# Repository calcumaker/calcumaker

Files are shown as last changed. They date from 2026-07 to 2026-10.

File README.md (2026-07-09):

# Calcumaker 16



> Repo: `calcumaker` · Product: **Calcumaker 16** (see [`NAMING.md`](NAMING.md))

A wide-format, full-size **Cherry MX** **programmer's / technical RPN
calculator**. It carries the HP-16C tradition — hexadecimal / octal / binary /
decimal entry, bitwise operators, and selectable word sizes — and extends it far
past what any single Voyager could do, with **arbitrary-precision** math: **GNU
MP** for big integers, **MPFR** for correctly-rounded floating-point and
transcendentals, and **MPC** for complex numbers. The 16C is the grounding
default (a faithful programmer's machine — `√-1` is `Error 0`, just like the
real one); switchable **personalities** (16C / 15C / SCI / FIN) and a SETUP menu
turn on the scientific and complex features on top. The top of the RPN stack is
shown live on a **multi-row 7-segment display** (2–3 rows) that mounts on its
**own angled PCB**. Battery + USB-C powered; a low-power STM32 keeps it alive
between keystrokes.

> Real keyswitches, a real stack you can see, and answers that are correct to as
> many digits as you ask for.

## Features

- **Programmer's RPN core (HP-16C lineage):** HEX/DEC/OCT/BIN modes, bitwise and
  shift/rotate ops, selectable word size, two's-complement / unsigned / one's-
  complement integer modes.
- **Arbitrary precision (single math path — no fallback):**
  - **GNU MP (libgmp)** — unbounded integers (huge hex/decimal, exact bitwise).
  - **MPFR (libmpfr)** — correctly-rounded floating point + transcendentals
    (sin/cos/exp/ln/…) at user-selectable precision.
  - **MPC (libmpc)** — arbitrary-precision **complex numbers** (HP-42S/15C model:
    one stack object, rectangular `a+bi` or polar `r∠θ`, complex-aware functions,
    CPXRES auto-promotion so `√-4 → 2i`). Off on the 16C, on for the scientific
    personalities and toggleable in SETUP.
  - Packaged as the **`calcumaker-core`** library (`no_std`) over our own
    **`gmp-mpfr-nostd`** FFI bindings — host-testable and runnable today
    (`cargo test`, `cargo run --example repl`).
- **Switchable personalities:** **16C** (programmer, the grounding default),
  **15C** (advanced scientific — the one that natively had complex), **SCI**
  (general scientific), **FIN** (HP-12C-style financial) — one keyboard, chosen
  in SETUP, each just a keymap + defaults over the same superset engine.
- **Field updates over USB-C:** flash new firmware with `dfu-util` via the STM32
  ROM DFU bootloader (`make dfu`) — no ST-Link needed; BOOT0 is the backup.
- **Host emulator:** `calcumaker-emu` runs the whole device UI — keymap, f/g
  shifts, digit entry, the multi-row 7-seg display rendered from the real
  TM1640 segment bytes — on a standard terminal (`cargo run`).
- **Visible RPN stack:** multi-row 7-segment display (2–3 rows) shows the top of
  the stack at once.
- **Split design:** the display lives on its **own PCB** that angles upward;
  only power, the display serial bus, and optional aux-display I²C cross the FFC
  to the MCU board — which keeps wiring simple.
- **Full-size Cherry MX keyswitches:** a wide, tactile, technical-use keypad.
- **Battery + USB-C:** 1S Li-ion with USB-C charging + buck-boost rail; aggressive
  sleep between keypresses for long runtime.
- **Rust firmware:** `no_std` main loop on the **STM32U575RGT6** (Cortex-M33,
  1 MB / 768 KB, ULP — see `DESIGN.md`).

## Hardware Stack

Calcumaker 16 is a three-board KiCad 10 design:

- **`calcumaker-mcu`** is the bottom brain/PSU board: STM32U575, USB-C power and
  charging, the 3V3 rail, the gated 5V display rail, SWD, clocking, the display
  FFC connector, and the keyboard mezzanine.
- **`calcumaker-keyboard`** is the top/front-panel board: 49 Cherry MX keys (a 2U ENTER),
  per-key diodes, annunciator LEDs, and a small STM32G0 keyboard scanner that
  reports key events to the U575 instead of routing the raw matrix across the
  stack.
- **`calcumaker-display`** is the angled display board: three repeated 16-digit
  7-segment rows driven by TM1640s, plus the display FFC and optional aux OLED
  socket.

The schematics are generated from per-board manifests under `hardware/scripts/`
and then placed/wired in KiCad. The display board uses a fully wired
multi-channel row sheet; the MCU and keyboard boards carry the generated sheet
structure plus on-canvas wiring notes. See [`hardware/README.md`](hardware/README.md)
and [`DESIGN.md`](DESIGN.md) for the current hardware source of truth.

## Architecture

```
   DISPLAY BOARD (calcumaker-display) — angled, cabled to the MCU board
   ┌──────────────────────────────────────────────────┐
   │  7-segment RPN stack: 3 rows × 16 digits (2–3 on) │
   │   48× FJ5161AH 0.56" single-digit CC (THT)        │
   │   3× TM1640 driver (1 per row, 2-wire bus)        │
   └──────────────────────────────────────────────────┘
       │ 12-position 0.5mm FFC: +5V, GND, CLK + DIN×3
       │ (5V logic) + 3V3/I²C for the aux OLED — cables down to the MCU board
       ╧
   KEYBOARD BOARD (calcumaker-keyboard) — TOP of stack, keys face up
   ┌──────────────────────────────────────────────────┐
   │  full-size Cherry MX key matrix (+ per-key diode) │
   │  STM32G0 scanner + annunciator LEDs (f g C G lo-b)│
   └──────────────────────┬┬──────────────────────────┘
     low-profile Hirose DF40 mezzanine (0.4mm, 1.5mm stack) + standoffs
        ││  I²C + UART + KB_IRQ (wake) + 3V3/GND  (matrix stays on the G0)
   MCU BOARD (calcumaker-mcu) — BOTTOM of stack
   ┌──────────────────────┴┴──────────────────────────┐
   │  EN-gated 5V boost ──► display │ 74HCT125 (3V3→5V)│
   │   ┌───────────────────────────────────────────┐   │  USB-C ── console /
   │   │ STM32U575RGT6 (Cortex-M33, 1MB/768KB, ULP) │   │          provisioning
   │   │  Rust no_std main loop (embassy)           │   │
   │   │   calcumaker-core: RPN engine              │   │
   │   │        └ GMP + MPFR  (single path)         │   │
   │   │   heap: embedded-alloc (TLSF)              │   │
   │   └────────────────────────────────────────────┘   │
   └───────┬───────────────────────────────────────────┘
           │ VSYS
   1S Li-ion ── USB-C charger ── load-share ── VSYS ──┬── buck-boost → 3V3 (MCU, ULP)
                                                      └── 5V boost (EN-gated) → display
```

## Firmware Stack

The firmware is deliberately split so there is one calculator and multiple thin
I/O bindings around it:

```
   host terminal                         STM32U575 firmware
   ┌─────────────────────┐               ┌─────────────────────┐
   │ calcumaker-emu      │               │ calcumaker-fw       │
   │ crossterm UI        │               │ no_std / embassy    │
   │ host keys + ASCII   │               │ keyboard link +     │
   │ 7-seg rendering     │               │ TM1640 bus + heap   │
   └──────────┬──────────┘               └──────────┬──────────┘
              │                                     │
              └──────────────┬──────────────────────┘
                             │
                    ┌────────▼────────┐
                    │ calcumaker-core │
                    │ Calc + App +    │
                    │ keys + seg7     │
                    └────────┬────────┘
                             │
                    ┌────────▼────────┐
                    │ gmp-mpfr-nostd  │
                    │ Integer + Float │
                    └────────┬────────┘
                             │
          host system GMP/MPFR or target cross-built GMP/MPFR
```

- **`gmp-mpfr-nostd`** is the math FFI layer: `no_std` + `alloc` wrappers for
  GMP integers and MPFR floats. On the host it links system/Homebrew GMP+MPFR;
  on the MCU it links the cross-built static libraries.
- **`calcumaker-core`** is the calculator: RPN stack, exact integer/programmer
  operations, MPFR real math, modes, keymap and f/g shift layers, entry editing,
  errors, and TM1640 7-segment byte generation. This crate is the single numeric
  path: no `rug`, no `std`, no pure-Rust fallback.
- **`calcumaker-emu`** runs the same `App` on a desktop terminal. It maps host
  keys to the physical matrix and renders the real segment bytes as 7-segment
  art, so scripted examples exercise the same key handling and display pipeline
  the device uses.
- **`calcumaker-fw`** is the U575 board binding: heap setup, power/display
  bring-up, keyboard event intake, and the TM1640 bus. The keyboard board's G0
  firmware owns matrix scan, debounce, wake/IRQ, and annunciator drive; the U575
  consumes `(row,col)` key events and feeds them to `calcumaker_core::App`.

Useful firmware entry points:

```sh
cd firmware/calcumaker-core
cargo test
cargo run --example repl

cd ../calcumaker-emu
cargo run
cargo run -- --press "2;3+"

cd ../..
firmware/scripts/build-gmp-mpfr-arm.sh
```

Host engine tests, the token REPL, and the terminal emulator work today against
the real GMP/MPFR libraries. The target GMP/MPFR build is cross-built and
link-verified; remaining firmware work is MCU/HAL bring-up, newlib/libm link
cleanup, heap routing for GMP allocations, and the keyboard-G0 firmware.

## Repository Structure

```
calcumaker/
├── hardware/                     # PCB design (KiCad 10) — split, three boards
│   ├── lib/                      # project-specific symbols/footprints/3D (shared)
│   │   ├── symbols/ footprints.pretty/ 3dmodels/
│   ├── calcumaker-mcu/           # MCU board (brain/PSU): MCU + PSU + clock + SWD + display-IF + keyboard mezzanine
│   │   ├── calcumaker-mcu.kicad_pro
│   │   ├── (root + mcu / clock / prog / psu / display_if / keyboard_if sub-sheets — generated)
│   │   ├── sym-lib-table · fp-lib-table
│   ├── calcumaker-keyboard/      # keyboard board (stacks above MCU): Cherry MX matrix + annunciators + MCU mezzanine
│   │   ├── calcumaker-keyboard.kicad_pro
│   │   ├── (root + keypad / annunc / main_if sub-sheets — generated)
│   │   ├── sym-lib-table · fp-lib-table
│   ├── calcumaker-display/       # display board (angled, cabled): 7-seg stack + driver + interconnect
│   │   ├── calcumaker-display.kicad_pro
│   │   ├── (root + display_row ×3 / interconnect / aux sub-sheets — generated)
│   │   ├── sym-lib-table · fp-lib-table
│   ├── scripts/                  # schgen engine + per-board manifests, check/render, JLCPCB
│   ├── Makefile                  # PROJECTS = calcumaker-mcu calcumaker-keyboard calcumaker-display
│   ├── LICENSE                   # CERN-OHL-S v2 (hardware)
│   ├── README.md
│   ├── sym-lib-table
│   └── fp-lib-table
├── firmware/
│   ├── gmp-mpfr-nostd/           # own no_std FFI to GMP/MPFR ("rug, but no_std")
│   ├── calcumaker-core/          # the CALCULATOR: engine + keymap + App + 7-seg
│   │   ├── src/                  #   lib, calc, value, format, keys, app, seg7
│   │   ├── tests/ · examples/repl.rs
│   │   └── Cargo.toml            #   single math path (no fallback)
│   ├── calcumaker-emu/           # HOST EMULATOR: the same App on a terminal
│   ├── calcumaker-fw/            # Rust no_std board binary (STM32U575 / embassy)
│   │   ├── Cargo.toml · .cargo/config.toml
│   │   ├── memory.x · build.rs · rust-toolchain.toml
│   │   └── src/                  #   main, keyboard input/link, display (TM1640 bus)
│   ├── scripts/                  # build-gmp-mpfr-arm.sh (cross-build for thumbv8m)
│   ├── common/                   # shared HAL/utilities
│   └── shared/                   # shared protocol/definitions
├── reference/                    # datasheets + dependency pointers
├── DESIGN.md                     # full hardware/firmware design + open questions
├── NAMING.md                     # product naming (Calcumaker 16)
└── LICENSE                       # AGPL-3.0 (firmware)
```

## Key Components

| Component | Part | Status |
|---|---|---|
| MCU | STM32U575RGT6 (1MB/768KB, M33, ULP, LQFP-64) | ✅ selected — LCSC C5270980, JLCPCB Extended |
| Display | 3 rows × 16 digits: 3× TM1640 + 48× FJ5161AH 0.56" CC (THT) | ✅ LCSC C5337152 / C8093 |
| Keys | 5×10 grid, 49 full-size Cherry MX (2U double-height ENTER) + keyboard STM32G0 scanner | electrical/keymap decided; physical layout details still TBD |
| Display interconnect | 12-position 0.5mm FFC: +5V/GND, CLK + DIN×3, 3V3/I²C aux lines | selected in `DESIGN.md`; verify cable length/orientation at layout |
| Power | 1S Li-ion + USB-C charge; **3V3 (TPS63900, MCU)** + **EN-gated 5V boost (display)** | 3V3 ✅; 5V boost + 74HCT125 level shifter TBD (research) |
| Math | GNU MP + MPFR via `calcumaker-core` + own `gmp-mpfr-nostd` (single path) | ✅ no_std, host-tested + REPL + emulator; cross-built + link-verified for the target |

## Status

**The calculator works on the host today**: engine + keymap + display pipeline
are host-tested, and `calcumaker-emu` runs the full device UI on a terminal.
GMP/MPFR are cross-built + link-verified for the STM32 target. **MCU, keypad
layout (5×10), software stack, display BOM, and power architecture are decided** (see
`DESIGN.md` / `hardware/PARTS.md`). The three-board hardware split is in the
repo; the display board is fully wired as a multi-channel KiCad design, while
the MCU and keyboard boards generate from their manifests and still need
eeschema wiring/layout work. Remaining firmware work: U575 MCU bring-up
(embassy + newlib/libm link + heap routing) and the keyboard-G0 scanner
firmware. Battery sizing and fabrication are still ahead.

## License

- **Firmware:** [AGPL-3.0](LICENSE) (compatible with the LGPLv3 GMP/MPFR).
- **Hardware:** [CERN-OHL-S v2](hardware/LICENSE) (strongly reciprocal — matches
  the AGPL copyleft posture).

Copyright (c) 2026 calcumaker authors.

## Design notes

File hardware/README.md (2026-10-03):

# Calcumaker 16 — hardware

KiCad 10 design for the **Calcumaker 16** programmer's / technical RPN
calculator. **Split design** — two stacked PCBs and one of two cabled display variants:

- **`calcumaker-mcu/`** — the brain/PSU board: MCU (STM32U575RGT6), PSU (USB-C
  charge + buck-boost), clock, SWD, the display interconnect (its 5V rail and
  level shifter live on the display module), and a mezzanine to the keyboard. *Bottom of
  the stack.*
- **`calcumaker-keyboard/`** — the front-panel board: the 49-key Cherry MX matrix (2U ENTER)
  + per-key diodes + the annunciator LEDs + the mating mezzanine header.
  *Mezzanine-stacks directly above the MCU board* (keeps a dense LQFP-64 off the
  through-hole key matrix).
- **`calcumaker-display/`** — the multi-row 7-segment RPN stack (2–3 rows) + its
  driver ICs + the interconnect back to the MCU board. Mounts at an upward angle,
  cabled; power, the display serial bus, and optional aux-display I2C cross the
  FFC.
- **`calcumaker-matrix/`** — alternative 96 × 24 addressable-pixel display with
  RP2040 control, USB programming and a dedicated LED power inlet.

See `../DESIGN.md` for the full design and `scripts/README.md` for the
schematic-generation flow. Build docs/BOMs/fab packages with the `Makefile`
(`make help`).

The MCU and keyboard schematics are wired and verified with KiCad 10.0.6.
Run `make check-wiring` for electrical net assertions and ERC validation.
See [WIRING_REVIEW.md](WIRING_REVIEW.md) for the pin maps, reviewed ERC warning,
power corrections, and remaining physical validation. Edit the schematics
directly; forcing the older placement manifests would discard this wiring.

The MCU board also has a [provisional PCB floor plan](calcumaker-mcu/FLOORPLAN.md):
75 placed components in functional groups, local supply bypasses, and a 70 × 50 mm
outline for the cabled configuration. It is unrouted; the placement review records
the remaining mechanical and fabrication-rule decisions.

The keyboard has a [PCB and mechanical plate floor plan](calcumaker-keyboard/FLOORPLAN.md)
with 49 key-cell groups, local RGB bypasses, a centered vertical 2U ENTER and
dedicated `Plate.Cuts`, `Keycaps` and mechanical annotation layers. Run
`make keyboard-plate` to export the separate plate DXF and reference SVG.

Both display variants have grouped, unrouted floor plans:
[48-digit seven-segment](calcumaker-display/FLOORPLAN.md) and
[2,304-pixel matrix](calcumaker-matrix/FLOORPLAN.md). They include local bypasses,
mechanical viewing references and position CSVs. Run `make check-display-wiring`
to check every digit/pixel net and ERC, and `make display-mechanical` to export
window DXFs and reference SVGs. These are provisional mechanical envelopes;
the matrix power path and both boards' remaining part choices require qualification.
All four boards' edited schematics are authoritative over the older manifests.

## Library

`lib/{symbols,footprints.pretty,3dmodels}` holds project-specific parts (shared
by all boards, lib name `calcumaker`); most parts resolve to KiCad bundled
libraries.

## License — Hardware: CERN-OHL-S v2

The hardware (schematics, PCB layouts, and associated design files under
`hardware/`) is licensed under the **CERN Open Hardware Licence Version 2 —
Strongly Reciprocal** (`CERN-OHL-S-2.0`). Full text: [`LICENSE`](LICENSE).
Chosen to match the strong-copyleft posture of the AGPL-3.0 firmware.

**Third-party library parts** (vendored symbols / footprints / 3D models) carry their
own upstream licenses — CERN-OHL-P, MIT, and CC-BY-SA-4.0-with-exception — all of which
are compatible with incorporation into a CERN-OHL-S v2 design. Every one is indexed,
with its source and license, in **[`lib/ATTRIBUTIONS.md`](lib/ATTRIBUTIONS.md)**.

> Copyright (c) 2026 calcumaker authors.
>
> This source describes Open Hardware and is licensed under the CERN-OHL-S v2.
>
> You may redistribute and modify this source and make products using it under
> the terms of the CERN-OHL-S v2 (https://ohwr.org/cern_ohl_s_v2.txt).
>
> This source is distributed WITHOUT ANY EXPRESS OR IMPLIED WARRANTY, INCLUDING
> OF MERCHANTABILITY, SATISFACTORY QUALITY AND FITNESS FOR A PARTICULAR PURPOSE.
> Please see the CERN-OHL-S v2 for applicable conditions.
>
> Source location: https://github.com/calcumaker/calcumaker
>
> As per CERN-OHL-S v2 § 4, if you produce a device using this source, you
> should where practicable keep the above Source Location visible on the device.

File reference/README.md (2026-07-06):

# Reference Material

Pointers to source material and dependencies this project is built from.

## Repo skeleton
Modeled after the sibling BenchBits hardware+firmware repos:
- **`github/ephemerkey/`** — freshest scaffold (KiCad 10, `hardware/` + `scripts/`
  schematic-generation flow, `Makefile`, lib-tables, JLCPCB script, `DESIGN.md`
  style). Closest structural template.
- **`github/notchdeck/`**, **`github/tsumikoro/`** — the same hardware/firmware
  layout and `hardware/scripts/` tooling.

The firmware departs from those (which are C / Zephyr / ESPHome): calcumaker's
main loop is **Rust (no_std)**.

## Firmware dependencies (see DESIGN.md)
- **GNU MP (libgmp)** — arbitrary-precision integers (the HP-16C "programmer"
  side: big hex/dec/oct/bin, bitwise). https://gmplib.org/ (LGPLv3 / GPLv2 dual)
- **MPFR (libmpfr)** — arbitrary-precision floats with correct rounding (the
  scientific side: transcendentals). https://www.mpfr.org/ (LGPLv3)
- **Bindings: our own `firmware/gmp-mpfr-nostd/`** — thin `no_std` FFI to
  GMP/MPFR (*like `rug`, but no_std*). Host links system GMP/MPFR (`brew install
  gmp mpfr`); target links cross-built. **Single math path — no pure-Rust
  fallback, no `rug`/`std` in the engine.**
- For the target: cross-built GMP/MPFR (`--host=arm-none-eabi --disable-assembly`
  + picolibc); see DESIGN.md → "GMP/MPFR on the target".
- Embedded Rust: **embassy-stm32** (async HAL), **cortex-m** / **cortex-m-rt**,
  **embedded-alloc** (heap for the bignum allocator), **probe-rs** (flash/debug).

## Datasheets (download into this folder via the `digikey`/`datasheets` skills)
Populate as the layout moves toward fabrication. Current expected set:

| Block | Part | Notes |
|---|---|---|
| MCU | STM32U575RGT6 (LCSC C5270980) | flash/RAM, low-power modes, USB FS, FPU, AF map, SRAM banking |
| Keyboard scanner | STM32G031K8U6 (LCSC C432207) | GPIO, Stop/EXTI wake, I2C/UART, package |
| Display driver | TM1640 (LCSC C5337152) | digit/segment drive, current set, 2-wire interface |
| 7-seg display | FJ5161AH (LCSC C8093) | 0.56 in single-digit common-cathode THT, pinout |
| Display FFC | AFC01-S12FCA-00 + GCT FFC05-TIN cable | 0.5 mm 12-position connector/cable orientation and current |
| Keyboard mezzanine | Hirose DF40C-10DS/DP-0.4V | stack height, land pattern, 3D clearance |
| Keyswitch | Cherry MX (full size) | mechanical/electrical, hot-swap socket option |
| Power | USB-C charger, TPS63900 3V3, TPS61022 5V boost, SN74HCT125 level shifter | charge current, Iq, input range, boost sizing, logic thresholds |
| Battery | 1S Li-ion/LiPo | capacity, protection |

> Use the `digikey`/`datasheets` skills to populate this folder, then the
> `kicad`/`emc`/`spice` analyzers can consume verified specs.

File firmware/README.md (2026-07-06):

# calcumaker firmware

Rust firmware for the Calcumaker 16 programmer's / technical RPN calculator.

## Layout

```
firmware/
├── gmp-mpfr-nostd/    # own no_std FFI bindings to GMP/MPFR (Integer + Float).
│   │                  #   "Like rug, but for a no_std world." Links system libs
│   │                  #   on host, cross-built libs on target.
│   └── src/           #   lib · ffi · integer · float
├── calcumaker-core/   # the CALCULATOR — everything device-independent:
│   │                  #   engine (RPN + arbitrary precision, SINGLE math path),
│   │                  #   keymap + f/g shift layers (keys), key handling +
│   │                  #   entry editing (App), 7-seg encoding (seg7).
│   ├── src/           #   lib · calc · value · format · keys · app · seg7
│   ├── tests/         #   engine + app + seg7 tests against real GMP/MPFR
│   └── examples/repl.rs
├── calcumaker-emu/    # HOST EMULATOR — the same App on a terminal; ASCII 7-seg
│   └── src/           #   rendered from the real TM1640 segment bytes.
├── calcumaker-fw/     # the embedded binary (Cortex-M33, no_std): board bring-up
│   └── src/           #   main · keyboard event intake · display (TM1640 bus)
├── scripts/           # build-gmp-mpfr-arm.sh — cross-build GMP+MPFR for thumbv8m
├── vendor/            # cross-built libgmp.a/libmpfr.a land here (gitignored)
├── common/            # shared HAL / board glue (reserved)
├── shared/            # shared protocol / definitions (reserved)
└── LICENSE            # (repo LICENSE is AGPL-3.0)
```

## The calculator is real and testable today

`calcumaker-core` uses **GNU MP + MPFR** through our own `no_std` bindings
(`gmp-mpfr-nostd`). On the host they link the system libraries, so it's a normal
library you develop and test on the desktop (builds in <1 s):

```bash
brew install gmp mpfr      # one-time host deps (apt: libgmp-dev libmpfr-dev)
cd calcumaker-core
cargo test                 # engine + app + 7-seg tests vs real GMP/MPFR
cargo run --example repl   # token RPN REPL against the engine
```

And the whole device UI runs on a terminal — see `calcumaker-emu/README.md`:

```bash
cd calcumaker-emu
cargo run                       # interactive emulator (? = key map)
cargo run -- --press "2;3+"     # scripted keys → prints the final frame
```

The core is `#![no_std]`; the *same* crate also compiles for the MCU
(`cargo build --target thumbv8m.main-none-eabihf`).

There is **one** numeric path — no `numeric-gmp`/`numeric-pure` feature split,
no pure-Rust fallback — and **one** UI path: firmware and emulator are thin I/O
bindings (keyboard events / host keys in, TM1640 bytes / ASCII art out) around
the same `App`.

## The embedded crate

`calcumaker-fw` is the U575 board binary: heap, power/display bring-up,
keyboard event intake from the keyboard-board STM32G0, and the TM1640 display
bus. It builds and links for `thumbv8m.main-none-eabihf` today (the default
target in its `.cargo/config.toml`).

GMP + MPFR are **cross-built + link-verified** for the target
(`scripts/build-gmp-mpfr-arm.sh` → `vendor/gmp-mpfr-arm/`; `build.rs` links
them when `GMP_MPFR_LIBDIR` is set). Remaining bring-up (tracked in
`../DESIGN.md`): embassy clocks/GPIO, newlib libc/libm at the final link, and
routing GMP's allocator to the firmware heap, plus the keyboard-G0 firmware and
link protocol. Then the main loop is exactly what the emulator runs:
`app.press(row, col)` → `display.render(&app.seg_rows())`.

## License

AGPL-3.0 (see `../LICENSE`). GMP and MPFR are LGPLv3 — compatible.

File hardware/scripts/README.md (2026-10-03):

# hardware/scripts

Tooling for the calcumaker KiCad project (shared with the sibling BenchBits
repos). Driven via the `Makefile` (preferred) or run directly. All locate
`kicad-cli` via `$KICAD_CLI`, then `PATH`, then the macOS app bundle
(`/Applications/KiCad/KiCad.app/...`).

| Script | Make target | What it does |
|---|---|---|
| `<project>.schgen.py` | `make gen-<project>` | Regenerate the hierarchical schematic from a data manifest. |
| `kschgen.py` | — | Generic generation engine imported by the `*.schgen.py` manifests. |
| `kicad-sch-check.py` | `make check-<project>` | Sanity-check a schematic: component count, missing footprints, duplicate refs, ERC tally. Exits non-zero on a structural problem. |
| `check-wiring.py` | `make check-wiring` | Export MCU/keypad netlists; verify connector parity, matrix polarity, LED chain, MCU/power/debug nets and reviewed ERC results. Fails on unexpected ERC violations. |
| `check-display-wiring.py` | `make check-display-wiring` | Verify all 48 digits, 2,304 pixels, 288 pixel bypasses, supply separation, USB, host interface, boot/debug nets and reviewed ERC results. |
| `kicad-sch-render.sh` | `make render-<project>` | Render schematic sheet(s) to PNG for a quick visual review. |
| `jlcpcb-package.sh` | `make jlc-<project>` | Gerbers + drill + BOM + CPL → JLCPCB zip. |

## Generating a schematic from a manifest

**All four boards' committed schematics are now wired and authoritative.** The
manifests below retain the earlier placement draft; do not force regeneration
over the edited sheets. See [the wiring review](../WIRING_REVIEW.md).
Make targets use `uv run python` (`PYTHON_RUN` can override it).

`scripts/<project>.schgen.py` is **data**: it registers the symbol libraries the
board uses, lists the components per hierarchical sheet (ref / lib_id / value /
footprint / LCSC / MPN / ...), and adds a free-text wiring note per sheet. The
reusable logic lives in `kschgen.py`, which hand-authors KiCad-10 schematic files
(root sheet of hierarchical sheet symbols + one child `.kicad_sch` per block,
every part resolving to a real library symbol + footprint, `extends`-derived
symbols handled).

Calcumaker 16 is a **split design** — one manifest per board:
`calcumaker-mcu.schgen.py`, `calcumaker-keyboard.schgen.py`, and
`calcumaker-display.schgen.py`.

```sh
make gen-calcumaker-mcu        # rewrite the MCU-board sheets from its manifest
make check-calcumaker-keyboard # verify a board
make render-calcumaker-display # eyeball a board's sheets
```

The draft manifests produce components **placed, not wired** — laid out on a 100-mil grid with refs,
values, footprints and a per-sheet wiring note. Wiring is done afterwards in
eeschema (the notes are the spec). By default, re-running `gen` creates missing
sheets and keeps existing `.kicad_sch` files intact, reusing their UUIDs in
project metadata. Use `KSCHGEN_FORCE=1 make gen-<project>` only when you
intentionally want to rebuild generated sheets from the manifest.
Notes render in a fixed-width font; use `K.note_block()` and `K.pin_table()` in
manifests when writing pin maps or wiring tables that need alignment.

> **Status:** the manifests remain guarded drafts until the open layout/part
> checks are resolved. The display manifest and the keyboard **matrix + per-key
> RGB** are fully wired **multi-channel** designs (a reusable row instantiated
> N×); the rest of the MCU/keyboard sheets generate placed-not-wired structure +
> on-canvas wiring notes. They refuse to run unless `CALCUMAKER_SCHGEN_DRAFT_OK=1`
> is set; regenerating placed-not-wired boards also needs `KSCHGEN_FORCE=1`.

## Notes

- `kicad-sch-render.sh` converts SVG→PNG with the first available of
  `rsvg-convert` / `inkscape` / `cairosvg` / macOS `qlmanage`. Output goes to a
  temp dir (override with `$RENDER_OUT`); pass sheet name(s) to render a subset.
- `extends`-based library symbols draw correctly in eeschema but may render
  body-less via `kicad-cli` and show a benign `lib_symbol_mismatch` in ERC until
  first saved in eeschema (or **Tools → Update Symbols from Library**).

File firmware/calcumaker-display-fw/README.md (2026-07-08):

# calcumaker-display-fw

Firmware for the **7-segment display module** (`hardware/calcumaker-display`): an
**STM32G031K8U6** that is an SPI slave to the calculator's U575. It receives a
[`calcumaker-display-proto::DisplayFrame`](../calcumaker-display-proto) over the
unified connector, encodes the text rows to 7-seg bytes, and bit-bangs the 3
TM1640s (driven at 5 V through the on-board 74HCT125).

- Target: `thumbv6m-none-eabi` (STM32G031, Cortex-M0+). `embassy-stm32`.
- Build: `cargo build --release`. Flash: `cargo run --release` (probe-rs on the
  J3 SWD Tag-Connect). Dev logging over RTT: `--features dev`.

## Status — SCAFFOLD

Real: the TM1640 bit-bang driver (`tm1640.rs`) and the 7-seg render (`render.rs`).
Stubbed: **`recv_frame`** in `main.rs` — SPI1 slave + DMA of `WIRE_LEN` bytes;
currently returns a self-test frame. Pins in `main.rs` are placeholders — align
them with the wired `disp_mcu` schematic sheet. `render.rs` duplicates
`core::seg7`'s glyphs (so this crate needn't link the GMP-bearing engine); TODO:
split `core::seg7` into a shared crate.

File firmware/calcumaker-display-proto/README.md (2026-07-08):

# calcumaker-display-proto

The **display-module wire protocol** — the "display intent" frame the calculator's
U575 (`calcumaker-fw`) sends over SPI, and that each display module renders
locally:

- the 7-seg module (`calcumaker-display-fw`, STM32G031), and
- the RGB-matrix module (`calcumaker-matrix-fw`, RP2040).

`DisplayFrame` carries text rows + annunciator/mode flags + aux-OLED content — a
display-agnostic *intent*, not raw driver bytes — so one frame serves any display
and a new display is just a new module (no MCU-board change). Fixed-length wire
form (`WIRE_LEN`, magic + version + XOR checksum) so a slave can DMA a constant
transfer.

Pure `no_std`, **no dependencies**, host-testable: `cargo test`.

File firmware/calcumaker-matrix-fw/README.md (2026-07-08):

# calcumaker-matrix-fw

Firmware for the **RGB dot-matrix display module** (`hardware/calcumaker-matrix`):
an **RP2040** that is an SPI slave to the calculator's U575. It receives a
[`calcumaker-display-proto::DisplayFrame`](../calcumaker-display-proto) over the
unified connector, renders the text rows into a 96×24 pixel framebuffer, and
streams it to the 2304× XL-1010 (WS2812) array over 3 PIO-driven data chains.

- Target: `thumbv6m-none-eabi` (RP2040, Cortex-M0+). `embassy-rp`.
- Build: `cargo build --release`. Flash: `cargo run --release` (probe-rs/SWD) or
  drag-drop the UF2 over USB **BOOTSEL**.
- Dev logging over RTT: `--features dev`.

## Status — SCAFFOLD

Real: the framebuffer + 5×7 font blitter (`font.rs`) and the frame decode path.
Stubbed (the bring-up work):

- **`ws2812.rs`** — the PIO WS2812 driver (3 SMs + DMA, GRB, serpentine mapping)
  is a no-op `flush`. This is the headline task; the RP2040 was chosen *for* its
  PIO.
- **`recv_frame`** in `main.rs` — SPI0 slave + DMA of `WIRE_LEN` bytes; currently
  returns a self-test frame.

⚠ **Brightness cap is mandatory** — 2304 WS2812 at full white is many amps. VLED
comes from the dedicated VSYS inlet (J2) via the `LED_EN` gate; keep colours dim
and enforce a global current budget. Pins in `main.rs` are placeholders — align
them with the wired `rp2040`/`rgb_power` schematic sheets.

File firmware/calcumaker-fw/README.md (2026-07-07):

# calcumaker-fw

Rust **`no_std`** board firmware for the Calcumaker 16 MCU board
(`STM32U575RGT6`, Cortex-M33).

This crate is not the calculator engine. The calculator lives in
[`../calcumaker-core`](../calcumaker-core): RPN stack, GMP/MPFR math, keymap,
entry editing, modes, errors, and TM1640 segment-byte generation. This crate is
the hardware binding around that core: heap setup, MCU/HAL bring-up, keyboard
event intake from the keyboard-board G0, and the display bus.

## Modules

| Module | Role |
|---|---|
| `main.rs` | Heap init, GMP/MPFR C-alloc shim, and the async entry on embassy's **low-power executor**; runs the self-test then hands off to USB. |
| `clock.rs` | RCC config: 160 MHz SYSCLK (PLL1-R/HSI), 48 MHz USB (HSI48+CRS), LSI for the RTC. Shared by both boards. |
| `usb.rs` | USB OTG_FS **composite device**: CDC-ACM console wired to a live RPN REPL over `calcumaker_core`, + a HID keyboard that types the X value to the host. |
| `bootloader.rs` | Enter the STM32 ROM USB-DFU bootloader for field updates (option-byte boot pattern, see below). |
| `selftest.rs` | Golden-case engine self-test (see the validation target below). |
| `keypad.rs` | Provisional keyboard-event intake. The real matrix scan/debounce/IRQ lives on the keyboard board's STM32G0 firmware; the U575 consumes `(row,col)` events. |
| `display.rs` | TM1640 bus driver skeleton for the multi-row 7-segment display. |

## MCU bring-up (embassy-stm32)

The crate runs on `embassy-stm32` (async). Brought up and **validated on the
Nucleo-U575ZI-Q**:

- **Clocks** (`clock.rs`): 160 MHz SYSCLK, 48 MHz crystal-free USB clock (HSI48
  CRS-trimmed to the USB SOF), LSI enabled for the RTC.
- **USB** (`usb.rs`): an IAD composite device on OTG_FS (PA11/PA12,
  `vbus_detection=false`). Interface 0/1 = CDC-ACM, a full RPN REPL over the real
  engine (`2 3 +` → `5`, `float 2 sqrt` → 256-bit MPFR, `100 !` → the 158-digit
  factorial); interface 2 = a HID keyboard — the `type` command taps the current
  X value to the focused host app.
- **Low power**: uses embassy's low-power executor, so the part enters the
  deepest sleep the peripheral **stop-refcounts** allow when idle. USB OTG is
  `stop_mode=Stop1`, so while the console is enumerated it stays in Sleep (WFI,
  USB-safe) and wakes on USB activity; deeper STOP is only reached once USB is
  gated. **Deferred:** STOP2-with-timekeeping needs an RTC time driver that
  embassy-stm32 0.6 doesn't yet provide for the U5 (its LPTIM driver miscompiles
  against the current metapac), and a dedicated VBUS-EXTI wake-on-plug source —
  both revisited on an embassy bump / with the production board's VBUS routing.

## Calculator Core

There is one numeric path: **GNU MP + MPFR** through the repo's
`gmp-mpfr-nostd` crate. No `numeric-pure`/`numeric-gmp` feature split, no
pure-Rust fallback, and no `std`/`rug` in the engine.

On the host, `calcumaker-core` links system GMP/MPFR and is tested directly:

```bash
cd ../calcumaker-core
cargo test
cargo run --example repl
```

For the target, GMP/MPFR are cross-built out of tree and linked by this crate's
`build.rs` when `GMP_MPFR_LIBDIR` points at the install prefix:

```bash
cd ../..
firmware/scripts/build-gmp-mpfr-arm.sh
GMP_MPFR_LIBDIR=firmware/vendor/gmp-mpfr-arm \
  cargo build --manifest-path firmware/calcumaker-fw/Cargo.toml --target thumbv8m.main-none-eabihf
```

## Firmware update over USB-C (no ST-Link)

Field updates use the **STM32 ROM USB-DFU bootloader** — single flash slot (the
app owns `0x08000000`+), no custom bootloader, no A/B partitions.

```bash
make dfu     # build → enter ROM DFU → dfu-util flash → restore boot → app
```

How it works (`bootloader.rs` + `scripts/dfu-flash.sh`):
1. The app's **`dfu`** REPL command programs the boot option bytes
   (`nSWBOOT0=0, nBOOT0=0`) and sets `OBL_LAUNCH`, resetting straight into the
   ROM DFU device (`0483:df11`). *(A naive jump to system memory `0x0BF90000`
   HardFaults on the U5; the RM-defined boot-pattern entry is what works.)*
2. `dfu-util` writes the new firmware to internal flash (alt 0), then **rewrites
   the boot option bytes back** (`OPTR` → boot main flash, alt 1) — the same DFU
   session clears the flags it set — which resets into the new app.

Physical **BOOT0** high at reset reaches the same ROM DFU as a hardware backup.

`dfu-util` / `probe-rs` need USB access. Install the versioned udev rule once for
sudo-free access to the ST-Link, the ROM DFU (`0483:df11`), and the app:

```bash
sudo cp ../scripts/70-calcumaker.rules /etc/udev/rules.d/
sudo udevadm control --reload-rules && sudo udevadm trigger --subsystem-match=usb
```
(Without it, run `make dfu` with `DFU_UTIL="sudo dfu-util"`.)

## Nucleo-U575ZI-Q validation target

A permanent, non-production **validation target**: the same firmware, flashed to
an off-the-shelf **Nucleo-U575ZI-Q** (STM32U575ZIT6Q — a 2 MB/144-pin sibling of
the production RGT6). It has no keyboard matrix or display, so `main` runs the
shared engine **self-test** (`src/selftest.rs`) — golden RPN cases whose results
were captured from the host engine — and streams PASS/FAIL over **RTT (defmt)**
through the board's on-board ST-LINK-V3. This proves the cross-built on-target
GMP/MPFR reproduces the host results *byte-for-byte* (MPFR is deterministic at a
fixed precision/rounding), i.e. the whole arbitrary-precision stack computes
correctly on real U5 silicon.

Everything is shared with the production image. The `nucleo` cargo feature swaps
the panic handler (`panic-halt` → `panic-probe`), turns on the defmt result
logging (compiled out otherwise, via the `log_info!`/`log_error!` shim in
`main.rs`), and selects the ZI chip. The linker memory map comes from
embassy-stm32's `memory-x` per chip (RG = 1 MB, ZI = 2 MB), so only the chip
feature + flash-time `--chip` differ between the two boards.

After the self-test the Nucleo image brings up USB, so the board enumerates as a
composite CDC-ACM + HID keyboard device you can drive interactively (see *MCU
bring-up* above).

```bash
# from this crate dir (GMP_MPFR_LIBDIR defaults to ../vendor/gmp-mpfr-arm):
make run-nucleo     # build + flash + stream the self-test over RTT (Ctrl-C to detach)
make build-nucleo   # build only
make check-nucleo   # type-check the nucleo config
```

Requires `probe-rs >= 0.24` (decodes the defmt v4 wire format; **0.31** verified).
`make build` (default features) still produces the production RGT6 link-smoke
image with logging compiled out.

## Bring-Up Status

Done + validated on hardware (Nucleo-U575ZI-Q): the full GMP/MPFR engine
cross-compiles/links and computes correctly on-target, 160 MHz clocks, the USB
composite (CDC-ACM REPL + HID keyboard), and low-power-executor Sleep with
USB-gated STOP.

Remaining board bring-up: the keyboard-G0 link protocol (matrix `(row,col)`
intake), the real TM1640 bit-bang display driver, routing GMP allocations
through `mp_set_memory_functions` (vs. the current global-heap malloc shim),
deep STOP2 + VBUS wake (see *MCU bring-up* deferrals), and moving the engine off
the USB REPL onto the shared `App`. See [`../../DESIGN.md`](../../DESIGN.md) for
the full firmware checklist.

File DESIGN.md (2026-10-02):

# Calcumaker 16 — Design Document

> Repo: `calcumaker` · Product: **Calcumaker 16** (see `NAMING.md`).
> Future personalities / HP-variant modes are **planned** (not implemented)
> in [`DESIGN-MODES.md`](DESIGN-MODES.md).

## Overview

**Schematic status (2026-10-02):** the MCU and keyboard boards are now wired,
including sheet connections, power, reset/debug and the 49-key/RGB chain.
The authoritative pin map, corrections and validation results are recorded in
[`hardware/WIRING_REVIEW.md`](hardware/WIRING_REVIEW.md). Run
`make -C hardware check-wiring`. The committed schematics supersede the guarded
placement manifests; do not force regeneration. PCB layout, RGB voltage/logic
headroom and final cell/connector/inductor selection remain open.

Calcumaker 16 is a wide-format, full-size **Cherry MX** **programmer's /
technical RPN calculator**. It follows the **HP-16C** lineage — hexadecimal /
octal / binary / decimal entry, bitwise and shift/rotate operators, and
selectable word sizes — and extends it with **arbitrary-precision** math:

- **GNU MP (libgmp)** for unbounded integers (the programmer side: huge
  hex/decimal values, exact bitwise);
- **MPFR (libmpfr)** for correctly-rounded floating point and transcendental
  functions (the scientific side), at user-selectable precision.

The top of the RPN stack is shown on a **multi-row 7-segment** display (**2–3
rows**) carried on its **own angled PCB** — part of a **three-board split**
(MCU board + keyboard board stacked on a mezzanine, + the angled display board);
only power and the display serial bus cross that interconnect. The device is
**battery + USB-C** powered, on the **low-power STM32U575**. The firmware main
loop is **Rust (`no_std`)**.

This document is the source of truth for the hardware and firmware design. It
follows the structure of the sibling BenchBits repos (ephemerkey / notchdeck /
tsumikoro). The repo's firmware departs from those (which are C / Zephyr) by
being Rust.

---

## Resolved Decisions (from project kickoff)

| # | Decision | Choice |
|---|---|---|
| 1 | Math stack | **GMP + MPFR only — single path, no fallback.** Engine = `calcumaker-core` over our own no_std bindings `gmp-mpfr-nostd` (host: links system GMP/MPFR; target: cross-built). One `no_std` crate, host-tested + REPL. |
| 2 | Power | **1S Li-ion + USB-C charging + buck-boost**; "low power" = long battery life via aggressive sleep between keystrokes. Charger = **BQ25601** (3 A sync buck + NVDC power path, I²C) with the **Type-C CC advertisement read on an ADC** → up to **3 A** in (revised 2026-07-12 from MCP73831 + discrete load-share). |
| 3 | Display | **Stacked RPN registers, 2–3 rows (option)** — multi-row 7-segment showing the top of the stack. Driver + digit parts chosen by LCSC price/availability. |
| 4 | Keypad | **Wide HP-16C-style layout** for programming / technical / engineering use; full-size Cherry MX. |
| 5 | Firmware language | **Rust, `no_std`** main loop (async via embassy once MCU is pinned). |
| 6 | Firmware license | **AGPL-3.0** (repo LICENSE) — compatible with LGPLv3 GMP/MPFR. |
| 7 | MCU | **STM32U575RGT6** (Cortex-M33, **1 MB** / 768 KB, **LQFP-64**, ULP) + **4 MB quad-SPI NOR on OCTOSPI1**. Firmware measured ~323 KB → 1 MB is ample; the matrix scans off-board so LQFP-64 has enough GPIO (smaller/cheaper). Same U575 die (USB FS, OCTOSPI, GMP/MPFR-capable). LCSC C5270980. Target `thumbv8m.main-none-eabihf`. |
| 8 | Board partition | **Three boards: `calcumaker-mcu` + `calcumaker-keyboard` (DF40 mezzanine-stacked above it) + `calcumaker-display` (angled, 0.5 mm FFC).** Keeps a dense LQFP-64 off the 49-key through-hole matrix. The keyboard has its **own STM32G0 scanner**, so only an **I²C+UART link + power** cross the mezzanine (not the raw matrix); the display bus + power cross the FFC. |
| 9 | Hardware license | **CERN-OHL-S v2** (`hardware/LICENSE`) — strongly reciprocal, matches the AGPL copyleft posture. |
| 10 | Product name | **Calcumaker 16** (see `NAMING.md`). |

---

## Architecture Decisions

### MCU: large-flash / low-power STM32 (Cortex-M4F or M33)

The dominant sizing driver is the arbitrary-precision math. GMP + MPFR together
are on the order of **~0.5–1 MB of flash**, but their heap needs are **modest**
for a calculator — even very high working precision is a few KB per value, so a
4-level stack plus registers and MPFR scratch is comfortably in the **tens of
KB**. So the real constraint is **flash ≥ ~1–2 MB** (to keep the real GMP/MPFR
option open); **~128–320 KB RAM is plenty**. An FPU helps the (mostly software)
multi-precision arithmetic at the margins and is standard on the candidates.
Low power and a USB FS device (console / provisioning) round out the list.

> **Cost matters — this is a calculator, not a workstation.** The 4 MB / 3 MB
> top-end U5 (U5G9) is far more part than this needs and is expensive; it has
> been dropped as the headline pick.

**SELECTED: STM32U575RGT6 (Cortex-M33, 1 MB flash / 768 KB SRAM, LQFP-64, ULP),
plus a 4 MB quad-SPI NOR on OCTOSPI1.** Same U575 die (FPU + USB FS + OCTOSPI +
TrustZone, ST's current ULP line), chosen on **availability + fit**: the L4R5 is
effectively unavailable (~5 pcs), while the U575 family is well stocked and
GMP/MPFR-capable. The **firmware links at ~323 KB** (full engine + GMP + MPFR,
*measured* — see Numeric core), so **1 MB flash is ample (~3× headroom)** — no
need for the pricier/scarcer 2 MB `I` parts. With the **key matrix scanned
off-board** (the keyboard G0), the MCU needs far fewer GPIO, so the smaller
**LQFP-64 (10×10 mm)** fits — cheaper and suited to the low-profile stack. A
**4 MB (32 Mbit) quad-SPI NOR** (W25Q32JVSSIQ, LCSC C179173) on **OCTOSPI1** adds
memory-mapped (XIP) storage for constant tables + state persistence / future
keystroke programs. Target `thumbv8m.main-none-eabihf`; HAL `embassy-stm32`
(`stm32u575rg`).

> **Flash-code gotcha:** the STM32 `G` size code = **1 MB** (the `I` parts are
> 2 MB). Earlier notes mislabeled the ZGT6 as "2 MB"; the ZGT6/VGT6/RGT6 are all
> **1 MB** — which the measured 323 KB firmware fits with room to spare.

**Availability ladder (live LCSC/JLCPCB via jlcsearch; all JLCPCB "Extended"):**

| Part | LCSC# | Pkg | Flash / RAM | Stock | Fit |
|---|---|-----|---|---|-----|
| **STM32U575RGT6** | C5270980 | LQFP-64 (10×10) | 1 MB / 768 KB | 345 | ✅ selected — smaller pkg, matrix off-board |
| STM32U575VGT6 | C5270988 | LQFP-100 (14×14) | 1 MB / 768 KB | 17k | best-stocked U575 — drop-in if more GPIO wanted |
| STM32U575ZGT6 | C5271004 | LQFP-144 (20×20) | 1 MB / 768 KB | 230 | prior pick (oversized once the matrix left) |
| STM32L4R5ZIT6 | C1339786 | LQFP-144 | 2 MB / 640 KB | 5 | GMP-capable but ~unstocked → no-go |
| STM32U575RIT6 | C5270992 | LQFP-64 | 2 MB / 768 KB | 26 | the `I`/2 MB variant if ever needed — thin stock |

> Other L4R5 packages (LQFP-100 VIT6, UFBGA QIY6) returned **no LCSC listing**.
> Stock/price are point-in-time (fetched during scaffolding); re-check at order.

Considerations once pinned:
- **SRAM may be banked** (esp. on U5). For a single contiguous heap, use the
  largest contiguous span or place the heap section explicitly.
- **External memory:** internal RAM is ample, but a **4 MB quad-SPI NOR is now
  fitted on OCTOSPI1** (U7, `QSPIFlash` sheet) for memory-mapped constants +
  state/program storage (not for RAM).
- **USB FS** for a CDC console / provisioning + firmware update.

### Board partition: three boards (MCU + keyboard stacked, display cabled)

Calcumaker 16 is **three PCBs** (revised 2026-07-05 — the keyboard split off the
MCU board):

- **`calcumaker-mcu`** — the brain/PSU board: MCU (U575), PSU, clock, SWD, the
  display 5 V rail + level shifter + interconnect, and a **keyboard mezzanine**
  (J5). This is the dense fine-pitch SMT board (LQFP-64). *Bottom of the stack.*
- **`calcumaker-keyboard`** — the front-panel board: the 49-key Cherry MX matrix (2U ENTER)
  + per-key diodes + the annunciator LEDs + the mating **mezzanine header** (J1).
  A simple 2-layer through-hole board. *Stacks directly above the MCU board.*

  **The 2U ENTER.** ENTER is a **double-height (2U) keycap**, like every HP
  Voyager. It occupies two cells of the 5×10 grid — rows 3 and 4 of column 5
  (0-based) — but has a **single switch**, wired to the **lower cell's row line**
  (`KB_ROW5` × `COL6`), so ENTER keeps its matrix position and the firmware scan
  is unchanged. The other cell gets **no switch, diode, or RGB LED**: the grid is
  50 cells but the board is **49 keys / 49 LEDs**.

  *Physical placement (≠ the logical cell).* A 2U keycap's stem is **centered on
  the key**, so the switch body — and its RGB LED, which shines up through the
  switch's north window — sits on the **boundary between the two rows**, i.e.
  9.525 mm (½U) from either 1U cell center, at the column-5 x. The row/col
  assignment above is a *net* assignment, not a coordinate; the layout must place
  this one switch off the 1U grid.

  **Stabilizer.** A 2U key wants a stabilizer or it rocks. Two options, and the
  choice decides whether the PCB changes at all:
  - **Plate-mount (recommended)** — the stab clips into the switch plate we
    already need for the hot-swap sockets. KiCad's `SW_Cherry_MX_2.00u_Vertical_Plate`
    has *exactly the same pads as the 1u plate footprint* — **no PCB holes**. So
    the existing `calcumaker:SW_MX_HS_CPG151101S11_1u` footprint is reused as-is
    for ENTER; only the plate cutout and the keycap change. Keep the area under
    the stab wire clear (our SK6812s are reverse-mounted on the bottom, so it is).
  - **PCB-mount** — needs four NPTH holes, symmetric about the switch center at
    **y = ±11.90 mm** (23.8 mm stab spacing), each wing a **3.05 mm** hole at
    x = −7.00 mm and a **4.00 mm** hole at x = +8.24 mm (15.24 mm apart). Stock
    `Button_Switch_Keyboard:SW_Cherry_MX_2.00u_Vertical_PCB` has this pattern but
    is **solder-in**, so the hot-swap 2U variant is **vendored** as
    `calcumaker:SW_MX_HS_CPG151101S11_2u_Vertical` (our 1u hot-swap footprint plus
    those four holes; its origin is already the switch center). Place-on-back is
    safe: mirroring X maps the stab-hole set onto itself rotated 180°, and a 2U key
    is symmetric. Choosing PCB-mount would **also** force a **Row5 variant sheet**,
    since ENTER's switch sits on the shared 10-key sheet and multi-channel instances
    must share footprints — another reason to prefer plate-mount.

  The stabilizer itself is **mechanical hardware** (Cherry/Durock 2U, plate- or
  PCB-mount), not a schematic symbol — it carries no net and appears only in the
  layout + the mechanical BOM.
  - Firmware: `keys.rs` marks that cell `Key::Absent` (≠ `Key::Nop`, a real key
    with no function) in every layer of every personality; `ENTER_SWITCH_CELL` /
    `ENTER_SPAN_CELL` / `cell_has_switch()` are the source of truth, pinned by the
    `enter_is_2u_in_every_personality` golden test.
  - Displaced functions (identical in all four personalities): **x⇄y** moves onto
    the base layer at (3,4) — it is core RPN and stays unshifted; the mode key it
    displaced there moves to **f+ENTER** (16C `WSIZE`, SCI/15C `ANGLE`, FIN `%T`);
    and **FLOAT** moves to **g+ENTER**.
  - PCB: the matrix is no longer five *identical* rows, so the multi-channel
    design instantiates the reusable 10-key sheet **four times** (Row1/2/3/5) and a
    dedicated **9-key variant sheet** (`key_row_9.kicad_sch`) once for **Row4**.
    Reference numbering keeps a hole (no `SW36` / `D36` / `D91`) rather than
    renumbering, and Row4's RGB daisy-chain closes over the gap (LED@COL5 → LED@COL7).
- **`calcumaker-display`** — the multi-row 7-segment stack + its driver ICs + the
  interconnect back to the MCU board. It **mounts at an upward angle** for
  readability, cabled (not stacked).

**Why split the keyboard off the MCU board:** laying a dense LQFP-64 (0.5 mm
pitch, needs careful fan-out / multiple layers) into the same board as 50
full-size through-hole keyswitches is a routing and mechanical fight. Splitting
gives each PCB an easy job — the MCU board is a compact SMT brain, the keyboard
is a plain switch matrix — and lets the keyboard be the physical top surface the
user types on while the MCU board hides underneath.

**Keyboard link — stack *or* cable (populate one).** Because the keyboard has its
**own STM32G0 scanner**, only a **serial link + power** cross to the MCU board,
not the raw matrix. The same 12 signals map to **two footprints on each board —
populate whichever the build needs**:

- **Stacked:** a **Hirose DF40, 0.4 mm, 2×6 (12-pin), ~1.5 mm** mezzanine —
  receptacle `J5` **DF40B-12DS-0.4V** (C3641147) on the MCU board, header `J1`
  **DF40C-12DP-0.4V** (C6224952) on the keyboard. Compact rigid sandwich.
- **Cabled:** a **16-pin 0.5 mm FFC** — `J6` (MCU) + `J3` (keyboard), both
  **AFC01-S16FCA-00** (C262665, same family as the display FFC). The flat cable
  lets the **MCU board mount anywhere in the case**, off the keyboard footprint.

**Why the cable option exists:** the DF40 stack is only ~1.5 mm (tallest DF40 is
4 mm), but the keyboard's **bottom is now crowded** — Kailh hot-swap sockets
(~1.8 mm), reverse-mount LEDs, switch bodies — so the MCU board (STM32U5 QFP + PSU)
has nowhere to sit stacked directly under the keys. The **FFC decouples its
position** and fixes that; the DF40 stays for anyone who wants the compact
sandwich. **The FFC is 16-pin so its cable can't cross-plug the 12-pin display
FFC** (and the extra pins give **VSYS ×2 + GND ×3** for the LED current, + 2 spare).

The 12 signals: `+3V3 · GND · I²C_SDA · I²C_SCL · UART_TX · UART_RX · KB_IRQ ·
KB_NRST · KB_BOOT0 · GND · VSYS · GND` — VSYS is the always-on battery/USB rail
feeding the keyboard's per-key RGB. I²C is the primary key/annunciator channel;
UART is spare/expansion + the G0's ROM bootloader; `KB_IRQ` is the keypress wake.

*Mechanical:* the **cabled** build mounts both boards to the enclosure
independently (like the display) — no clearance conflict, and the recommended
default given the crowded keyboard bottom. The **stacked** build needs the MCU
board under a keyless region (or trimmed MX/socket clearance), tall connectors
(USB-C ~3.2 mm, battery JST ~5 mm) at the board edge, and 4 corner standoffs.
(DF40C-12DS isn't LCSC-stocked so the receptacle is DF40B-12DS — still 1.5 mm: the
DF40 *suffix* sets stack height, not the B/C letter; taller DF40HC variants swap
on the same land. Verify all lands + 3D clearance at layout.)

### Per-key RGB accent lighting (keyboard)

Fifty **SK6812MINI-E** (LCSC **C5149201**, single-wire addressable RGB) —
**per-key backlight** that hints key positions / presses. It's a **reverse /
bottom-mount** part (KiCad `LED_SK6812MINI-E_3.2x2.8mm_P1.5mm_ReverseMount`): it
sits on the **bottom** of the PCB and shines **up through** a cutout into each MX
switch's north LED window. That puts the LEDs on the **same side as the Kailh
sockets → single-sided assembly** (one stencil, one reflow pass, no board flip —
cheaper JLC, and it's why we didn't use a top-emit part). All 50 daisy-chain
(DIN→DOUT) off **one G0 pin** (WS2812 protocol, ~800 kHz); refs `D56–D105`.

**Power = gated VSYS.** The LEDs are ~5 V parts and the keyboard rail is only
3.3 V, so they run off **VSYS** — the MCU board's battery/USB system rail —
brought up the **widened 12-pin mezzanine**. A **high-side P-FET load switch**
(Q1 AO3401A + Q2 2N7002) on the keyboard **gates the whole LED rail off in sleep**
(G0 `LED_EN` low → LEDs + level shifter dead, near-zero leakage) to protect
battery life. A **74LVC1G125** buffer powered from the *gated* rail level-shifts
the 3.3 V data up to the LED V_IH (0.7·V_DD).

> **⚠ Headroom shrank with the BQ25601 (2026-07-12) — needs a check before layout.**
> VSYS used to be the Schottky-OR'd rail (**~4.6 V whenever USB was plugged in**).
> It is now the charger's **NVDC `SYS`**, which tracks **≈VBAT with a 3.5 V floor**
> — so the USB case drops to **~4.2–4.4 V** and the worst case on a low cell is
> **3.5 V**. The SK6812MINI-E is specified from ~3.7 V, so **near-empty-battery
> LED behaviour is the open risk**. The *level shifting* is unaffected (the buffer
> runs off the same gated VSYS, so data-high = VSYS and the 0.7·V_DD ratio always
> holds — it's inherently ratiometric). What needs verifying is **LED brightness /
> colour fidelity at 3.5 V**. Mitigation is already in the plan: firmware caps
> total brightness and should **fade the backlight out on low battery** anyway.
> Battery-only operation is **unchanged** (VSYS ≈ VBAT, 3.0–4.2 V, same as before).

**Current budget:** 50× full-white ≈ 0.75 A would exceed the DF40 contact + VSYS
budget, so the firmware **must cap total brightness** — "hint" use lights a few
keys at a time (pressed key + neighbours), an all-keys idle glow stays dim.

### Hot-swap switches (place-on-back) — this is a hot-swap board

The keyswitches use marbastlib's **`SW_MX_HS_CPG151101S11_1u`** footprint (vendored,
CERN-OHL-P): the switch mount + the Kailh **CPG151101S11** hot-swap socket. It is a
**place-on-back** footprint — the switch footprints go on the board's **back copper
layer**, so the socket (authored on `F.Cu`) lands on the physical **bottom** and
the keycaps face up on the front.

**This is a hot-swap board.** The socket (LCSC **C41430893**, ~93k stock,
JLCPCB-assemblable) is populated on the bottom; switches **plug in**,
field-swappable. A **plate** holds the unsoldered switches (a separate mechanical
part). The socket protrudes ~1.8 mm below the PCB (enclosure/standoff detail).

> **Not solderable for a switch-only build.** The switch thru-holes are minimal
> **0.15 mm-ring pass-throughs** for the pin into the socket — **not** solder
> pads. So a switch-only / **solder-in build is not supported on this footprint**.
> A solder-in board would use the dedicated solder-in footprint
> (`SW_Cherry_MX_1.00u_PCB`, also vendored) — a **separate board revision**, not a
> BOM toggle on this one. (Earlier notes framed this as a one-board "combo" — that
> was wrong; the pass-throughs don't make a reliable solder joint.)

Wider keys (2u Enter, etc.) need **stabilizers** — marbastlib's `STAB_MX_2u` and
KiCad's own `SW_Cherry_MX_2.00u_PCB` already carry the stabilizer mounts — a
layout option for later.

Keeping the display driver *on the display board* means only **+5V, GND, and the
display serial bus** (a handful of signals) cross that connector — instead of
dozens of segment/digit lines — which is what **simplifies the display wiring**.

- **Display interconnect:** a **0.5 mm 12-conductor FFC** — connector
  **AFC01-S12FCA-00** (LCSC C262661) on both `calcumaker-mcu:J3` and every display
  board's `J1`; the flat-flex **cable is a non-assembled DigiKey accessory** —
  **GCT FFC05-TIN `05-12-A-<length>-A-4-06-4-T`**. It is now a **unified,
  technology-agnostic SPI "display-module" bus** (see the next section), pinout
  `1=VSYS, 2=VSYS, 3=GND, 4=GND, 5=+3V3, 6=SPI_SCLK, 7=SPI_MOSI, 8=SPI_CS,
  9=DISP_IRQ, 10=DISP_NRST, 11=DISP_BOOT, 12=GND` — **identical on both the 7-seg
  and RGB-matrix display boards, so they are interchangeable.** `mcu:J3` ↔
  `<display>:J1` must match; verify FFC contact orientation at layout. LED current
  for the RGB matrix does **not** cross this FFC — it takes a dedicated 2-pin VSYS
  lead (`mcu:J7` → matrix `J2`).

### Aux display: optional 128×32 OLED (the "DNP-optional aux" pattern)

**Errors and rich status on a digits-only machine** are handled in two layers:

1. **The glass is primary.** Errors show HP-16C-style codes — a transient
   `Error N` on the X row (`CalcError::code()`: 0 math domain · 1 register/
   flag · 2 bits/shift/word · 3 mode ranges · 4 too large · 5 no solution ·
   6 stack/entry · 7 dates · 8 statistics · 9 reserved for crash recovery).
   The calculator is **fully usable with no OLED**.
2. **The aux OLED is optional detail.** A 0.91″ SSD1306 128×32 I2C module on
   the **display board** (`AuxDisplay` sheet, J2 1×4 socket, **DNP by
   default**), hand-placed alongside the THT digits. Content is
   **`App::aux_lines()`** — 4 lines × 21 chars (6×8 font), ONE code path for
   the firmware panel and the emulator's mock panel: an optional
   **status-flags header** (personality/radix/angle/number-mode, then
   prec/word/sign/C/G/format/shift/pending-register — SETUP > `OLEd`
   FLAG/oFF, default on), followed by the error text (`CalcError::text()`)
   or the **full-precision X** when idle (the windowing helper). I2C runs at
   3V3 straight from the MCU across interconnect pins 8–10; pull-ups R14/R15
   (4.7 kΩ) sit on the MCU board, DNP with the OLED. Firmware sleeps the
   panel in idle (~10 µA).

**The pattern** (reusable): optional capability = a cheap socket/footprint on
the board, DNP by default, module hand-placed by builders who want it — the
base build's cost, power budget, and identity stay untouched, and the firmware
degrades gracefully (glass codes) when the part is absent.

### Display: multi-row 7-segment (RPN stack), 2–3 rows

A multi-row 7-segment array shows the **top of the RPN stack**, **3 rows × 16
digits**. The board is laid out for 3 rows with the **top row optionally
populated**, so it builds as a **2- or 3-row** display (firmware-configurable).
A 16-digit row holds a full 64-bit hex word, or a signed mantissa + exponent;
arbitrary-precision values that exceed the row width are **windowed / scrolled**.

**Selected by LCSC price/availability (research):**

- **Driver: TM1640** (LCSC C5337152, SOP-28, ~$0.12, deep stock). A 2-wire bus
  drives **16 common-cathode digits per chip = one full row**, so **3 chips**
  cover 3 rows (vs ~6 MAX7219 at ~20× the cost). Shared CLK + one DIN per chip.
  Display-only (keys live on the keyboard board). TM1638 (C19187) is the drop-in if
  on-chip key-scan is ever wanted.
- **Digits: FJ5161AH** (LCSC C8093, 0.56" **single-digit common-cathode**, ~$0.10)
  — **16 per row → 48 digits** total. FJ5161AH is a *one-digit* part (confirmed on
  LCSC), so a row is 16 discrete digits, not a 4-up module — which gives even,
  continuous digit spacing across the 16-digit number. Common-cathode matches the
  TM1640: segments a–g,dp tie to the shared **SEG1–8** bus; each digit's cathode
  goes to one of **GRID1–16**.
- **⚠ Through-hole digits.** No SMD multi-digit 7-segment displays are stocked on
  LCSC — the well-stocked parts are THT. So `calcumaker-display` needs **THT
  assembly** (JLCPCB through-hole add-on, or hand/wave solder); the TM1640s are
  SMT. See `hardware/PARTS.md`.
- **Power note:** LED 7-segment is the dominant active current draw, *not* the
  MCU — and it's drawn from +3V3 **across the interconnect**, so it gates the
  MCU board's buck-boost sizing (the TPS63900 placeholder likely needs
  upsizing). Use TM1640 brightness/dimming + blank-on-idle + display-off in
  sleep to honor the battery goal.

**Schematic = KiCad multi-channel.** Every row is electrically identical (1
TM1640 + 16 digits over the shared SEG bus), so the row is authored **once** as a
reusable, fully-wired child sheet (`display_row.kicad_sch`) and instantiated
**three times** at the root (Row1/Row2/Row3), each annotating to its own refs
(U1/DS1–16, U2/DS17–32, U3/DS33–48). The shared bus rides global nets
(**+5V / GND / DISP_CLK**); each row's serial data **DIN** is a hierarchical pin
fed by **DIN1/DIN2/DIN3** from the interconnect. This replaced the old flat sheet
that drew all three rows redundantly and ran off the page.

KiCad symbols: the **TM1640** and the **single-digit `FJ5161AH`** are both
authored in `hardware/lib/symbols/calcumaker.kicad_sym` (registered in the display
board's `sym-lib-table`); the digit land is the 0.56" single-digit
`Display_7Segment:7SegmentLED_LTS6760_LTS6780`. ⚠ An earlier scaffold wrongly
mapped FJ5161AH to the **4-digit** `Display_Character:CC56-12EWA` /
`CC56-12GWA` — that 4-digit symbol/footprint/3D is where a phantom "clock colon"
came from; the real single-digit part has none. The display board **generates,
passes the structure check, and is fully wired** (ERC clean apart from the
expected connector-fed `power_pin_not_driven` on +5V/GND). See `hardware/PARTS.md`.

### Unified display-module interface (SPI; two interchangeable modules)

The display is a **swappable module**. The MCU board exposes ONE technology-
agnostic connector (`J3`, the 0.5 mm 12-pin FFC above) and speaks ONE protocol, so
it neither knows nor cares which display is attached. Each display board carries
its **own MCU** that receives semantic *display intent* over **SPI** and renders it
locally — mirroring the keyboard's "own-STM32G0-over-a-serial-link" pattern.

Two modules exist today, both on the identical `J1` connector/pinout:

- **`calcumaker-display` (7-seg):** an **STM32G031** (SPI slave) drives the 3
  TM1640s locally; it makes its own 5 V (TPS61022 boost) and level-shifts
  CLK+DIN1/2/3 3V3→5V (74HCT125) **on the module** — which is why those parts left
  the MCU board. Powered by VSYS/+3V3 from the FFC.
- **`calcumaker-matrix` (RGB dot-matrix):** an **RP2040** (PIO = the ideal WS2812
  engine) drives **96×24 = 2304× 1 mm** addressable RGB (XL-1010RGBC-2812B-S) in 3
  chains, built as a **nested multi-channel** design — an 8×8 `led_cluster` ×12 →
  `led_row` (768 px, one chain) ×3 → board. LED current (amps) comes on a
  **dedicated VSYS lead** (mcu `J7` → matrix `J2`), never the FFC. It also delivers
  the full alphanumerics / scrolling / color the 7-seg can't (so the 14-seg idea
  was dropped — genuine single-digit 14-seg is poorly stocked on LCSC and the
  matrix covers that need). 4-layer board at ~1.5 mm pitch; firmware caps brightness.

**The SPI "display intent" contract** (firmware, deferred): the U575 is SPI master
and writes a compact frame — the `App` display rows (text + dp/marker attributes),
annunciator/flag/mode state, and aux-OLED content. Each module MCU decodes it and
renders natively (7-seg glyphs via `core::seg7`; a pixel framebuffer + font on the
RP2040), keeping ONE glyph source-of-truth. `DISP_IRQ` = module→MCU ready/attention;
`DISP_NRST`/`DISP_BOOT` let the U575 reflash the module MCU (STM32 NRST/BOOT0;
RP2040 RUN/BOOTSEL). Any future display is a new module — no MCU-board change. See
`PARTS.md` for the per-board BOMs.

### Keypad: full-size Cherry MX, wide HP-16C-style layout

**5 rows × 10 columns = 50 full-size Cherry MX keys** (≈190 × 95 mm — authentically
wide), in the HP-16C / Voyager tradition with **f (gold) / g (blue)** shifts
(3 functions per key). Power is a **slide switch** (not in the matrix); any
keypress wakes the MCU from Stop, so no dedicated ON key is needed.

> **Width is deliberate.** Tighter packings were considered — 8×6 (≈152 mm, A–F
> as a 3×2 block) and 7×6 (≈133 mm) — but the full **10-wide** Voyager face was
> chosen for authenticity and one-function-per-key clarity, accepting the ~190 mm
> board width that full-size keys imply.

**Base (unshifted) faces:**

```
 SIN   COS   TAN   LN    √x    yˣ    1/x   EEX   ⌫     CLx
  A     B     C     D     E     F     7     8     9     ÷
 AND   OR    XOR   NOT   SL    SR    4     5     6     ×
 HEX   DEC   OCT   BIN   WSIZE x⇄y   1     2     3     −
  f     g    STO   RCL   R↓    ENTER 0     .     CHS   +
```

- Right 4 columns = numeric keypad + operators; **A–F** sit above 7-8-9 as the
  hex extension.
- **f (gold)** → inverse / advanced: ASIN/ACOS/ATAN, eˣ, x², **PREC** (set
  arbitrary-precision working digits), π, LASTx; over A–F → bit set/clear/test,
  MASKL/MASKR, bit-count; over AND…SR → RL/RR/ASR/RMD; over HEX/DEC/OCT/BIN →
  FLOAT; WSIZE → sign mode (unsigned / 1's / 2's); R↓ → R↑.
- **g (blue)** → secondary: SINH/COSH/TANH, LOG, 10ˣ, n!, %, RND (real → int);
  over HEX/DEC/OCT/BIN → **FIX/SCI/ENG/auto** (display format over display
  base; digit count from X). OFF sits on the f layer.
- The full keymap is the source of truth in
  **`firmware/calcumaker-core/src/keys.rs`** (`BASE` / `LAYER_F` / `LAYER_G`) —
  keep the two in sync. It lives in the core (not the board crate) because the
  emulator and the firmware share it; the f/g shift resolution
  (`keys::Shift`) and all key handling (`App`) sit beside it. Shift assignments
  marked `Nop` are open for refinement.
- **Visual diagrams:** `doc/keymap-16c.txt` / `doc/keymap-sci.txt` — ASCII
  key grids **generated from keys.rs** (`cargo run --example keymaps`), one
  per personality, freshness-enforced by a golden test so they can't drift.
  These are the reference for keycap-legend planning.

**Electrical:** 5-row × 10-col scanned matrix, scanned **on the keyboard board by
its own STM32G031K8U6** (LCSC C432207, UFQFPN-32 — not the main MCU; see Board
Partition). ROWr = G0 GPIO outputs, COLc = G0 GPIO inputs on **internal pull-ups**
(no external resistors — lower idle current; the G0 retains pull-ups in Stop).
**One 1N4148W per key** (anode at column, cathode toward switch/active-low row) for n-key
rollover. 15 GPIO (5 rows + 10 cols) on the G0. Refs: `SW1..SW50` (key `(r,c)` =
`SW(r-1)*10+c`), diodes `D1..D50`. Optional **Kailh hot-swap sockets** (same
footprint family). The G0 reports `(row,col)` events to the main MCU over the
mezzanine I²C bus (see Low-power & wake).

### Low-power & wake

Splitting the scanner onto the keyboard G0 gives **two independently-sleeping
domains**, both wake-capable; between keystrokes both sit in **Stop** at a few µA,
so the aggressive-sleep battery goal is preserved (the display + active MPFR
still dominate the budget).

- **Idle:** the **U575** is in **Stop 2** (~1–3 µA); the keyboard **G0** is in
  **Stop** (~1–5 µA), holding **all matrix rows low** with **columns on EXTI/wake
  pins** (internal pull-ups) — the classic keypress-wake trick, now on the G0.
  The G0 must Stop-and-wake, **never poll-scan continuously** (that would burn mA).
- **Key-on-wake is a two-stage chain:** keypress → a column pulls low → **G0
  wakes** (EXTI) → G0 scans + debounces → asserts **`KB_IRQ`** (mezzanine line)
  into a U575 **WKUP/EXTI** pin → **U575 wakes from Stop** → U575 reads the
  `(row,col)` event(s) from the G0 over **I²C**. Latency is sub-millisecond — the
  mechanical key is still down when the G0 scans, so nothing is missed.
- **Reverse direction is free:** the G0 also **wakes from Stop on I²C
  address-match**, so the U575 can push annunciator-LED states to the G0 without a
  dedicated wake line. During active typing both stay awake and I²C runs normally.
- **Power switch:** a **slide switch** gates power; there is no dedicated ON key
  (any keypress wakes via the chain above). *Optional robustness:* a wired-OR
  "any-key-down" line straight to a U575 WKUP pin would let the U575 wake
  independently of the G0 (one extra signal + a small diode-OR); `KB_IRQ` alone is
  the default.
- **Firmware split:** matrix scan + debounce + Stop/EXTI-wake + annunciator drive
  live in a **new keyboard-G0 firmware** (`embassy-stm32`, `stm32g031`,
  `thumbv6m`); the U575 firmware becomes an **I²C reader of `(row,col)` events**
  instead of a direct scanner. **`calcumaker-core::App` is unchanged** — it
  consumes `(row,col)` either way — so the engine, keymap, and emulator are
  unaffected.

### Power: 1S Li-ion + USB-C charge + buck-boost

USB-C (sink) → ESD → **BQ25601 3 A buck charger with NVDC power path** → VSYS →
buck-boost → 3V3. See **Power Tree**.

**Charger = BQ25601 (LCSC C468236, WQFN-24 4×4, ~$0.67).** Revised 2026-07-12 —
this replaces the **MCP73831** linear charger + the discrete load-share
(P-FET + Schottky) that the ephemerkey PSU used. Three reasons:

- **Charge rate.** The MCP73831 is *linear*: at its 500 mA ceiling it burns
  (5 − 3.6) × 0.5 ≈ **0.7 W in a SOT-23-5**, so 500 mA was never thermally real —
  the `R3 = 4.7 kΩ` PROG resistor set an honest **212 mA**, i.e. a **~10-hour**
  charge for a 2000 mAh cell. The BQ25601 is a **synchronous buck** (92% at 2 A
  from 5 V), so **2 A is a ~1-hour charge while dissipating *less* heat than the
  MCP73831 did at 212 mA**.
- **The load-share circuit disappears.** The BQ25601's **NVDC power path** *is*
  the load-share: `SYS` is a real regulated system output, so `Q1` (AO3401A),
  `D1` (B5819W) and `R4` all come out. It also does it properly — **dynamic power
  management** (it automatically throttles charge current when load + charge would
  exceed the input limit, instead of collapsing the input) and **instant-on** with
  a dead or absent cell. The Schottky-OR could do neither.
- **It lets us act on the Type-C advertisement** (below) — the input current limit
  (`IINDPM`) is an I²C register, settable 100 mA–3.2 A in 100 mA steps.

I²C also gives the calculator real **charge status / fault / adapter-present**
state for the annunciators (the low-batt lamp, Open Question 4), where the
MCP73831 had only a single STAT LED. And the `BATFET` **ship mode** (I²C command;
exit by plugging USB or pulling `/QON` low) gives near-zero drain for a
calculator that sits in a drawer for a year.

#### Reading the USB-C current advertisement — use the U575's **UCPD**, not an ADC

Today the CC pins are **bare 5.1 kΩ pulldowns**: we correctly present Rd, so a
source will *offer* us 1.5 A or 3.0 A — but nothing on the board ever **reads** the
offer, so we can never legally draw it.

**The U575 already contains the chip that fixes this.** It has a **UCPD**
peripheral (USB Type-C / Power Delivery controller), and on **LQFP-64 the CC pins
are bonded out** (verified against the `stm32-metapac` 21.0 pin database for
`stm32u575rg`):

| UCPD1 signal | Pin | Note |
|---|---|---|
| `CC1` | **PA15** | dedicated analog pin, no AF alternative |
| `CC2` | **PB15** | dedicated analog pin, no AF alternative |
| `DBCC1` / `DBCC2` | PB5 / PB14 | **not used** — only needed to drive an external dead-battery switch (e.g. TCPP01). PB5 stays SPI1 MOSI. |

This is strictly better than the ADC tap I first specified, on every axis:

- **The hardware decodes the advertisement for us.** `UCPD_SR.TYPEC_VSTATE_CC{1,2}`
  is a 2-bit field: `LOWEST` = detached · `LOW` = **default USB (500 mA)** ·
  `HIGH` = **1.5 A** · `HIGHEST` = **3.0 A**. No ADC channels, no thresholds, no
  calibration. Firmware reads it and writes the matching `IINDPM` over I²C.
- **Rd is generated internally** (`CcPull::Sink` = the spec's 5.1 kΩ), so
  **`R1`/`R2` come off the BOM**. Note this is an either/or: you **cannot** keep the
  external 5.1 kΩ *and* enable the internal Rd — they'd parallel to 2.55 kΩ and the
  source would misread us as an audio accessory. And you can't sense with the
  internal pull disabled, because the CC comparators are part of the same analog
  PHY. So: internal Rd, no external Rd.
- **PD becomes a firmware-only upgrade.** UCPD contains the **BMC PHY**, so if we
  ever want real PD, it's a software stack (the `usbpd` crate drives embassy's
  UCPD) — **no board respin**. Compare the CH224K route, which needs an IC *and* a
  topology change.
- **`embassy-stm32` 0.6 already ships a UCPD driver** — the version we already
  depend on — with explicit `stm32u5` dead-battery handling
  (`PWR.UCPDR.UCPD_DBDIS`) and an async `wait_for_vstate_change()`.

**Cost: one pin move.** `CC1` is hard-wired to **PA15**, which the committed pin map
had as the display **SPI1 CS**. CS is a plain software-driven GPIO (not an AF), so
it just moves — reassigned to **PA8**. Nothing else in the map is disturbed.

#### The CC front-end: TCPP01-M12 (`U5`) — ST's UCPD companion chip

CC does **not** go straight to the MCU. It goes through a **TCPP01-M12**
(C1121848, QFN-12 3×3, ~$0.90; **300 pcs secured on JLCPCB**, 2026-07-12). This is
the missing half of ST's reference sink front-end, and it does two things a plain
ESD diode cannot:

**1. It owns the dead-battery handoff.** A Type-C source supplies **no VBUS until it
sees Rd** — so with no external resistors, a completely flat board must still present
Rd while the MCU is unpowered. The TCPP01 carries **its own Rd** and clamps CC (1.1 V)
in that state. The wake sequence (datasheet Fig. 17) is:

1. Flat board — TCPP01 clamps CC with its own Rd (`DB/` low ⇒ clamp on, CC switches open).
2. The source sees the clamp and applies **5 V on VBUS**.
3. `Q1` turns on, VBUS reaches the charger, and the BQ25601's NVDC **instant-on** boots the MCU.
4. Firmware powers the TCPP01 (`TCPP01_EN`) and **enables Rd in UCPD**.
5. **Only then** drive `DB/` **high** → TCPP01 drops its clamp, closes the CC switches, and UCPD owns the CC lines. **Order matters** (datasheet §6.4).
6. Firmware reads `VSTATE` and sets `IINDPM` on the charger over I²C.

This **closes the dead-battery risk outright** — it's now a wire, not a thing to
validate. (The Nucleo bring-up is still worth doing for the UCPD *driver*, but the
board no longer depends on `UCPD_DBDIS` behaving.)

**2. CC short-to-VBUS overvoltage protection (6.0 V clamp).** The classic Type-C
failure: a defective cable or source shorts CC to VBUS, putting a *sustained* 5–20 V
onto pins that expect ≤2 V. That destroys PA15/PB15 and the MCU with them. A USBLC6
is an **ESD clamp** (nanosecond transients) and does **nothing** about this. The
TCPP01's connector-side pins (`CC1c`/`CC2c`) are **22 V tolerant** and it clamps the
MCU side at 6.0 V. It also brings IEC 61000-4-2 **level 4** ESD on CC.

It additionally gate-drives an external N-FET (**`Q1` = AO3400A**, C20917, 30 V/5.7 A,
28 mΩ — a JLCPCB **basic** part) that sits **in series on VBUS**: connector → `IN_GD`
(drain) → FET → `SOURCE` → the charger. On an OVP/OTP/UVLO fault, the TCPP01 pulls the
gate down and **physically disconnects the system from a defective charger**.

| Function | Parts | Note |
|---|---|---|
| VBUS OVP threshold | `R6` 10 k / `R7` **976 Ω** → `VBUS_CTRL` | trips **13.5–15.1 V** — sized for a **12 V PD** contract (see *USB-PD*), **not** ST's Table 13 row |
| VBUS voltage sense | `R4` 200 k / `R10` 40.2 k → ADC | not needed at 5 V, but a **PD policy engine requires it** — fitting it now keeps PD firmware-only |
| CC line capacitance | `C28`/`C29` 150 pF | USB-PD wants 200–600 pF total; TCPP01 adds 40–100 pF, MCU 60–90 pF (Table 12) |
| ESD capacitor | `C30` 100 nF **50 V X7R** | ⚠ **the system ESD rating depends on this part** — ≤0603, placed hard against the TCPP01 (§6.5.1, §7) |
| Fault flag | `FLT/` open-drain + `R11` 100 k | OVP / OTP / UVLO |

⚠ **The OVP divider is sized for the 12 V PD contract** (`R7` = 976 Ω). It must be
re-spec'd if we ever raise the maximum PDO above 12 V — and the caps on the VBUS
rail (`C1`/`C2`/`C6`, now 50 V) would need re-checking too. See **USB-PD**.

**`DB/` is a plain 3.3 V GPIO — not the UCPD `DBCC` pins.** This matters: it means
`DBCC1`/`DBCC2` stay unused and **PB5 remains SPI1 MOSI**. No pin conflict.

**Null quiescent current.** The TCPP01's `VCC` is fed from an MCU GPIO
(`TCPP01_EN`), which is ST's recommended battery-sink configuration: with `VCC` and
`DB/` both off it draws **0 µA** when no cable is attached, instead of 120 µA — worth
having on a device that spends its life asleep in a drawer.

**Sleep.** Rd must not vanish when the calculator sleeps mid-charge, or the source
would detach. UCPD's analog PHY stays alive in **Stop** modes, and `PWR.UCPDR` has a
`UCPD_STDBY` bit to retain the CC configuration into **Standby** — firmware must set
it before sleeping while attached. (We sleep in Stop between keystrokes, so this is
a Standby-path concern only.)

D+/D− still get the **USBLC6-2SC6** (`U3`) — the TCPP01 covers VBUS and CC, not the
datalines.

**`PSEL` is pulled high to REGN through 100 kΩ**, so the charger's initial input
limit is **500 mA**. Do not connect PSEL to 12 V VBUS (its absolute maximum is 7 V).
**CE defaults high through 100 kΩ:** the system power path can start, but charging
waits for firmware to configure the selected cell and enable it. The TS circuit
requires a 10 kΩ 103AT-2 pack NTC at J8; it does not bypass thermal protection.

**Legacy USB-A bricks stay at 500 mA.** A C-to-A cable carries a 56 kΩ Rp in the
plug, which advertises "Default USB" no matter how beefy the brick is, and the
plain BQ25601 has no D+/D− pins so it can't run BC1.2 to discover otherwise. That
is still **2.4× today's 212 mA**, and every modern C-to-C charger gives us the
full 3 A. If the legacy case ever matters, the pin-compatible **BQ25601D**
(C2859691, ~$0.88) adds D+/D− BC1.2 detection — but it needs a custom KiCad symbol
(the stock symbol is the non-D pinout), so we're not paying that cost up front.

#### USB-PD: **up to 12 V**, negotiated by the MCU (decided 2026-07-12)

The board is now specced to take a **12 V PD contract**. No PD negotiation IC is
needed — **UCPD's BMC PHY does the negotiation**, so PD is entirely a *firmware*
component (the `usbpd` crate driving embassy's UCPD). The **CH224K stays dropped**:
it could never report the current advertisement (its `CFG1` resistor picks a
*voltage* to request; `PG` only says "the voltage I asked for was granted"), and
UCPD makes it redundant.

The **BQ25601's input range is 3.9–13.5 V** (22 V abs max), so **12 V lands inside
its operating range** and feeds the same buck input — the power topology is
unchanged. Going to 12 V costs exactly three things:

**1. The OVP divider (`R7` = 976 Ω → trips 13.5–15.1 V).** The trip must sit *above*
the highest legal VBUS and *below* what stresses the parts. A 12 V PDO is spec'd
**±5%, so up to 12.6 V**; the BQ25601's abs max is 22 V. With `R6` = 10 k:

| `R7` | Trip (min→max, over `V_OVP_th` = 1.20–1.34 V) | Verdict |
|---|---|---|
| 2.7 k | 5.6 → 6.3 V | the old 5 V-only value |
| **1.1 k** (ST Table 13 "13 V" row) | **12.1 → 13.5 V** | ❌ **min trip is *below* a legal 12 V source** — nuisance-trips on a good charger |
| **976 Ω** ✅ | **13.5 → 15.1 V** | clears 12.6 V, far under 22 V |

> ⚠ **ST's Table 13 is nominal-only — it ignores the `V_OVP_th` spread.** Taking its
> "13 V" row at face value would have produced a board that randomly rejects
> legitimate 12 V chargers. Size from the min/max, not the typ.

**2. The VBUS-rail capacitors must become 50 V parts.** `C1`, `C2` (PMID, which sits
at ≈VBUS) and `C6` (bulk) were 16 V. On a 12 V rail that is *no margin* against a
15.1 V OVP excursion — and worse, **DC-bias derating** means an X5R at 12 V on a 16 V
part sheds most of its capacitance, so a "10 µF" wouldn't be 10 µF exactly where it
matters. Now `C1` = 1 µF/50 V 0603 (**C15849**) and `C2`/`C6` = 10 µF/50 V 0805
(**C440198**) — both JLCPCB **basic**. The VSYS/VBAT-side caps (`C3`–`C5`, `C7`–`C11`)
stay 16 V; they never see more than ~4.4 V.

**3. Firmware owns the input current limit.** Once a PD contract exists, **the PDO —
not the CC Rp advertisement — governs `IINDPM`**. The CC `VSTATE` path remains the
fallback for a plain 5 V Type-C source that never negotiates. Firmware logic:
*PD contract? → use the PDO's voltage/current. No contract? → use `VSTATE`.*

The **VBUS_SENSE divider (`R4`/`R10`) needed no change** and is now load-bearing
rather than speculative — a PD policy engine requires VBUS sensing (vSafe0V/vSafe5V).
It reads 2.01 V at 12 V and 2.53 V at the OVP trip, comfortably inside the 3.3 V ADC
range. Fitting it "for a PD future we might not build" turned out to be the right
call one turn later.

The `Q1` AO3400A (30 V) and the TCPP01 (`IN_GD` rated 22 V) were already fine at 12 V.

> **Note this does *not* buy meaningful charge speed.** 5 V × 3 A = 15 W already
> exceeds what a 1S cell can absorb (2 A ≈ 1C). 12 V PD is about **compatibility** —
> chargers that offer their best current only at higher voltages — and it draws less
> input current for the same power. The cell, not the input, remains the limit.

#### Alternatives considered

- **BQ25606** (C374063, ~$0.73) — same 3 A NVDC silicon, **no I²C** (resistor-set
  ILIM). Tempting for zero firmware, but its input limit is then a fixed resistor
  or whatever BC.1.2 concludes — and Type-C sources routinely leave D+/D− floating
  while advertising 3 A on CC, so BC.1.2 calls it an SDP and clamps us to 500 mA.
  **It structurally cannot exploit the thing we want.** The I²C on the '601 is
  precisely the mechanism that makes CC sensing pay off.
- **BQ24075** (C15464, ~$0.86) — has the power path, but is still **linear**, so
  the thermal wall just moves.
- **IP2312** (C605432, ~$0.28) / **ETA6003** (C5455585, ~$0.45) — cheap 2–3 A
  bucks, but IP2312 has **no SYS power path** (we'd keep the load-share kludge) and
  both have thin, largely-Chinese documentation. Not worth the ~$0.30 on a board
  that already carries a U575.

On the CC side, the discrete parts that do "PD *and* report the advertisement" —
**FUSB302** (C891307, ~$0.51, a full CC PHY: reports the Rp advertisement over I²C
*and* does PD BMC) and **HUSB238** (C24833806, ~$0.57, a PD sink that reports the
source's PDO list over I²C) — are both **strictly redundant with UCPD**, which we
already own. The **TCPP01-M12** is *not* an alternative to UCPD but its
**companion** — it protects the CC lines and owns the dead-battery Rd, and it is
now fitted (`U5`). It was nearly dropped for stock reasons (LCSC showed 11 pcs);
**300 pcs were secured on JLCPCB on 2026-07-12**, which is what made it viable.

Net BOM delta: the old linear front-end (MCP73831 $0.87 + load-share Q1/D1/R3/R4
≈ $0.92) is replaced by BQ25601 ($0.67) + inductor + caps ≈ $0.85 — roughly flat —
**plus ~$1.00 for the protection front-end** (TCPP01 $0.90 + AO3400A $0.07 + a
handful of passives). That dollar buys dead-battery charging and immunity to a CC
short-to-VBUS killing the MCU; on a device with a 3 A input it is cheap insurance.

### Numeric core: GMP + MPFR, single path (no fallback)

The calculator engine lives in **`firmware/calcumaker-core/`** — a plain library
(RPN stack + the `Value` = arbitrary-precision int/real) over **GNU MP + MPFR**.
There is **one** numeric path: the pure-Rust fallback was dropped. On the host
the engine talks to GMP/MPFR through our own **`gmp-mpfr-nostd`** crate (thin
`no_std` FFI — *like `rug`, but for a `no_std` world*). On the host it links the
system GMP/MPFR and is fully unit-tested + runnable (`cargo run --example repl`);
the **same `no_std` crate** also compiles for the MCU, where the firmware links
the cross-built GMP/MPFR. See **Numeric Core**, **Host development & testing**,
and **GMP/MPFR on the target** below.

---

## Software Stack (Rust, no_std)

| Layer | Choice | Notes |
|---|---|---|
| Toolchain | stable Rust, target `thumbv8m.main-none-eabihf` (M33 / U575) | `thumbv7em-none-eabihf` if an L4+ (M4F) is used |
| Runtime | `cortex-m`, `cortex-m-rt` | super-loop now; → embassy executor later |
| HAL | **`embassy-stm32`** (async), feature `stm32u575zg` | `stm32u5` PAC underneath |
| Heap | **`embedded-alloc` (TLSF)** | TLSF handles variable-size bignum churn with less fragmentation than LLFF |
| Flash/debug | **`probe-rs`** (`cargo run`/`cargo embed`) | set the chip name in `.cargo/config.toml` |
| Logging | `defmt` + RTT (optional) | |
| Math bindings | **`gmp-mpfr-nostd`** (own no_std FFI) | host links system GMP/MPFR; target links cross-built |
| Engine + app | **`calcumaker-core`** (RPN, no_std) | one path; engine (`Calc`), keymap + shifts (`keys`), key handling + entry editing (`App`), 7-seg encoding (`seg7`) |
| Emulator | **`calcumaker-emu`** (host, crossterm) | the same `App` on a terminal — ASCII 7-seg from the real TM1640 segment bytes |

---

## Host development & testing (works today)

The engine's math goes through our own **`gmp-mpfr-nostd`** crate — thin `no_std`
FFI bindings to GMP/MPFR (`Integer` = `mpz`, `Float` = `mpfr`), *like `rug` but
for a `no_std` world*. On the host its `build.rs` links the **system / Homebrew**
GMP + MPFR (no build-from-source), so the engine is a normal library you develop
and test on the desktop against the **real** C libraries — and it builds in
under a second:

```sh
brew install gmp mpfr                 # one-time host deps (apt: libgmp-dev libmpfr-dev)
cd firmware/calcumaker-core
cargo test                            # engine + app + seg7 tests vs real GMP/MPFR
cargo run --example repl              # interactive RPN (token REPL)
```

Crucially this is **one crate, `no_std`** — it also compiles for the MCU target
(`cargo build --target thumbv8m.main-none-eabihf` succeeds today); only the final
link to the C libraries differs. This is the single source of truth for the
calculator logic and math.

## Emulator (host CLI) — the device UI without the device

**`firmware/calcumaker-emu/`** runs the calculator on a standard terminal. It
is not a mock: the whole device-independent calculator lives in
`calcumaker-core` and the emulator hosts it exactly as the firmware will —

- **`keys`** — the 49-key matrix keymap + f/g shift layers + resolution
  (`Shift`), the design source of truth;
- **`App`** — key handling on top of the engine: HP-style digit-by-digit entry
  (live `_` cursor, backspace, EEX, CHS-in-entry flips the mantissa/exponent
  sign), flush-on-operation, CLx/ENTER semantics, error → status message;
- **`seg7`** — text → per-digit **TM1640 segment bytes** (a..g+dp bit layout,
  `.` folds into the previous digit's dp, right-aligned, `]`-shaped overflow
  marker in the last cell when a value exceeds 16 digits).

Both frontends are thin I/O bindings around `App::press(row, col)` +
`App::seg_rows()`: the firmware path contributes keyboard-board events and the
TM1640 bus; the emulator maps host keys to matrix cells and renders **the same
segment bytes** as LED-style 7-seg art — Unicode block elements by default
(`▄`/`█`, dp = `▗` in its own column + an inter-digit gap, ~100 columns),
`--ascii` for a plain `_`/`|` fallback — plus
annunciators and the untruncated X, where the arbitrary precision is visible.
If it works in the emulator, the only difference on the device is GPIO.

```sh
cd firmware/calcumaker-emu
cargo run                            # interactive; ? = key map, Ctrl-C = quit
cargo run -- --press "2;3+"          # scripted: 2 ENTER 3 + → prints the frame
cargo run -- --prec 1024 --press "FE"  # f-shift E = pi, at 1024 bits
```

Display policy (initial, revisit with real glass): X (or the live entry) on the
bottom row, Y/Z above; values right-aligned. **AUTO-mode reals are
display-rounded to the 16-digit window** (correctly, by MPFR — HP behaviour:
the glass rounds, the register keeps full precision; a value a hair under
382.1 shows `382.1`, not `382.09999…`; exponent-bound values go scientific
with maximal digits). The emulator's `X:` line is the SHOW view — X at full
precision. Integers and explicit FIX/SCI/ENG wider than the row truncate with
the overflow marker, and the **window keys** (16C `<`/`>`, g-shift SL/SR)
scroll X through the rest: window 0 = 15 cells + marker, window k ≥ 1 picks up
exactly where the marker cut off (every digit reachable — tested by
reassembly); any other key resets the view; `win k/N` annunciator. Engine modes are RPN
postfix like the HP-16C: `<bits> W` (WSIZE, 0 = unbounded), f-shift `I`
(= `prec`, pops X as the MPFR working precision), f-shift WSIZE cycles the sign
mode, g-shift over the radix keys sets FIX/SCI/ENG/auto (digits from X). The
annunciator line shows radix, prec, word size + sign mode, the **C**/**G**
flags, the format, a pending f/g shift or STO/RCL, and error blips.
Runtime configuration lives in the **SETUP menu** (g-shift CLx): suffix /
leading zeros / angle / sign mode today, personalities later
(`DESIGN-MODES.md` §5.6); numeric settings stay RPN-postfix.

## GMP/MPFR on the target (✅ cross-built + link-verified)

The Rust is already `no_std` and target-compiling; the C libraries are now
cross-built too. **`firmware/scripts/build-gmp-mpfr-arm.sh`** builds static
`libgmp.a` + `libmpfr.a` for Cortex-M33 hard-float and installs them to
`firmware/vendor/gmp-mpfr-arm/` (gitignored — reproducible, not committed):

```sh
firmware/scripts/build-gmp-mpfr-arm.sh        # GMP 6.3.0 + MPFR 4.2.1, ~5 min
GMP_MPFR_LIBDIR=firmware/vendor/gmp-mpfr-arm \
  cargo build -p calcumaker-fw --target thumbv8m.main-none-eabihf
```

Key build details (see recall note `ref-gmp-mpfr-no-std`):
- `./configure --host=arm-none-eabi --disable-assembly` (the `--disable-assembly`
  is **mandatory** — no `mpn` asm backend for M-profile); MPFR `--with-gmp=`.
- `CFLAGS=-mcpu=cortex-m33 -mthumb -mfloat-abi=hard -mfpu=fpv5-sp-d16
  -std=gnu17 --specs=nosys.specs` — **`-std=gnu17`** is required (GCC 15 defaults
  to C23, which breaks GMP's old-style configure probes), and the **hard-float**
  flags make the ABI match `thumbv8m.main-none-eabihf`.
- `calcumaker-fw/build.rs` links them when `GMP_MPFR_LIBDIR` is set;
  `gmp-mpfr-nostd`'s own `build.rs` no-ops on `-none-eabi` — same FFI, just a
  different linker input.

**Verified:** a Cortex-M33 ELF links cleanly against the libs with
`Tag_ABI_VFP_args: VFP registers` (hard-float) and `FPv5/FP-D16`; a GMP+MPFR
program is ~127 KB text. **Remaining (firmware bring-up, not math):** at final
link, route GMP's allocator to the heap (`mp_set_memory_functions`) and resolve
newlib's `memcpy`/libm for GMP/MPFR (link the toolchain libc/libm) — folded into
the MCU/HAL bring-up.

- **Footprint:** ~0.5–1 MB flash for both libs; heap scales with precision —
  the reason for the large-flash MCU.
- **Licensing:** GMP is LGPLv3/GPLv2, MPFR is LGPLv3 — compatible with the
  AGPL-3.0 firmware; honor LGPL relinking terms for a shipped product.

---

## Power Tree

```
USB-C ──VBUS──┬── ESD (USBLC6 U3) ──► D+/D- ──► STM32 USB FS
              │
              ├── CC1/CC2 ─────► TCPP01-M12 (U5) ──► STM32 UCPD1 (PA15/PB15)
              │                    - own Rd while MCU is    Rd INTERNAL (CcPull::Sink)
              │                      unpowered (dead batt)   VSTATE = detached/0.5/1.5/3.0A
              │                    - 6.0V CC OVP clamp       (+ BMC PHY -> PD later, fw-only)
              │                    - IEC61000-4-2 L4 ESD                    │
              │                    - DB/ EN/ FLT -> GPIO                    │
              │                                                        I2C1 │ sets IINDPM
              │  VBUS ──► IN_GD ─┤ Q1 AO3400A ├─► SOURCE = VBUS_PROT        │
              │           (TCPP01 gate-drives Q1; on OVP it opens ──────┐   │
              │            and disconnects a defective charger)         ▼   ▼
              └───────────────────────────────────────────► BQ25601 (3 A sync buck + NVDC)
                                       │  PSEL=high → 500 mA safe default at plug-in
                                       │  SCL/SDA/~INT/~PG/~CE ──► STM32 (I2C1 @ 0x6B)
                                       │
                        BAT ◄──────────┤                (ICHG over I2C, sized to cell)
                         │             │
                         ├──► MAX17048 (U6) fuel gauge — VDD+CELL on the RAW CELL
                         │      I2C 0x36 · ~3uA · ModelGauge (no sense resistor)
                         │      ALRT (low-SoC, open-drain) ──► MCU WKUP ──► LOWBAT lamp
                         │             │
                 1S Li-ion (JST-PH)    └── SYS ──► VSYS ──┬── buck-boost ──► +3V3 ──► MCU
                                          (NVDC:          │   (TPS63900, ULP, low-Iq,
                                           ≈VBAT,         │    always on — light load)
                                           min 3.5 V)     │
                                                          ├──► J3 FFC pins 1–2 ──► display module
                                                          │      (+3V3 on pin 5)    (boosts its own 5V)
                                                          │
                                                          └──► J7 2-pin JST-PH ──► RGB-matrix LED inlet
                                                                 (LED amps only, off the signal FFC)
```

- **The MCU board generates one rail: +3V3.** The MCU runs on the ultra-low-Iq
  3V3 buck-boost (TPS63900, always on, so sleep current stays tiny). **VSYS is
  passed through raw** to the display module — on the FFC (`J3` pins 1–2) and,
  for the RGB matrix's LED current, over the dedicated 2-pin `J7` lead.
- **VSYS is now the charger's NVDC `SYS` output**, not a Schottky-OR'd rail. It
  tracks **≈VBAT with a 3.5 V floor** while an input is present, instead of the old
  ~4.6 V (VBUS − Schottky). See the RGB headroom note under **Per-key RGB**.
- **5V and level shifting live on the display module, not here.** The 7-seg
  module boosts VSYS→5V (TPS61022) and level-shifts CLK+DIN1/2/3 3V3→5V
  (74HCT125) for its own TM1640s. The MCU board only speaks the 3V3 SPI
  display-module bus. There is **no 5V boost, no 74HCT125 and no `DISP_PWR_EN`
  on the MCU board** — display power-down is a module-side concern, commanded
  over the SPI bus (or via `DISP_NRST`).
- **NVDC, not load-share.** The charger always powers `SYS` from whichever source
  it can, and *supplements from the battery* when the input current limit isn't
  enough for the load — so a 500 mA source still runs a display-lit calculator.
  VSYS (3.0–4.4V) is always < 5V → the display module's boost still works.
- **Display current budget** (3× TM1640 × 16 CC digits) sizes the **module's**
  boost and the `J7` VSYS lead, not the MCU board's 3V3 rail.

---

## Pin Budget

MCU is **STM32U575RGT6** (LQFP-64). Expected peripheral use (all on the MCU board
— the key matrix + annunciators moved to the keyboard board):

- **Display bus** → **SPI1** master (SCK + MOSI + CS) to the display module's own
  MCU, plus **DISP_IRQ** / **DISP_NRST** / **DISP_BOOT**. No MISO — the 12-pin FFC
  doesn't carry one. (Was a bit-banged TM1640 2-wire bus; those parts moved to the
  module.)
- **Keyboard link** (mezzanine to the keyboard G0) → **I²C** (SDA/SCL) + **UART**
  (TX/RX) + **KB_IRQ** (on a WKUP pin — keypress wake from Stop) + KB_NRST +
  KB_BOOT0.
- **Charger (BQ25601)** → **shares I²C1** with the keyboard G0 (charger is at
  **0x6B**, no address conflict) + 3 GPIO: **CHG_INT** (`/INT`, EXTI — charge
  done / fault / adapter insert), **CHG_PG** (`/PG`, adapter present), **CHG_CE**
  (`/CE`, charge enable). `STAT` drives its LED locally, not a pin.
- **OCTOSPI1** → 6 GPIOs: CLK, NCS, IO0–IO3 → the 4 MB quad-SPI NOR (U7).
- **USB FS** (PA11/PA12) → CDC console / provisioning.
- **SWD** (PA13/PA14) → Tag-Connect programming header.
- **LSE 32.768 kHz** crystal → RTC (sleep timing).
- **UCPD1** → **CC1 (PA15) + CC2 (PB15)** — the Type-C current advertisement, read
  as a hardware register (see **Power**). Rd is internal; no ADC, no resistors.
  `DBCC1`/`DBCC2` are **not used** (the TCPP01's `DB/` is a plain GPIO), so PB5
  stays SPI1 MOSI.
- **TCPP01 (U5)** → 3 GPIO: **TCPP01_EN** (powers its `VCC` — gives 0 µA when
  unplugged), **TCPP01_DB** (`DB/`, the dead-battery handoff), **TCPP01_FLT**
  (`FLT/`, open-drain fault).
- **Fuel gauge (U6, MAX17048)** → **shares I²C1** (0x36) + 1 GPIO: **GAUGE_ALRT**
  (open-drain low-SoC interrupt → the **LOWBAT** annunciator; wants a **WKUP** pin).
- **ADC ×2** → battery voltage sense (needs a divider — VBAT up to 4.2 V > VREF;
  now a *sanity check* on the gauge rather than the primary SoC source)
  + **VBUS_SENSE** (`R4`/`R10` divider off the TCPP01 front-end; **required by the PD
  policy engine**).

Rough count ~36 signal GPIO — comfortably inside LQFP-64 (~50 I/O).
**Three I²C1 devices share the bus**: keyboard G0, BQ25601 (**0x6B**), MAX17048
(**0x36**) — no address clashes.

### Committed pin map

**OCTOSPI1 does have a valid LQFP-64 mapping** (open question closed). On U5 the
OCTOSPI GPIOs belong to the **OCTOSPI I/O manager**, so the AF signals are named
`OCTOSPIM_P1_*`; OCTOSPIM routes OCTOSPI1 → Port 1 (straight-through). **LQFP-64
bonds out no Port-2 bus** (ports E/F/G are absent — the only P2 signal present is
`P2_NCS`), so Port 1 is mandatory. On this package **IO0–IO3 have exactly one pin
each**; only CLK (PA3 | PB10) and NCS (PA2 | PA4 | PC11) offered a choice.

| Function | Signal | Pin | AF | Pkg | Note |
|---|---|---|---|---|---|
| OCTOSPI1 → U7 | CLK | PB10 | AF10 | 29 | PA3 (p17) is the only alt — too far from the IOs |
| | NCS | PA4 | AF3 | 20 | costs SPI1_NSS + WKUP2 |
| | IO0 | PB1 | AF10 | 27 | forced |
| | IO1 | PB0 | AF10 | 26 | forced |
| | IO2 | PA7 | AF10 | 23 | forced |
| | IO3 | PA6 | AF10 | 22 | forced |
| SPI1 → display J3 | SCK | PA5 | AF5 | 21 | PA6/PA7 are QSPI now |
| | MOSI | PB5 | AF5 | 57 | UCPD `DBCC1` also lands here but is unused — no conflict |
| | CS | **PA8** | — | 41 | **moved off PA15** (now UCPD1_CC1); CS is a plain GPIO, so it relocates freely |
| **UCPD1** → USB-C CC | CC1 | **PA15** | — | 50 | dedicated analog pin, **no AF alternative** — this is why CS moved |
| | CC2 | **PB15** | — | 36 | dedicated analog pin; pad63 is VSS |
| USART2 → keyboard | TX | PA2 | AF7 | 16 | pair kept intact by choosing PA4 for NCS |
| | RX | PA3 | AF7 | 17 | |
| I²C1 → keyboard **+ charger + gauge** | SCL | PB6 | AF4 | 58 | shared bus; BQ25601 = **0x6B**, MAX17048 = **0x36** |
| | SDA | PB7 | AF4 | 59 | PB3 is SWO — don't use it for SDA |
| USB FS | DM/DP | PA11/PA12 | | 44/45 | |
| SWD | SWDIO/SWCLK/SWO | PA13/PA14/PB3 | | 46/49/55 | |
| LSE | OSC32_IN/OUT | PC14/PC15 | | 3/4 | |

Choosing **CLK=PB10 + NCS=PA4** keeps the whole quad bus in a contiguous
**pin 20–29** cluster (short, length-matchable at ≥50 MHz) *and* leaves PA2/PA3
whole as the USART2 TX/RX pair for the keyboard link. Verified against the ST
CubeMX pin database for `STM32U575RGTx` / LQFP-64.

CC1/CC2 are **fixed by the silicon** (dedicated analog pins, no AF remap), verified
against the `stm32-metapac` 21.0 pin DB for `stm32u575rg`. PA15 was the display CS,
so **CS moved to PA8** — a plain GPIO, no AF constraint, zero cost.

Assigned in the wired revision: **KB_IRQ=PA0**, gauge alert=PC13,
VBUS/BAT ADC=PC0/PC1, CHG_INT/PG/CE=PC2/PC4/PC5,
TCPP enable/DB/fault=PC6/PC7/PC3 and display IRQ/reset/boot=PB12/PC8/PC9.
Keyboard reset/boot use PC10/PC11. The complete G031 matrix and annunciator map,
shared PA14/SWCLK/BOOT0 requirements, and package pin numbers are in the
[wiring review](hardware/WIRING_REVIEW.md).

---

## Schematic Sheet Plan

Three boards were initially generated from their own manifests. The MCU and
keyboard hierarchies are now wired and maintained directly in KiCad. The display
and keyboard matrix use reusable row sheets. The guarded MCU/keypad manifests
remain historical placement drafts and must not overwrite the completed wiring.

**`calcumaker-mcu`:**

| Sheet | File | Contents |
|---|---|---|
| Root | `calcumaker-mcu.kicad_sch` | explicit MCU/PSU/QSPI/keyboard sheet ports and connecting wires |
| MCU | `mcu.kicad_sch` | STM32U575RGTx (U1) + VDD/VDDA/VDDUSB decoupling + VCORE + NRST/BOOT0 + the **committed pin map**. Also absorbs the three former one-off sheets: LSE crystal (Y1 + C24/C25), SWD Tag-Connect TC2030-NL (J4), and the unified SPI display-module interface — connector **J3** (0.5 mm 12-pin FFC) + **J7** VSYS outlet (5V + level shifting live on the module) |
| PSU | `psu.kicad_sch` | USB-C + ESD + CC sense + BQ25601 charger (NVDC power path) + 3V3 buck-boost (MCU) + battery conn |
| KeyboardIF | `keyboard_if.kicad_sch` | Keyboard link, **populate one**: DF40 2×6 stack (J5, DF40B-12DS) **or** 16-pin FFC cable (J6, AFC01-S16FCA-00) — I²C+UART+**VSYS** |
| QSPIFlash | `qspi_flash.kicad_sch` | 4 MB quad-SPI NOR (U7, W25Q32JVSSIQ) on OCTOSPI1 + CS# pull-up (R9) + decoupling (C26) |

**`calcumaker-keyboard`:**

| Sheet | File | Contents |
|---|---|---|
| Root | `calcumaker-keyboard.kicad_sch` | 5× `key_row` instances + 4 one-off sheets; per-row `ROW`→`KB_ROWn` + the RGB DIN→DOUT chain wired here |
| **key rows ×5** | `key_row.kicad_sch` ×4; `key_row_9.kicad_sch` ×1 | MX + 1N4148W + SK6812MINI-E + 100 nF per key. Row4 omits COL6 above the 2U ENTER: SW36/D36/D91/C136 absent. Shared COL1–10/VLED/GND; hierarchical ROW and RGB DIN/DOUT |
| Annunciators | `annunc.kicad_sch` | 5 status LEDs (f g C G low-batt, D51–55 + R1–5) ← the on-board G0 |
| KbdMCU | `kbd_mcu.kicad_sch` | **STM32G031K8U6 (U1, UFQFPN-32)** scanner + decoupling + BOOT0 + SWD (J2) |
| RGBPower | `rgb_power.kicad_sch` | RGB **level shifter (U2)** + **gated high-side load switch (Q1/Q2 + R7–10/C6–7)** — drives + sleep-gates the per-key chain off VSYS |
| MainIF | `main_if.kicad_sch` | MCU link, **populate one**: DF40 2×6 header (J1, DF40C-12DP) **or** 16-pin FFC (J3, AFC01-S16FCA-00) → the MCU board (+VSYS for the RGB) |

The MCU has **75 components**, zero ERC errors and one reviewed GPIO/power-flag
warning; the keyboard has **227 components** and zero ERC violations. Both pass
expanded netlist assertions. The display is unchanged by this wiring pass.
Custom symbols include TM1640, FJ5161AH, TCPP01-M12, MAX17048 and a
package-corrected STM32G031K8U6; provenance is in `hardware/lib/ATTRIBUTIONS.md`.

**`calcumaker-display`:**

| Sheet | File | Contents |
|---|---|---|
| Root | `calcumaker-display.kicad_sch` | Row1/Row2/Row3 + Interconnect + Aux + **DispMCU** (STM32G031) + **DispPower** (5V boost + shifter) sheet symbols |
| Row1/2/3 | `display_row.kicad_sch` (reused ×3) | **multi-channel** — 1 TM1640 + 16 single-digit FJ5161AH, fully wired (shared SEG bus + GRID1–16) |
| Interconnect | `interconnect.kicad_sch` | J1 ← MCU board (unified SPI; pinout matches mcu J3 + matrix J1) |
| AuxDisplay | `aux-display.kicad_sch` | DNP-optional SSD1306 OLED socket (J2) |

---

## Numeric Core

`firmware/calcumaker-core/` is the engine, with **one** numeric path:

- `Value` = `Int(gmp_mpfr_nostd::Integer)` (GMP) **or**
  `Real(gmp_mpfr_nostd::Float)` (MPFR).
- `Calc` = the RPN stack + token input; integers stay integers through
  `+ - * /` and the bitwise/shift ops; the scientific functions promote to MPFR
  reals. `float` / `round` / `trunc` / `floor` / `ceil` / `frac` convert
  between the kinds explicitly.
- **Exactness contract:** when the mathematical result of integer operands is
  an integer, it stays an exact GMP integer — `pow` (non-negative exponent,
  mpz_pow_ui, ~1 Mbit result cap, 0/±1 bases uncapped), `sq`, `exp10`, `fact`,
  and **division when it divides evenly** (`6 2 /` = exact 3). An inexact
  quotient **promotes to a real** (`3 2 /` = 1.5) — division never truncates
  silently; truncation lives only where it's expected and visible: under a
  word size (16C programmer division, annunciators lit) or the explicit
  `idiv`. **Number-type mode** (`tYPE` in SETUP; tokens `flexmode` /
  `intmode` / `realmode`): **FLE** (flexible, default) = the safe model above;
  **Int** = proper 16C integer mode as a setting — division truncates and
  sets Carry on an inexact quotient, unbounded included; **rEAL** = the
  float-machine model (plain decimal digits parse as reals) — SCI/FIN
  default. The FLOAT key enters rEAL (converting X, 16C-faithful); a radix
  key exits rEAL back to FLE (Int persists). INT/REAL annunciators show the
  non-default modes; counts/indexes accept integral reals everywhere.
  `sqrt` on an integer is the 16C-style **integer root** (⌊√x⌋, carry = the
  root was inexact; negative errors) — enter `2.0` or `float` for the real
  root. Negative exponents (fractional results) promote to MPFR.
- **HP-16C programmer model** under a word size (`<bits> wsize`; 0 = unbounded):
  - **Sign modes** `2s` / `1s` / `unsgn` (2's default). Values are stored as
    canonical signed integers; bitwise/shift/rotate ops act on the n-bit
    pattern; hex/oct/bin display the **pattern** (−15 @16b 2's = `FFF1`),
    decimal displays the signed value; non-decimal entry is a pattern, decimal
    entry a signed value. Mode / word-size changes reinterpret the stack
    **bit-pattern-preserving** (16C behaviour). 1's complement folds −0 onto 0.
  - **Flags:** **C** carry (add carry-out, subtract borrow, the bit shifted or
    rotated out, an inexact integer √) and **G** out-of-range (result wrapped).
  - **Leading zeros** (`lz`, 16C flag 3): pad hex/oct/bin display to the word
    width (`0F` @8 bits, `000F` @16).
  - `sl sr asr rl rr` act on X by one bit (the panel keys); `shl shr rln rrn`
    shift/rotate Y by X bits; `rlc rrc` (+`rlcn rrcn`) rotate through the
    carry — an (n+1)-bit rotation. `bset bclr btest maskl maskr popcnt` cover
    the bit ops (`btest` leaves the value in Y and pushes 0/1); `lj`
    left-justifies (Y = value, X = count); `dbl* dbl/ dblr` are the 16C
    double-word ops (2's comp / unsigned only — 1's-comp −0 makes the double
    word ambiguous).
  - **Flags 0–5** (`sf`/`cf`/`ftest`, index from X): 0–2 user bits, 3/4/5 alias
    leading-zeros / carry / overflow. `clreg` wipes the STO registers.
    SHOW (f-shifted radix keys) displays X in another base transiently.
- **16 STO/RCL registers** (`sto0`…`stof` / `rcl0`…`rclf` — one per hex digit
  key; on the keypad STO/RCL wait for the next digit key).
- **Real display formats:** AUTO (`%g`-style) / `FIX n` / `SCI n` / `ENG n`
  (digit count from X; `std` = back to AUTO). Inf/NaN display as `inf`/`nan`.
- **Angle modes** `rad` (default) / `deg` / `grad` for the circular trig
  (hyperbolics unaffected; g-shift WSIZE cycles). Conversions run through MPFR
  π with 32 guard bits; DEG/GRAD reduce mod the full circle **exactly** (fmod)
  and special-case exactly-representable angles — `deg 180 sin` = 0 (not a
  2^-prec residue), `30 sin` = 0.5, `45 tan` = 1, `0.5 asin` = 30; tan at
  90°/270° shows `inf`.
- **Errors never consume operands** — every op validates stack depth, types,
  and domain before popping (and LASTx updates only on success), so a failed
  op leaves the calculator exactly as it was (HP behaviour).
- HAL-free and fully **host-testable** (`cargo test`) + runnable
  (`cargo run --example repl`, or the full UI in `calcumaker-emu`).

The firmware consumes this crate; on the target the only thing that changes is
where GMP/MPFR come from (cross-built, linked at the FFI layer) — the engine code
is identical.

---
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

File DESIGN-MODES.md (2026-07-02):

# Calcumaker 16 — Personalities & Modes (design plan)

> **Status: PLAN, not implemented.** This documents how we intend to support
> HP-variant "personalities" and additional display/interaction modes on the
> same hardware and engine. Nothing here changes current behavior; the
> calculator today is one personality — the HP-16C-lineage programmer model
> described in `DESIGN.md`. Implementation is phased at the end.

## 1. Motivation

The hardware — 50 Cherry MX keys with f/g shifts, 3×16 seven-segment rows —
and the engine — arbitrary-precision GMP/MPFR under an RPN stack — are far
more general than the 16C keymap currently bolted onto them. The same device
could plausibly host a scientific personality (HP-15C lineage), a financial
one (HP-12C lineage), or user-tuned variants, and users may want interaction
options (classic 4-level stack discipline) independent of any personality.

## 2. Vocabulary

Three distinct concepts, kept orthogonal:

| Term | What it is | Examples | Lives in |
|---|---|---|---|
| **Personality** | A coherent keymap + exposed function set + display conventions | `16C` (default), `SCI` (15C-flavored), `FIN` (12C-flavored), `NATIVE` (superset) | `keys::Keymap` + App |
| **Mode** | An orthogonal setting *within* a personality | radix, word size, sign mode, angle unit, FIX/SCI/ENG, lz — all already exist | `Calc` |
| **Interaction mode** | How the stack/entry behaves, independent of keymap | unbounded stack (current) vs **classic 4-level** X/Y/Z/T | `Calc` |

The engine (`Calc`) stays personality-agnostic: it is a superset of functions,
and a personality merely selects which ones are reachable from keys and how
results are displayed. This preserves the single-code-path principle — no
per-personality math.

## 3. The hardware constraint that shapes everything

**Keycap legends are printed.** A physical unit cannot relabel its keys, but
that constrains *legends*, not *switching*:

- **Runtime switching works on hardware too** — a personality is firmware
  state, selected from the **SETUP menu** (see §5.6; the menu itself is
  implemented today for the display/interaction tunables, and the
  personality selector becomes one more entry, `PErS`, in P1). Legends of
  the printed personality then simply don't match — acceptable for field
  debugging and for HP-hobbyist users, and the emulator relabels for free.
- A physical device still ships with **one printed personality** (a keycap
  SKU decision at ordering time — same PCB, different caps). Cherry MX makes
  this cheap: relegendable or swapped keycap sets, and the hot-swap socket
  option already in the design allows switch/cap experimentation.
- The **NATIVE** personality is the escape hatch: a superset keymap where the
  printed 16C legends stay truthful and extras live on f/g layers — this is
  approximately what exists today and remains the default.

## 4. Personalities planned

### 4.1 `16C` / `NATIVE` (current — formalize only)
What is implemented now: the full 16C programmer model plus our extensions
(arbitrary precision `prec`, angle modes, FIX/SCI/ENG, exact-integer
contract). Formalizing means naming it and routing it through the `Keymap`
struct rather than file-level consts. **No behavior change.**

### 4.2 `SCI` — HP-15C-flavored scientific (✅ implemented)
- **Keymap** (`keys::SCI`): digits/ENTER/shifts/arithmetic/STATUS/SETUP at
  the identical physical positions as 16C; the hex-digit row becomes inverse
  trig + log10/eˣ/10ˣ, the bitops row becomes Σ+/Σ−/mean/sdev/x!/%, the
  radix row becomes FIX/SCI/ENG/auto/angle-mode. f = hyperbolics +
  L.R./ŷ/r/CLΣ; g = nCr/nPr/RAN#/seed (+ the shared window keys).
- **Engine additions** (all in, engine superset as designed): Σ registers at
  working precision (`s+ s- mean sdev lr yhat corr clstat`), **exact** GMP
  `ncr`/`npr` (mpz binomial; size-guarded), `ran`/`seed` (xorshift64,
  deterministic until seeded; firmware seeds from hardware entropy).
- **Explicitly out of scope for SCI v1**: 15C complex numbers and matrices
  (MPC — own design round if ever).
- **Display defaults on switch** (`Keymap::apply_defaults`): DEG, FIX 4,
  decimal; 16C's bundle restores RAD + AUTO. Data (stack/registers/prec) is
  never touched by a switch.
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

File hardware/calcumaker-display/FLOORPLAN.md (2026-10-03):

# Seven-segment PCB floor plan — 2026-10-02

`calcumaker-display.kicad_pcb` is the editable KiCad 10 source: **86 components,
13 groups, two copper layers**, with no routing. The provisional **226 × 94 mm**
outline runs from (50,50) to (276,144). This is wider than the 200.50 mm keyboard;
the two display alternatives do not yet share a qualified enclosure interface.

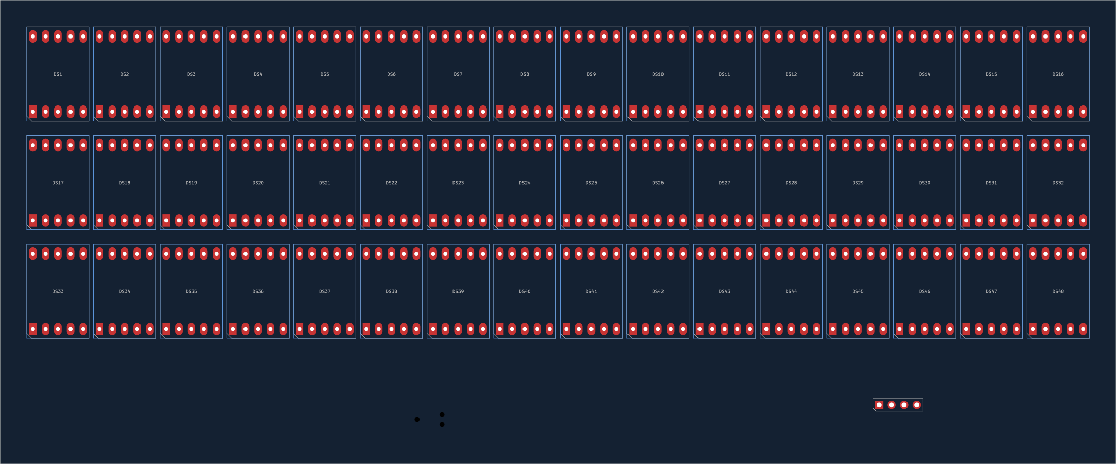
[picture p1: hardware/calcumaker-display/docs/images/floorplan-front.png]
Front placement


## Display and electronics
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

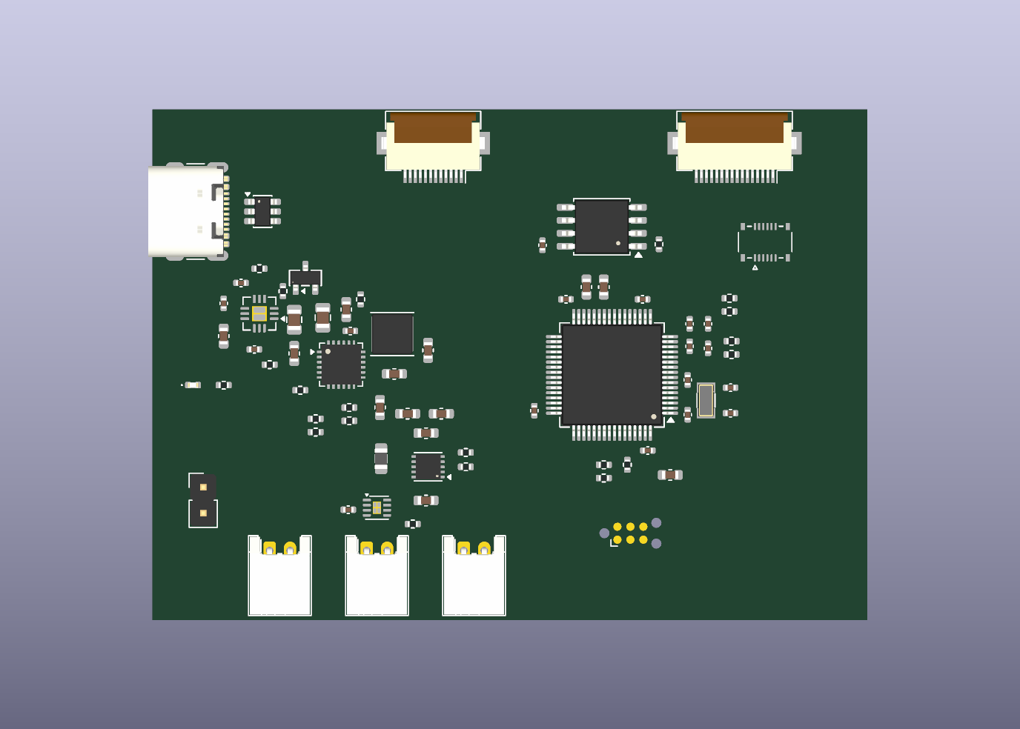
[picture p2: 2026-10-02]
hardware/calcumaker-mcu/docs/images/pcb-floorplan-top.png

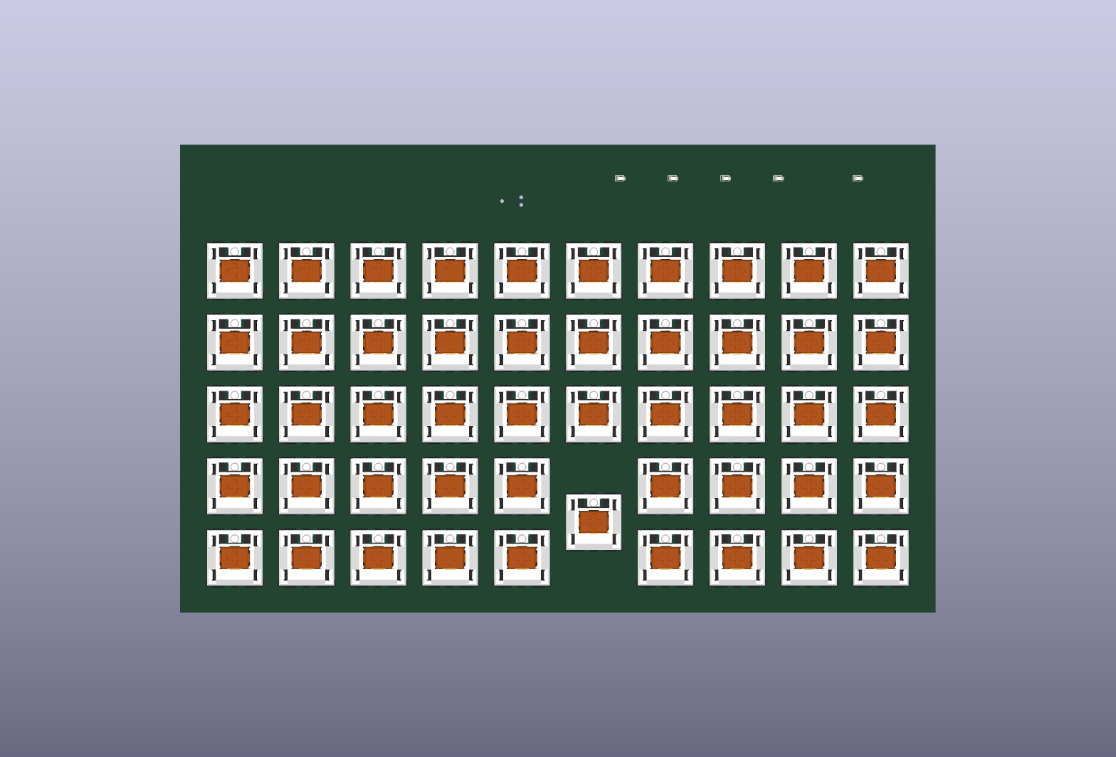
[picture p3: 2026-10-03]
hardware/calcumaker-keyboard/docs/images/pcb-floorplan-top.png

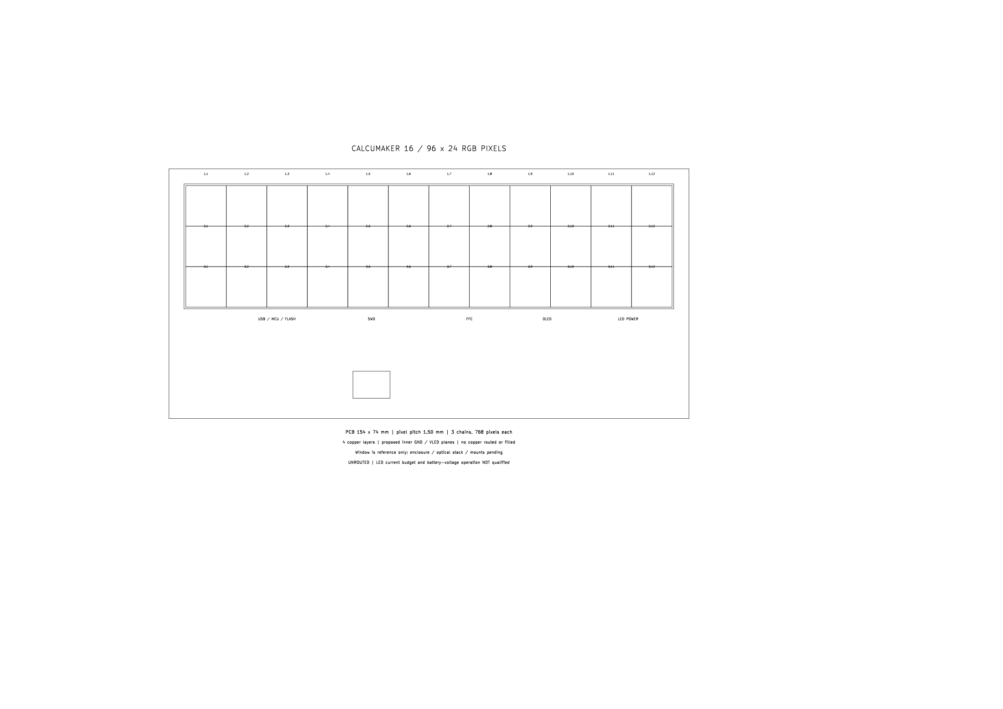
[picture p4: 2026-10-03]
hardware/calcumaker-matrix/docs/images/display-reference.png

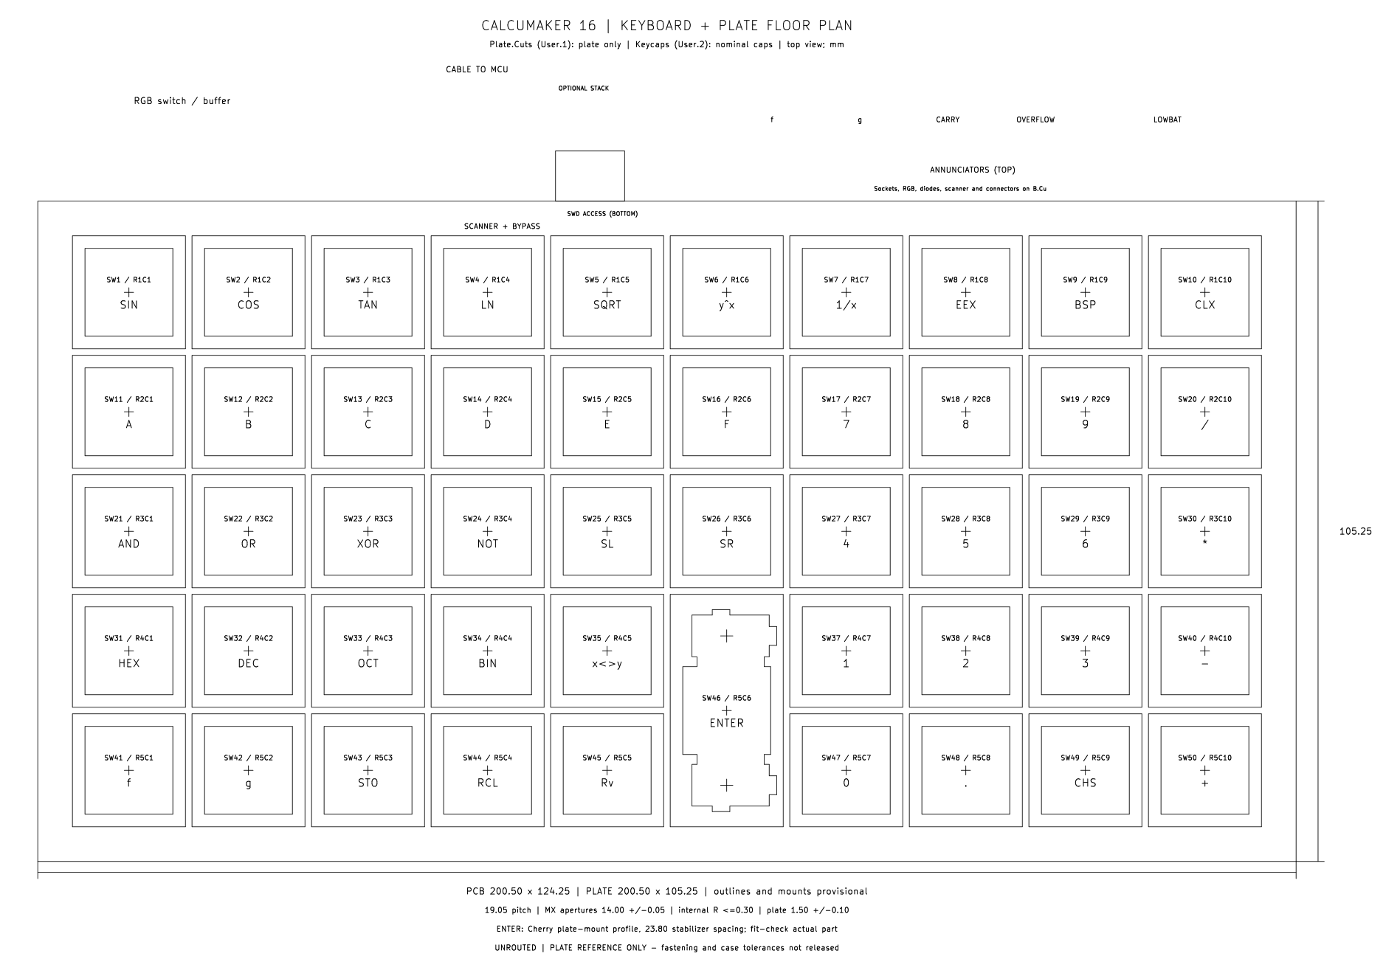
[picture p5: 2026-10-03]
hardware/calcumaker-keyboard/docs/images/keyboard-plate-reference.png

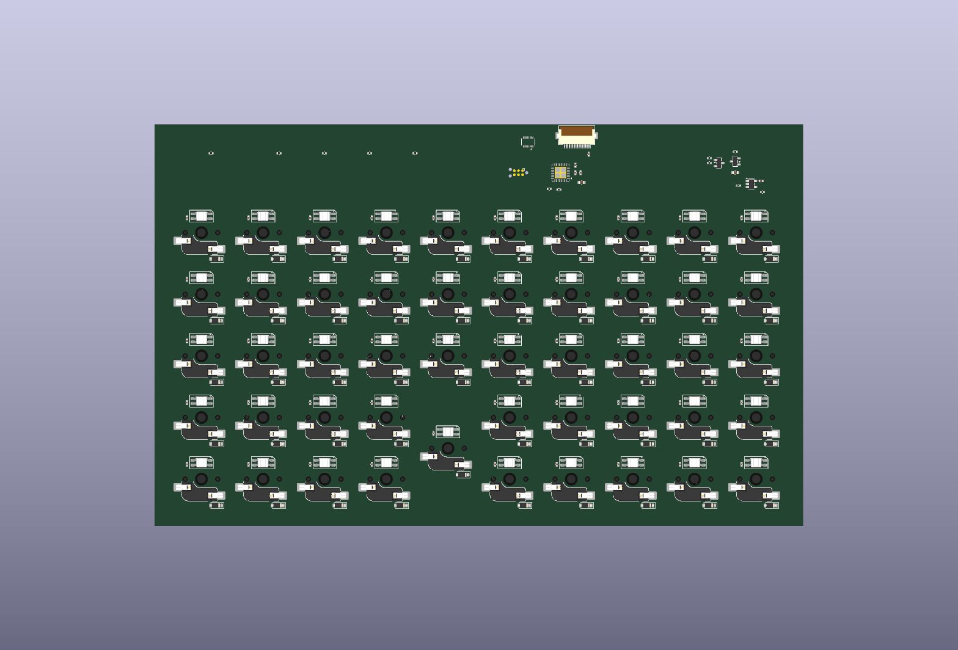
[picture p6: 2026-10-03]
hardware/calcumaker-keyboard/docs/images/pcb-floorplan-bottom.png

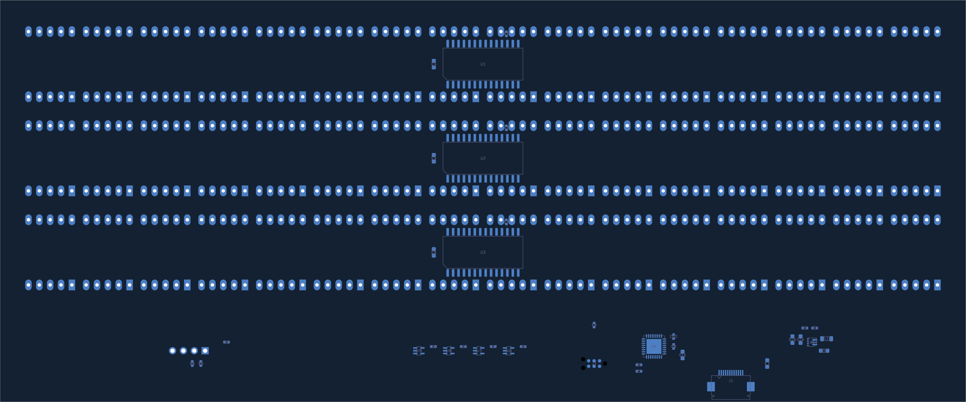
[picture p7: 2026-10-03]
hardware/calcumaker-display/docs/images/floorplan-back.png

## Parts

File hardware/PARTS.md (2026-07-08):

# Calcumaker 16 — Parts

Source-of-truth mapping: each line → a real **LCSC** part (for the JLCPCB BOM).
LCSC/MPN/Manufacturer are set as KiCad symbol fields when parts are placed, so
`make bom-<board>` emits a JLCPCB BOM. `✅` = resolved by availability research;
`TBD` = pending an Open Question (see `../DESIGN.md`).

> Prices/stock are point-in-time (fetched during scaffolding, 2026-06); re-verify
> at order time. All ICs/displays below are JLCPCB **Extended** (no Basic option
> in these categories).

## calcumaker-mcu (MCU / PSU / clock / SWD / display-IF / keyboard mezzanine / QSPI flash)

*Bottom of the stack; the dense fine-pitch SMT brain board.*

| Block | Part | LCSC | Pkg / footprint | Status |
|---|---|---|---|---|
| MCU | **STM32U575RGT6** | **C5270980** | LQFP-64 | ✅ ~$4.90 — **1MB** flash (fw links ~323KB); smaller pkg now the matrix scans off-board |
| **QSPI flash** | **W25Q32JVSSIQ** (4MB / 32Mbit quad-SPI NOR) | **C179173** | SOIC-8 (`SOIC-8_5.3x5.3mm`) | ✅ ~$0.30 (23k stock) — on OCTOSPI1; XIP constants + state/program storage; U7 + R9 CS-pullup + C26 |
| USB-C | GCT USB4105 (USB2.0 16P) | C2927039 | TopMnt horizontal | ✅ (from ephemerkey PSU) |
| ESD | USBLC6-2SC6 | C2687116 | SOT-23-6 | ✅ |
| Charger | MCP73831T-2ACI/OT | C424093 | SOT-23-5 | ✅ (PROG sized to cell) |
| Load-share FET | AO3401A (P-MOS) | C15127 | SOT-23 | ✅ |
| Load-share diode | B5819W (Schottky) | C8598 | SOD-123 | ✅ |
| Buck-boost 3V3 (MCU) | TPS63900DSKR | C1518762 | WSON-10 | ✅ MCU-only (light load); ULP low-Iq |
| 3V3 inductor | 2.2µH | TBD | **0805/2016** | smallest reasonable; verify Isat for TPS63900 |
| 5V boost (display) | **TPS61022RWUR** (EN-gated, adj.) | **C915088** | VQFN-7 2×2 | ✅ ~$0.32; FB divider R6 732k/R7 100k → 5V |
| 5V boost inductor | **FTC201610S1R0MBCA** 1µH | **C5832342** | 2.0×1.6mm | ✅ ~$0.04 (smallest reasonable for ~2A) |
| 5V boost caps | 10µF in + 2×22µF out (16V) | (PARTS) | **0603** | smallest at voltage |
| Level shifter | **SN74HCT125DR** (quad, VCC=5V, 3V3→5V) | **C352957** | SOIC-14 | ✅ ~$0.20; KiCad symbol = `74AHCT125` |
| Battery conn | JST S2B-PH-K-S | C173752 | PH 2.0 | ✅ |
| RTC xtal | Epson 32.768 kHz | C32346 | SMD 3215 2-pin | ✅ LSE (Clock sheet) + 2× 12pF load caps |
| Display interconnect (J3) | **AFC01-S12FCA-00** 0.5mm 12P FFC | **C262661** | `Hirose_FH12-12S-0.5SH` | ✅ **Unified SPI module bus** — identical pinout on BOTH display boards (7-seg + RGB matrix) → **interchangeable**. Carries VSYS + 3V3 + SPI "display intent" + reset/boot (no CLK/DIN, no I2C). **Cable = GCT FFC05-TIN `05-12-A-<len>-A-4-06-4-T`, DigiKey (non-BOM).** |
| Matrix LED-power outlet (J7) | JST **S2B-PH-K-S** 2-pin | **C173752** | PH 2.0 | ✅ VSYS lead → the RGB-matrix module's LED inlet (amps for 2304 LEDs, kept **off** the signal FFC). DNP for a 7-seg-only build. |
| 5V boost / 74HCT125 shifter | — | — | — | ⬦ **MOVED to the 7-seg display board** (the unified FFC is now technology-agnostic); the module generates 5V + shifting locally. |
| I2C pull-ups | 4.7k 0402 ×2 (R14/R15) | C25900 | 0402 | ✅ DNP — populate with the aux OLED |
| Keyboard link — **stack** (J5) | **Hirose DF40B-12DS-0.4V** 2×6 0.4mm B2B | **C3641147** | `Connector_Hirose_DF40:…DF40B-12DS-0.4V_2x06` | ⬦ **populate for a stacked build** (else DNP); ~1.5mm; mates kbd J1 DF40C-12DP. (DF40C-12DS unstocked → DF40B; same 1.5mm — suffix sets height, not B/C) |
| Keyboard link — **cable** (J6) | **AFC01-S16FCA-00** 16-pin 0.5mm FFC | **C262665** | `Connector_FFC-FPC:Hirose_FH12-16S-0.5SH_1x16` | ⬦ **populate for a cabled build** (else DNP) → MCU board mounts freely; 16-pin ≠ 12-pin display FFC; VSYS×2+GND×3; same 12 nets as J5 |
| Programming | SWD Tag-Connect TC2030-NL | — | pogo pad | ✅ (no part placed) |

## calcumaker-keyboard (Cherry MX matrix + STM32G0 scanner + annunciators + per-key RGB + MCU mezzanine)

*Top of the stack; the front-panel board the user types on. Mezzanine-stacks
above the MCU board. Its own STM32G0 scans the matrix + drives the annunciators
and talks to the U575 over I²C/UART (keyscanning is off the MCU board).*

| Block | Part | LCSC | Pkg / footprint | Status |
|---|---|---|---|---|
| **Scanner MCU (U1)** | **STM32G031K8U6** | **C432207** | UFQFPN-32 (`UFQFPN-32-1EP_5x5mm`) | ✅ ~$0.60; scans matrix + drives LEDs + I²C/UART to U575; QFN like tsumikoro's G0 |
| G0 decoupling | 100nF ×3 + 4.7µF (C1–C4) | C1525 / — | 0402 / 0603 | VDD/VDDA + bulk |
| G0 NRST / BOOT0 | 100nF (C5) + 10k (R6) | C1525 / C25744 | 0402 | reset cap + BOOT0 pulldown |
| Keyswitches ×50 | Cherry MX (full size, user-supplied) | — | **`calcumaker:SW_MX_HS_CPG151101S11_1u`** (hot-swap, vendored) | 5×10 → the **G0**; **place-on-back** (socket → bottom, keycaps up); **hot-swap only** — thru-holes are 0.15mm-ring socket pass-throughs, NOT solder pads; SW1–50 |
| Hot-swap socket ×50 | **Kailh CPG151101S11** | **C41430893** | (SMD pads in the switch fp) | ✅ ~93k stock, JLCPCB-assemblable (bottom-side); switches plug in. Solder-in-only would be a separate board rev (fp `SW_Cherry_MX_1.00u_PCB`) |
| Key diodes ×50 | 1N4148W | C81598 | SOD-123 | ✅ one per key (NKRO); D1–D50 |
| Annunciator LED f (gold) | Everlight 19-213/Y2C (yellow) | C72038 | **0603** | ✅ D51, beside the f key (driven by the G0) |
| Annunciator LED g (blue) | XL-1608UBC-04 | C965807 | **0603** | ✅ D52, beside the g key |
| Annunciator LEDs C / G / low-batt | KT-0603R (red) ×3 | C2286 | **0603** | ✅ D53–D55, top edge under the display bezel |
| Annunciator resistors ×5 | 470 Ω | C25117 | 0402 | ✅ R1–R5 (~1.3–2.8 mA @3V3; tune per color at bring-up) |
| G0 programming (J2) | SWD Tag-Connect TC2030-NL | — | pogo pad | ✅ (bare land) — or reflash via the UART/DFU bootloader over J1 |
| **Per-key RGB ×50 (D56–D105)** | **SK6812MINI-E** reverse/bottom-mount addressable RGB | **C5149201** | `LED_SMD:LED_SK6812MINI-E_3.2x2.8mm_P1.5mm_ReverseMount` | ✅ ~161k stock; **bottom-mount → single-sided assembly w/ the Kailh sockets**; shines up through the switch; daisy-chained off the G0 |
| RGB level shifter (U2) | **SN74LVC1G125** single buffer (3V3→VLED data) | **C23654** | SOT-23-5 | ✅ powered from the gated LED rail; /OE→GND; lifts data to LED V_IH |
| RGB load switch (Q1/Q2) | **AO3401A** P-FET + **2N7002** N-FET + R7–R10/C6/C7 | **C15127** / **C8545** | SOT-23 | ✅ high-side gate on VSYS→VLED; G0 `LED_EN` cuts LEDs in sleep (near-zero leakage) |
| MCU link — **stack** (J1) | **Hirose DF40C-12DP-0.4V** 2×6 0.4mm B2B | **C6224952** | `Connector_Hirose_DF40:…DF40C-12DP-0.4V_2x06` | ⬦ **populate for a stacked build** (else DNP); mates mcu J5 DF40B-12DS; ~1.5mm; pinout MUST match |
| MCU link — **cable** (J3) | **AFC01-S16FCA-00** 16-pin 0.5mm FFC | **C262665** | `Connector_FFC-FPC:Hirose_FH12-16S-0.5SH_1x16` | ⬦ **populate for a cabled build** (else DNP) → to mcu J6; same 12 nets; the recommended default (frees the crowded keyboard bottom) |

## calcumaker-display (7-seg **smart module**: G0 + drivers + local 5V + unified SPI)

*A self-contained display **module** — its own STM32G031 (U4) receives "display
intent" over the unified SPI connector and renders it to the 3 TM1640s. Plugs into
the same connector as, and is **interchangeable** with, the RGB-matrix module.*

| Block | Part | LCSC | Pkg / footprint | Status |
|---|---|---|---|---|
| **Module MCU (U4)** | **STM32G031K8U6** | **C432207** | UFQFPN-32 | ✅ SPI-slave frame receiver (same part as the keyboard scanner); drives the TM1640s locally |
| Driver ×3 | TM1640 | C5337152 | SOP-28 | ✅ ~$0.12 — 1 chip = 1 row of 16 CC digits |
| Digits ×48 | FJ5161AH (0.56" **single-digit**, **common-cathode**) | C8093 | **THROUGH-HOLE** | ✅ ~$0.10 — **16 per row** |
| Local 5V boost (U5) | **TPS61022RWUR** | **C915088** | VQFN-7 | ✅ VSYS→5V (moved off the MCU board); FB R2 732k / R3 100k |
| 5V boost inductor (L1) | FTC201610S1R0MBCA 1µH | **C5832342** | 2.0×1.6mm | ✅ |
| Level shifter (U6) | **SN74HCT125DR** | **C352957** | SOIC-14 | ✅ G0 3V3 → 5V for CLK+DIN1/2/3 to the TM1640s |
| Interconnect (J1) | **AFC01-S12FCA-00** 0.5mm 12P FFC | **C262661** | `Hirose_FH12-12S-0.5SH` | ✅ **Unified SPI** ← MCU board (mcu J3); identical pinout to the matrix J1. **Cable = GCT FFC05-TIN, DigiKey (non-BOM).** |
| SWD (J3) | Tag-Connect TC2030-NL | — | pogo pad | ✅ program U4 |
| Aux OLED socket (J2) | PZ254V-11-04P (1×4 2.54mm) | C2691448 | header THT | ✅ DNP — 0.91″ SSD1306 128×32, now driven **locally** by U4's I2C |

**Topology:** 3 rows × 16 digits = **48 single digits**, driven by 3× TM1640
(reusable `display_row.kicad_sch` ×3: Row1→U1/DS1–16, Row2→U2/DS17–32,
Row3→U3/DS33–48; top row optional). The module **STM32G031 (U4)** is the SPI
slave — it receives display intent from the U575 over the unified connector and
bit-bangs the TM1640s locally (CLK+DIN1/2/3 level-shifted 3V3→5V by U6, 5V from
the local U5 boost). So the driver protocol never crosses the FFC, which is why
the connector is identical to the RGB-matrix module's and the two swap freely.

## calcumaker-matrix (RGB dot-matrix **smart module**: RP2040 + 1 mm WS2812 + unified SPI)

*The alternative display module — a full-color **96×24** addressable-RGB dot
matrix. Its **RP2040** (PIO = ideal WS2812 engine) receives "display intent" over
the same unified SPI connector and renders it. Interchangeable with the 7-seg
module. Also delivers the full-alphanumeric / scrolling / color the 7-seg can't.*

| Block | Part | LCSC | Pkg / footprint | Status |
|---|---|---|---|---|
| **Pixels ×2304 (D1–D2304)** | **XL-1010RGBC-2812B-S** (1×1 mm addressable RGB, WS2812/SK6812, 3.5–5.5 V) | **C51900942** | `calcumaker:LED_XL1010RGBC_1.0x1.0mm` (authored) | ✅ ~$0.034 — 96×24 grid; symbol = stock `LED:SK6812` (overridden). **VERIFY 1010 land vs datasheet + get a JLC fine-placement quote (2304 parts).** |
| **Module MCU (U1)** | **RP2040** | **C2040** | QFN-56 (stock KiCad sym + fp) | ✅ PIO drives 3 WS2812 chains; SPI slave; needs U2 flash; embassy-rp fw |
| Boot flash (U2) | W25Q32JVSSIQ | **C179173** | SOIC-8 | ✅ RP2040 QSPI code flash (same part the MCU board stocks) |
| USB ESD (U3) | USBLC6-2SC6 | C2687116 | SOT-23-6 | ✅ on the BOOTSEL USB-C |
| Data shifter (U4) | **74LVC125** quad | **C460512** | SOIC-14 | ✅ 3V3 → VLED for the 3 chains (3 of 4 buffers) |
| LED load switch | AO3401A (Q1) + 2N7002 (Q2) | C15127 / C8545 | SOT-23 | ✅ high-side VSYS→VLED gate; `LED_EN` off in sleep |
| LED-power inlet (J2) | JST S2B-PH-K-S 2-pin | C173752 | PH 2.0 | ✅ VSYS from the MCU board (mcu **J7**) — LED amps, kept **off** the FFC |
| Interconnect (J1) | **AFC01-S12FCA-00** 0.5 mm 12P FFC | **C262661** | `Hirose_FH12-12S-0.5SH` | ✅ **Unified SPI** ← MCU board (mcu J3); identical pinout to the 7-seg J1 |
| USB-C prog (J4) | GCT USB4105 | C2927039 | 16P TopMnt | ✅ BOOTSEL/DFU (drag-drop UF2) |
| Crystal (Y1) | 12 MHz | TBD | SMD 3225 2-pin | ⬦ pick LCSC at BOM |
| BOOTSEL button (SW1) | tactile SMD | TBD | SMD | ⬦ pick LCSC at BOM |
| Aux OLED socket (J3) | PZ254V-11-04P (1×4) | C2691448 | header THT | ✅ DNP; driven locally by U1's I2C |

**Topology (nested multi-channel: cluster → row → board).** An 8×8 = 64-LED
**cluster** (`led_cluster.kicad_sch`) is instantiated **12×** into a **row**
(`led_row.kicad_sch` = 96×8 = 768 px = one WS2812 chain), and the row is
instantiated **3×** at the root = **96×24 = 2304 px** (D1–D2304). Each stack row is
one data chain off an RP2040 PIO line via the quad shifter. Pixels ≈ **$78** +
placement; **4-layer** board (VLED + GND planes) at ~1.5 mm pitch. LED current
takes the dedicated VSYS inlet (J2), **not** the signal FFC; firmware **must** cap
total brightness. `-S` pixel = 3.5 V floor → gate/dim on a VBAT sense when low.

## Non-BOM accessories (ordered separately, not JLCPCB-assembled)

| Item | Part | Source | Notes |
|---|---|---|---|
| Display FFC cable | **GCT FFC05-TIN** `05-12-A-<len>-A-4-06-4-T` | **DigiKey** (cheap) | 0.5mm, 12-cond; **length TBD at layout**; `A`=same-side / `D`=opposite-side contacts per the two connectors' mounting |
| Aux OLED module | 0.91″ SSD1306 128×32 I2C | any | plugs into display J2 (DNP socket) |
| Stacking standoffs ×4 | M2 (matched to the DF40 ~1.5mm stack) | any | set the MCU↔keyboard gap; take mechanical load |
| Battery cell | 1S Li-ion + JST-PH lead | any | capacity TBD |

## Important assembly note — through-hole digits

No SMD multi-digit 7-segment displays are stocked on LCSC; the well-stocked
parts are **through-hole**. So `calcumaker-display` needs **THT assembly**
(JLCPCB through-hole add-on, or hand/wave solder) in addition to SMT for the
TM1640s. The MCU and keyboard boards are mostly SMT plus their connectors and
through-hole switches as applicable. If an all-SMT display is a hard
requirement, revisit driver+digit selection (would likely mean discrete SMD
single-digit displays — more parts).

## KiCad symbols

- **Digits (FJ5161AH):** **single-digit** 0.56" common-cathode (LCSC C8093 —
  confirmed a **1-digit** part, NOT a 4-up module). Symbol **authored** as
  `calcumaker:FJ5161AH` in `lib/symbols/calcumaker.kicad_sym` (standard 5161
  pinout: 1=E 2=D 3=COM 4=C 5=DP 6=B 7=A 8=COM 9=F 10=G) + the dimensionally-
  matched 0.56" single-digit land `Display_7Segment:7SegmentLED_LTS6760_LTS6780`.
  *Verify the FJ5161AH pad map vs the LTS6760 land at layout.*
  ⚠ **The earlier `Display_Character:CC56-12EWA` / `CC56-12GWA` mapping was WRONG**
  — that's a **4-digit** symbol/footprint/3D, which is where the phantom "clock
  colon" came from. There is no colon on the real single-digit part.
- **RGB-matrix pixel (XL-1010RGBC-2812B-S):** symbol = **stock `LED:SK6812`**
  (value/fp/lcsc overridden — kschgen doesn't resolve `extends`); the 1×1 mm 4-pad
  land is **authored** as `calcumaker:LED_XL1010RGBC_1.0x1.0mm` (pads 1=VSS 2=DIN
  3=VDD 4=DOUT, matching the SK6812 symbol). *Verify the 1010 land + net-to-corner
  mapping vs the XINGLIGHT datasheet before fab.*
- **RP2040 + support (matrix):** all **stock** KiCad — `MCU_RaspberryPi:RP2040`
  (QFN-56), `Memory_Flash:W25Q32JVSS`, `74xx:74LVC125`, `Transistor_FET:Q_PMOS/NMOS_GSD`,
  `Power_Protection:USBLC6-2SC6`. So the only authored part on the matrix board is
  the 1010 land above.
- **Driver (TM1640):** not in KiCad — **authored** from the datasheet pinout in
  `lib/symbols/calcumaker.kicad_sym` (28-pin SOP-28: GRID12–16=1–5, VSS=6, DIN=7,
  SCLK=8, SEG1–8=9–16, VDD=17, GRID1–11=18–28), registered via `register_lib` in
  `scripts/calcumaker-display.schgen.py`. ✅ Generates + passes the structure
  check. *Confirm the SOIC-28W footprint vs the TM1640 SOP-28 package drawing.*
- **Level shifter (SN74HCT125):** use the **stock** `74xx:74AHCT125` symbol
  (pin-identical quad buffer; value = `74HCT125`) + `Package_SO:SOIC-14_3.9x8.7mm`.
  ✅ No custom symbol.
- **5V boost (TPS61022):** stock `Converter_DCDC:TPS61022` symbol +
  `Package_DFN_QFN:Texas_RWU0007A_VQFN-7_2x2mm_P0.5mm` footprint. ✅ No custom
  symbol.
- **MCU (STM32U575RGT6):** stock `MCU_ST_STM32U5:STM32U575RGTx` symbol +
  `Package_QFP:LQFP-64_10x10mm_P0.5mm`. ✅ No custom symbol.
- **QSPI flash (W25Q32JVSSIQ):** stock `Memory_Flash:W25Q32JVSS` symbol +
  `Package_SO:SOIC-8_5.3x5.3mm_P1.27mm`. ✅ No custom symbol.

## Passive size policy

Per project policy: **0402** for resistors + decoupling/small caps; **0603** for
bulk MLCCs (10/22µF — true-0402 10µF is 6.3V-only, too low for the 5V rail).
Magnetics: **smallest reasonable** from the JLCPCB catalog (boost L = 2.0×1.6mm
1µH; the 3V3 buck-boost L downsized to 0805/2016 — verify Isat).

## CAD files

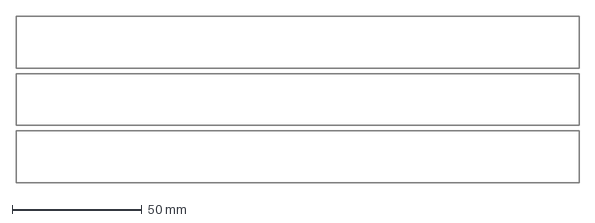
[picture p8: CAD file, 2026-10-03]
hardware/calcumaker-display/mechanical/viewing-windows.dxf
217.0 x 64.0 mm

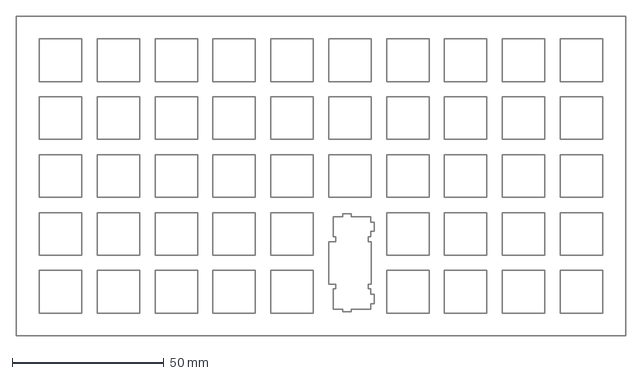
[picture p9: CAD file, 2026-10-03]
hardware/calcumaker-keyboard/mechanical/keyboard-plate.dxf
200.5 x 105.2 mm

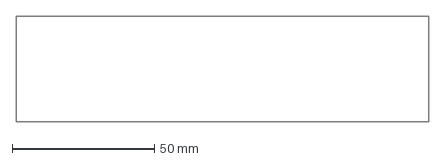
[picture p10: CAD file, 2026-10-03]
hardware/calcumaker-matrix/mechanical/viewing-windows.dxf
145.0 x 37.0 mm

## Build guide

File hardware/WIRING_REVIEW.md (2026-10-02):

# Mainboard and keypad wiring review — 2026-10-02

The MCU and keyboard schematics are now connected KiCad 10 hierarchies. Edit the
committed `.kicad_sch` files in KiCad; the guarded `*.schgen.py` manifests describe
an earlier placement draft and must not be forced over this wiring.

## What is connected

- Mainboard: MCU supplies and VCAP, LSE, reset/boot/SWD, display interface,
  six QSPI signals, keyboard interfaces, USB data/CC protection, charger,
  fuel gauge, battery/VBUS measurement and 3.3 V regulator.
- Keypad: scanner MCU, 49 switch/diode pairs, five annunciators, RGB power
  switch/buffer, 49 RGB LEDs in one chain and 49 local bypass capacitors.
- Parent sheets carry explicit signal ports and wires. Repeated key rows share
  the column and supply globals; each row's scan and RGB ports stay hierarchical.
  Row4 uses the nine-key variant. SW36/D36/D91/C136 are intentionally absent
  above the lower-cell 2U ENTER switch (SW46).
- Existing real component identities were retained; repeated-sheet annotation
  and project root paths were repaired for KiCad 10. Added components have
  distinct references and all 302 components have assigned footprints.

## Checks

From `hardware/`:

```sh
make check-wiring check-calcumaker-mcu check-calcumaker-keyboard
```

`check-wiring.py` exports fresh KiCad XML netlists and ERC JSON. It rejects
annotation errors, duplicate references, missing footprints, unexpected ERC
violations and failed electrical assertions. It checks package-pin assignments,
connector parity, every matrix series connection, diode polarity, the complete
49-LED chain, every RGB bypass, supply separation, reset/debug, QSPI, charger
controls and regulator configuration. To retain reports:

```sh
uv run python scripts/check-wiring.py --output-dir /tmp/calcumaker-check
```

Verified with KiCad 10.0.6:

| Board | Components | ERC errors | ERC warnings |
|---|---:|---:|---:|
| MCU | 75 | 0 | 1 reviewed |
| Keyboard | 227 | 0 | 0 |

The sole mainboard warning is U1 PC6/pad37 versus PSU `#FLG06` on `TCPP01_EN`.
PC6 supplies TCPP01 VCC as specified by its GPIO-powered application circuit;
KiCad models the GPIO as bidirectional. The power flag declares this supply
intent. The checker accepts only that particular pair of pin UUIDs, and also
asserts the net's exact membership. The ERC rule remains enabled project-wide.
This is a documented electrical-model warning, not a claim of measured hardware.

## Connector contract

UART names are from the **mainboard's perspective**: `UART_TX` is main PA2 to
keyboard PA3, and `UART_RX` is keyboard PA2 to main PA3. Populate either the stack
connector or the FFC pair. Verify physical contact orientation before layout.

| Pin | Stack: main J5 / keyboard J1 | FFC: main J6 / keyboard J3 |
|---:|---|---|
| 1 | +3V3 | +3V3 |
| 2 | GND | GND |
| 3 | I2C_SDA | I2C_SDA |
| 4 | I2C_SCL | I2C_SCL |
| 5 | UART_TX | UART_TX |
| 6 | UART_RX | UART_RX |
| 7 | KB_IRQ | KB_IRQ |
| 8 | KB_NRST | KB_NRST |
| 9 | KB_BOOT0 | KB_BOOT0 |
| 10 | GND | GND |
| 11 | VSYS | VSYS |
| 12 | GND | VSYS |
| 13–14 | — | GND |
| 15–16 | — | deliberate NC |

## Pin assignments added or corrected

The full U575 QSPI/SPI/UART/I2C map remains in [DESIGN.md](../DESIGN.md).
**U575 PB15 is LQFP64 pad36; pad63 is VSS.**

| Mainboard function | GPIO | Pad |
|---|---|---:|
| Keyboard interrupt / reset / boot | PA0 / PC10 / PC11 | 14 / 51 / 52 |
| Charger INT / PG / CE | PC2 / PC4 / PC5 | 10 / 24 / 25 |
| TCPP VCC-enable / DB / fault | PC6 / PC7 / PC3 | 37 / 38 / 11 |
| Gauge alert | PC13 | 2 |
| VBUS ADC / battery ADC | PC0 / PC1 | 8 / 9 |
| Display IRQ / reset / boot | PB12 / PC8 / PC9 | 33 / 39 / 40 |

| Keyboard function | G031 GPIOs, in signal order | UFQFPN32 pads |
|---|---|---|
| ROW1–5 | PA8, PA9, PA10, PA11, PA12 | 18, 19, 21, 22, 23 |
| COL1–10 | PA0, PA1, PB2, PB3, PA4, PA5, PA6, PA7, PC14, PC15 | 7, 8, 17, 27, 11, 12, 13, 14, 2, 3 |
| F / G / CARRY / OVERFLOW / LOWBAT | PB0, PB1, PB4, PB8, PB9 | 15, 16, 28, 32, 1 |
| USART2 TX / RX (AF1) | PA2 / PA3 | 9 / 10 |
| I2C1 SCL / SDA (AF6) | PB6 / PB7 | 30 / 31 |
| IRQ to main | PC6 | 20 |
| RGB TIM2_CH1 (AF2) / enable | PA15 / PB5 | 26 / 29 |
| SWDIO / SWCLK+BOOT0 / reset | PA13 / PA14 / PF2 | 24 / 25 / 6 |

The project-local `calcumaker:STM32G031K8U6` corrects the shared KiCad family
symbol's NC/PA9 and NC/PA10 pins: this package has dedicated PA9/pad19 and
PA10/pad21. Do not remap them onto PA11/PA12. PC14/15 are column inputs, avoiding
their output-current limitations. Column EXTI indices are all distinct.

Rows are active-low open-drain (unselected rows high impedance); column inputs
use pull-ups. Current flows **column → diode anode → cathode → switch → row**.
All rows can be held low for column EXTI wake. Annunciators are active-high through
470 Ω resistors. KB_BOOT0 reaches shared PA14/SWCLK through 1 kΩ R11, with a
10 kΩ local pull-down. Main firmware must tri-state KB_BOOT0 during SWD; hardware
BOOT0 requires the G0's `nBOOT_SEL=0` option setting.

## Power corrections and bring-up requirements

- U575RGT6 uses the LDO supply arrangement. VCAP/pad30 has C22+C23 (2×2.2 µF,
  ≥10 V, combined ESR <20 mΩ at 3 MHz), isolated from 3V3. Check effective
  capacitance and ESR for the ordered parts. VBAT is on regulated 3V3, not the
  raw cell. Main R13/R14 provide the shared I2C pull-ups.
- BQ25601 VAC/pad1 and VBUS/pad24 both use protected VBUS. PSEL has a 100 kΩ
  pull-up to REGN, staying below its 7 V absolute maximum even at 12 V USB-PD.
  CE has a 100 kΩ pull-up, so **charging stays disabled until firmware configures
  the selected cell and enables it**. INT and PG have 10 kΩ pull-ups.
- J8 accepts the pack's **10 kΩ 103AT-2 NTC** to ground, in parallel with R3
  (30.1 kΩ), with R2 (5.23 kΩ) to REGN. Without the sensor, TS inhibits charge;
  this is not a fixed-temperature bypass. J9 momentarily grounds QON to exit
  ship mode, using the charger's internal pull-up.
- Program the charger's **14 V OVP setting before requesting a 12 V PD contract**,
  set safe cell charge current and input-current limit, and service or disable
  the watchdog deliberately. Follow TCPP's VCC → UCPD Rd → DB release sequence.
- USBLC6 pin5 is tied to 3V3 for the USB data clamp. It must never see the 12 V
  VBUS rail. The TCPP/FET circuit handles VBUS and CC protection.
- TPS63900 SEL is low; CFG3=16.2 kΩ selects 3.3 V. CFG1=36.5 kΩ and CFG2=GND
  configure the alternate 3.3 V setting and unlimited input-current mode.
  Select L1 with ≥2 A saturation rating, and check capacitor bias derating.
- BAT_SENSE uses a 1 MΩ / 1 MΩ divider and 100 nF reservoir/filter. Allow adequate
  ADC settling time; do not treat this as a low-impedance ADC source.

## Still required before fabrication

This completes schematic connectivity, not board layout or hardware qualification.
The existing VSYS-fed SK6812MINI-E chain remains subject to its minimum supply
voltage and the 74LVC1G125's guaranteed input threshold over the full cell/charger
range. Resolve that power/logic-level choice with measurements or a revised rail
and buffer before fabrication. Hold LED_RAW low before shutting VLED off.

Also select the actual cell/NTC and charge limits; verify inductor current ratings,
capacitor effective values, connector current limits/FFC contact orientation,
stack height, reverse-mount RGB pin-to-footprint mapping, and placement of each
LED's bypass. Confirm clock load caps against the purchased crystal. Route and
review the charger/buck/USB loops and thermal pads. These boards have no finished
PCB layout in this change. Display/matrix board designs and firmware were not
changed; firmware must adopt the pin map and sequencing above.

## Primary references used

- [ST STM32U575 datasheet, DS13737](https://www.st.com/resource/en/datasheet/stm32u575rg.pdf): LQFP64 pinout and LDO/VCAP supply scheme.
- [ST STM32G031 datasheet, DS12992](https://www.st.com/resource/en/datasheet/stm32g031k8.pdf): UFQFPN32 pinout, alternate functions and PC14/PC15 constraints.
- [TI BQ25601 datasheet](https://www.ti.com/lit/ds/symlink/bq25601.pdf): PSEL/VAC/TS, charger controls, QON, OVP and watchdog.
- [TI TPS63900 datasheet](https://www.ti.com/lit/ds/symlink/tps63900.pdf): configuration resistor tables and power-stage requirements.
- [ST TCPP01-M12 datasheet](https://www.st.com/resource/en/datasheet/tcpp01-m12.pdf): protected-port pinout and GPIO power/DB sequencing.
- [ST USBLC6-2 datasheet](https://www.st.com/resource/en/datasheet/usblc6-2.pdf): data-line protection and VBUS clamp limits.
- [TI SN74LVC1G125 datasheet](https://www.ti.com/lit/ds/symlink/sn74lvc1g125.pdf): voltage-dependent input thresholds.

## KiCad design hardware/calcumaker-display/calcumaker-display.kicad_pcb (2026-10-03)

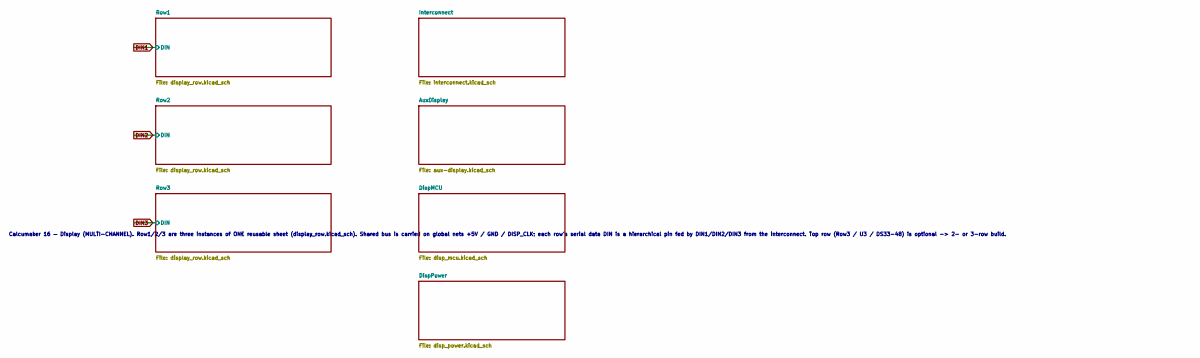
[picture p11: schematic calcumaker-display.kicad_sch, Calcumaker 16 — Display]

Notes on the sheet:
Calcumaker 16 — Display (MULTI-CHANNEL). Row1/2/3 are three instances of ONE reusable sheet (display_row.kicad_sch). Shared bus is carried on global nets +5V / GND / DISP_CLK; each row's serial data DIN is a hierarchical pin fed by DIN1/DIN2/DIN3 from the interconnect. Top row (Row3 / U3 / DS33-48)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

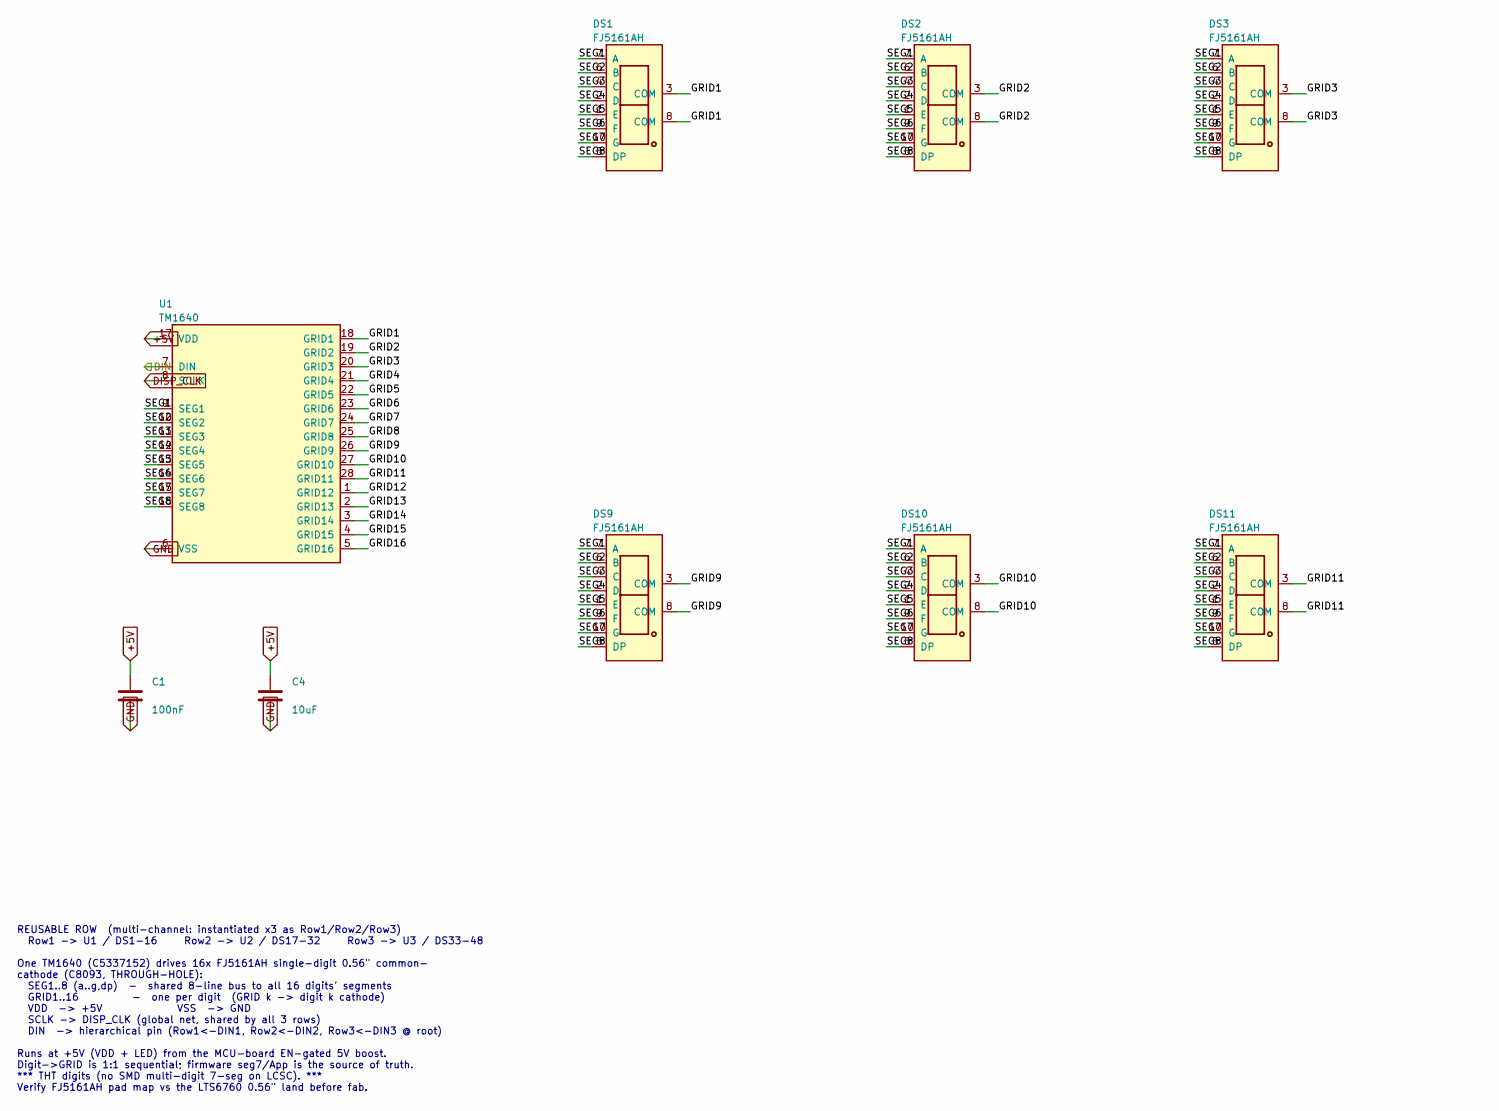
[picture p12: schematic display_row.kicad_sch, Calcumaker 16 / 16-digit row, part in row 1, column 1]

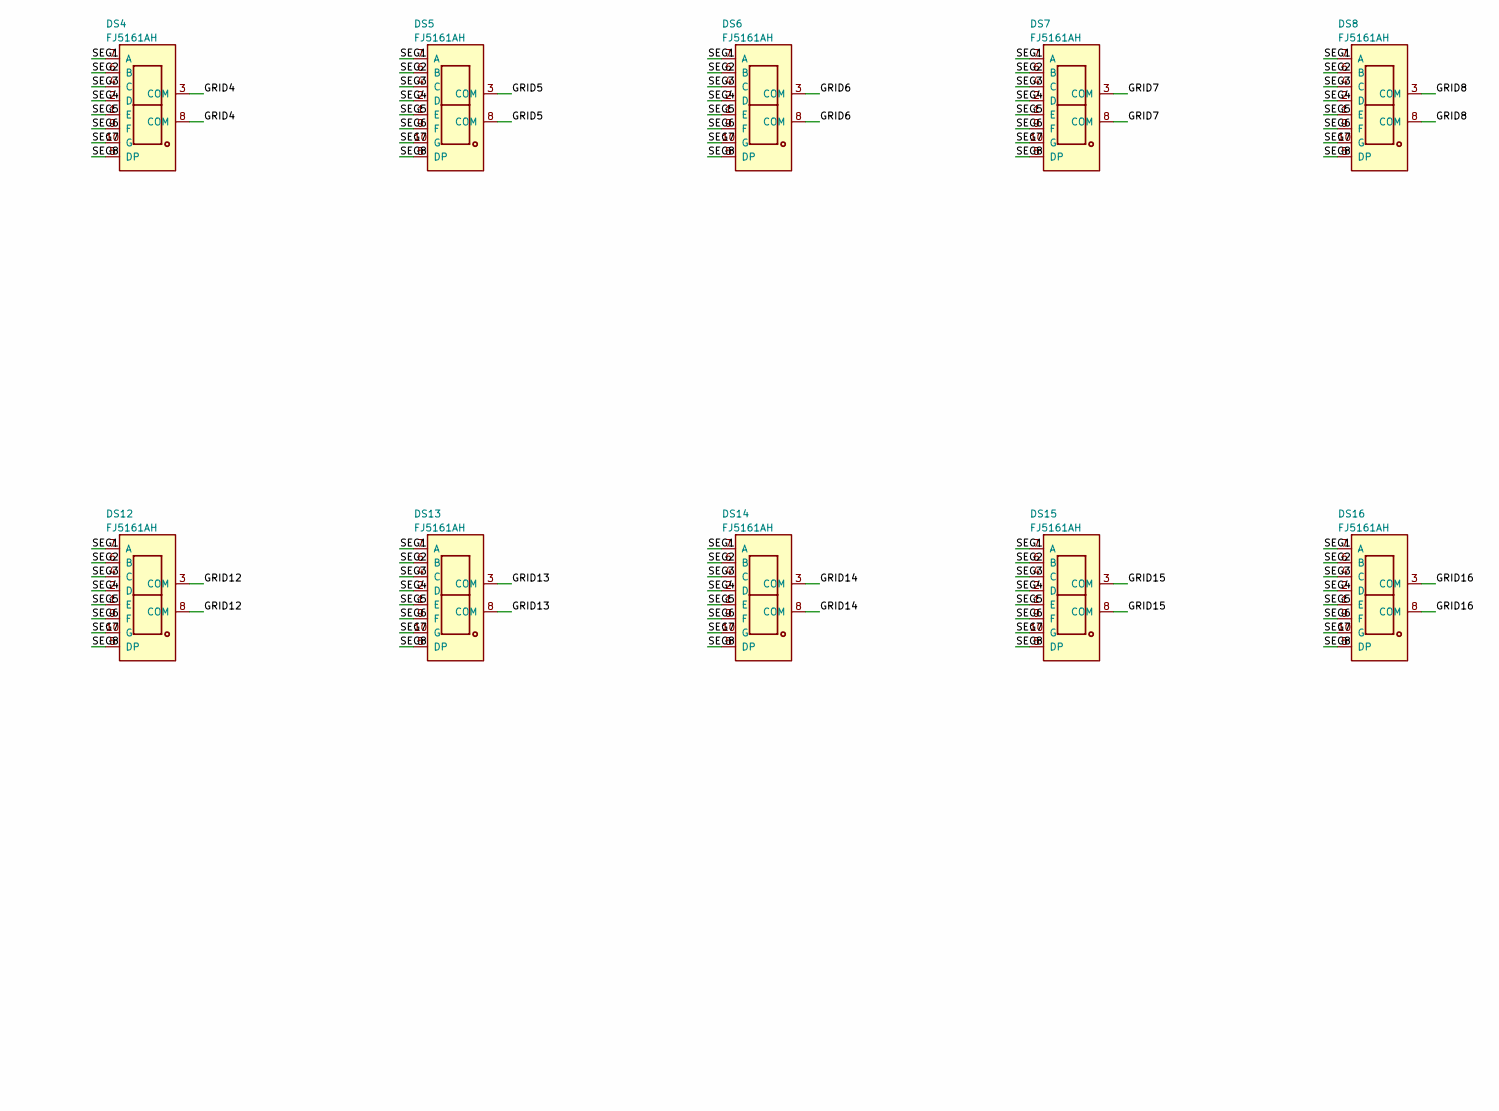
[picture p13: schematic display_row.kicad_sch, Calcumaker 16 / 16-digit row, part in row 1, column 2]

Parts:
C1: 100nF; C_0402_1005Metric; LCSC C1525
C4: 10uF; C_0603_1608Metric; LCSC C15850
DS1, DS2, DS3, DS4, DS5, DS6, DS7, DS8, DS9, DS10, DS11, DS12, DS13, DS14, DS15, DS16: FJ5161AH; 7SegmentLED_LTS6760_LTS6780; MPN FJ5161AH; LCSC C8093
U1: TM1640; SOIC-28W_7.5x18.7mm_P1.27mm; MPN TM1640; LCSC C5337152

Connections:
+5V: C1.1, C4.1, U1.17 (VDD); also elsewhere on the board
/Row1/GRID1: DS1.3 (COM), DS1.8 (COM), U1.18 (GRID1)
/Row1/GRID2: DS2.3 (COM), DS2.8 (COM), U1.19 (GRID2)
/Row1/GRID3: DS3.3 (COM), DS3.8 (COM), U1.20 (GRID3)
/Row1/GRID4: DS4.3 (COM), DS4.8 (COM), U1.21 (GRID4)
/Row1/GRID5: DS5.3 (COM), DS5.8 (COM), U1.22 (GRID5)
/Row1/GRID6: DS6.3 (COM), DS6.8 (COM), U1.23 (GRID6)
/Row1/GRID7: DS7.3 (COM), DS7.8 (COM), U1.24 (GRID7)
/Row1/GRID8: DS8.3 (COM), DS8.8 (COM), U1.25 (GRID8)
/Row1/GRID9: DS9.3 (COM), DS9.8 (COM), U1.26 (GRID9)
/Row1/GRID10: DS10.3 (COM), DS10.8 (COM), U1.27 (GRID10)
/Row1/GRID11: DS11.3 (COM), DS11.8 (COM), U1.28 (GRID11)
/Row1/GRID12: DS12.3 (COM), DS12.8 (COM), U1.1 (GRID12)
/Row1/GRID13: DS13.3 (COM), DS13.8 (COM), U1.2 (GRID13)
/Row1/GRID14: DS14.3 (COM), DS14.8 (COM), U1.3 (GRID14)
/Row1/GRID15: DS15.3 (COM), DS15.8 (COM), U1.4 (GRID15)
/Row1/GRID16: DS16.3 (COM), DS16.8 (COM), U1.5 (GRID16)
/Row1/SEG1: DS1.7 (A), DS2.7 (A), DS3.7 (A), DS4.7 (A), DS5.7 (A), DS6.7 (A), DS7.7 (A), DS8.7 (A), DS9.7 (A), DS10.7 (A), DS11.7 (A), DS12.7 (A), DS13.7 (A), DS14.7 (A), DS15.7 (A), DS16.7 (A), U1.9 (SEG1)
/Row1/SEG2: DS1.6 (B), DS2.6 (B), DS3.6 (B), DS4.6 (B), DS5.6 (B), DS6.6 (B), DS7.6 (B), DS8.6 (B), DS9.6 (B), DS10.6 (B), DS11.6 (B), DS12.6 (B), DS13.6 (B), DS14.6 (B), DS15.6 (B), DS16.6 (B), U1.10 (SEG2)
/Row1/SEG3: DS1.4 (C), DS2.4 (C), DS3.4 (C), DS4.4 (C), DS5.4 (C), DS6.4 (C), DS7.4 (C), DS8.4 (C), DS9.4 (C), DS10.4 (C), DS11.4 (C), DS12.4 (C), DS13.4 (C), DS14.4 (C), DS15.4 (C), DS16.4 (C), U1.11 (SEG3)
/Row1/SEG4: DS1.2 (D), DS2.2 (D), DS3.2 (D), DS4.2 (D), DS5.2 (D), DS6.2 (D), DS7.2 (D), DS8.2 (D), DS9.2 (D), DS10.2 (D), DS11.2 (D), DS12.2 (D), DS13.2 (D), DS14.2 (D), DS15.2 (D), DS16.2 (D), U1.12 (SEG4)
/Row1/SEG5: DS1.1 (E), DS2.1 (E), DS3.1 (E), DS4.1 (E), DS5.1 (E), DS6.1 (E), DS7.1 (E), DS8.1 (E), DS9.1 (E), DS10.1 (E), DS11.1 (E), DS12.1 (E), DS13.1 (E), DS14.1 (E), DS15.1 (E), DS16.1 (E), U1.13 (SEG5)
/Row1/SEG6: DS1.9 (F), DS2.9 (F), DS3.9 (F), DS4.9 (F), DS5.9 (F), DS6.9 (F), DS7.9 (F), DS8.9 (F), DS9.9 (F), DS10.9 (F), DS11.9 (F), DS12.9 (F), DS13.9 (F), DS14.9 (F), DS15.9 (F), DS16.9 (F), U1.14 (SEG6)
/Row1/SEG7: DS1.10 (G), DS2.10 (G), DS3.10 (G), DS4.10 (G), DS5.10 (G), DS6.10 (G), DS7.10 (G), DS8.10 (G), DS9.10 (G), DS10.10 (G), DS11.10 (G), DS12.10 (G), DS13.10 (G), DS14.10 (G), DS15.10 (G), DS16.10 (G), U1.15 (SEG7)
/Row1/SEG8: DS1.5 (DP), DS2.5 (DP), DS3.5 (DP), DS4.5 (DP), DS5.5 (DP), DS6.5 (DP), DS7.5 (DP), DS8.5 (DP), DS9.5 (DP), DS10.5 (DP), DS11.5 (DP), DS12.5 (DP), DS13.5 (DP), DS14.5 (DP), DS15.5 (DP), DS16.5 (DP), U1.16 (SEG8)
DIN1: U1.7 (DIN); also elsewhere on the board
DISP_CLK: U1.8 (SCLK); also elsewhere on the board
GND: C1.2, C4.2, U1.6 (VSS); also elsewhere on the board

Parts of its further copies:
C2, C3: 100nF; C_0402_1005Metric; LCSC C1525
C5, C6: 10uF; C_0603_1608Metric; LCSC C15850
DS17, DS18, DS19, DS20, DS21, DS22, DS23, DS24, DS25, DS26, DS27, DS28, DS29, DS30, DS31, DS32, DS33, DS34, DS35, DS36, DS37, DS38, DS39, DS40, DS41, DS42, DS43, DS44, DS45, DS46, DS47, DS48: FJ5161AH; 7SegmentLED_LTS6760_LTS6780; MPN FJ5161AH; LCSC C8093
U2, U3: TM1640; SOIC-28W_7.5x18.7mm_P1.27mm; MPN TM1640; LCSC C5337152

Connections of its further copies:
+5V: C2.1, C3.1, C5.1, C6.1, U2.17 (VDD), U3.17 (VDD); also elsewhere on the board
/Row2/GRID1: DS17.3 (COM), DS17.8 (COM), U2.18 (GRID1)
/Row2/GRID2: DS18.3 (COM), DS18.8 (COM), U2.19 (GRID2)
/Row2/GRID3: DS19.3 (COM), DS19.8 (COM), U2.20 (GRID3)
/Row2/GRID4: DS20.3 (COM), DS20.8 (COM), U2.21 (GRID4)
/Row2/GRID5: DS21.3 (COM), DS21.8 (COM), U2.22 (GRID5)
/Row2/GRID6: DS22.3 (COM), DS22.8 (COM), U2.23 (GRID6)
/Row2/GRID7: DS23.3 (COM), DS23.8 (COM), U2.24 (GRID7)
/Row2/GRID8: DS24.3 (COM), DS24.8 (COM), U2.25 (GRID8)
/Row2/GRID9: DS25.3 (COM), DS25.8 (COM), U2.26 (GRID9)
/Row2/GRID10: DS26.3 (COM), DS26.8 (COM), U2.27 (GRID10)
/Row2/GRID11: DS27.3 (COM), DS27.8 (COM), U2.28 (GRID11)
/Row2/GRID12: DS28.3 (COM), DS28.8 (COM), U2.1 (GRID12)
/Row2/GRID13: DS29.3 (COM), DS29.8 (COM), U2.2 (GRID13)
/Row2/GRID14: DS30.3 (COM), DS30.8 (COM), U2.3 (GRID14)
/Row2/GRID15: DS31.3 (COM), DS31.8 (COM), U2.4 (GRID15)
/Row2/GRID16: DS32.3 (COM), DS32.8 (COM), U2.5 (GRID16)
/Row2/SEG1: DS17.7 (A), DS18.7 (A), DS19.7 (A), DS20.7 (A), DS21.7 (A), DS22.7 (A), DS23.7 (A), DS24.7 (A), DS25.7 (A), DS26.7 (A), DS27.7 (A), DS28.7 (A), DS29.7 (A), DS30.7 (A), DS31.7 (A), DS32.7 (A), U2.9 (SEG1)
/Row2/SEG2: DS17.6 (B), DS18.6 (B), DS19.6 (B), DS20.6 (B), DS21.6 (B), DS22.6 (B), DS23.6 (B), DS24.6 (B), DS25.6 (B), DS26.6 (B), DS27.6 (B), DS28.6 (B), DS29.6 (B), DS30.6 (B), DS31.6 (B), DS32.6 (B), U2.10 (SEG2)
/Row2/SEG3: DS17.4 (C), DS18.4 (C), DS19.4 (C), DS20.4 (C), DS21.4 (C), DS22.4 (C), DS23.4 (C), DS24.4 (C), DS25.4 (C), DS26.4 (C), DS27.4 (C), DS28.4 (C), DS29.4 (C), DS30.4 (C), DS31.4 (C), DS32.4 (C), U2.11 (SEG3)
/Row2/SEG4: DS17.2 (D), DS18.2 (D), DS19.2 (D), DS20.2 (D), DS21.2 (D), DS22.2 (D), DS23.2 (D), DS24.2 (D), DS25.2 (D), DS26.2 (D), DS27.2 (D), DS28.2 (D), DS29.2 (D), DS30.2 (D), DS31.2 (D), DS32.2 (D), U2.12 (SEG4)
/Row2/SEG5: DS17.1 (E), DS18.1 (E), DS19.1 (E), DS20.1 (E), DS21.1 (E), DS22.1 (E), DS23.1 (E), DS24.1 (E), DS25.1 (E), DS26.1 (E), DS27.1 (E), DS28.1 (E), DS29.1 (E), DS30.1 (E), DS31.1 (E), DS32.1 (E), U2.13 (SEG5)
/Row2/SEG6: DS17.9 (F), DS18.9 (F), DS19.9 (F), DS20.9 (F), DS21.9 (F), DS22.9 (F), DS23.9 (F), DS24.9 (F), DS25.9 (F), DS26.9 (F), DS27.9 (F), DS28.9 (F), DS29.9 (F), DS30.9 (F), DS31.9 (F), DS32.9 (F), U2.14 (SEG6)
/Row2/SEG7: DS17.10 (G), DS18.10 (G), DS19.10 (G), DS20.10 (G), DS21.10 (G), DS22.10 (G), DS23.10 (G), DS24.10 (G), DS25.10 (G), DS26.10 (G), DS27.10 (G), DS28.10 (G), DS29.10 (G), DS30.10 (G), DS31.10 (G), DS32.10 (G), U2.15 (SEG7)
/Row2/SEG8: DS17.5 (DP), DS18.5 (DP), DS19.5 (DP), DS20.5 (DP), DS21.5 (DP), DS22.5 (DP), DS23.5 (DP), DS24.5 (DP), DS25.5 (DP), DS26.5 (DP), DS27.5 (DP), DS28.5 (DP), DS29.5 (DP), DS30.5 (DP), DS31.5 (DP), DS32.5 (DP), U2.16 (SEG8)
/Row3/GRID1: DS33.3 (COM), DS33.8 (COM), U3.18 (GRID1)
/Row3/GRID2: DS34.3 (COM), DS34.8 (COM), U3.19 (GRID2)
/Row3/GRID3: DS35.3 (COM), DS35.8 (COM), U3.20 (GRID3)
/Row3/GRID4: DS36.3 (COM), DS36.8 (COM), U3.21 (GRID4)
/Row3/GRID5: DS37.3 (COM), DS37.8 (COM), U3.22 (GRID5)
/Row3/GRID6: DS38.3 (COM), DS38.8 (COM), U3.23 (GRID6)
/Row3/GRID7: DS39.3 (COM), DS39.8 (COM), U3.24 (GRID7)
/Row3/GRID8: DS40.3 (COM), DS40.8 (COM), U3.25 (GRID8)
/Row3/GRID9: DS41.3 (COM), DS41.8 (COM), U3.26 (GRID9)
/Row3/GRID10: DS42.3 (COM), DS42.8 (COM), U3.27 (GRID10)
/Row3/GRID11: DS43.3 (COM), DS43.8 (COM), U3.28 (GRID11)
/Row3/GRID12: DS44.3 (COM), DS44.8 (COM), U3.1 (GRID12)
/Row3/GRID13: DS45.3 (COM), DS45.8 (COM), U3.2 (GRID13)
/Row3/GRID14: DS46.3 (COM), DS46.8 (COM), U3.3 (GRID14)
/Row3/GRID15: DS47.3 (COM), DS47.8 (COM), U3.4 (GRID15)
/Row3/GRID16: DS48.3 (COM), DS48.8 (COM), U3.5 (GRID16)
/Row3/SEG1: DS33.7 (A), DS34.7 (A), DS35.7 (A), DS36.7 (A), DS37.7 (A), DS38.7 (A), DS39.7 (A), DS40.7 (A), DS41.7 (A), DS42.7 (A), DS43.7 (A), DS44.7 (A), DS45.7 (A), DS46.7 (A), DS47.7 (A), DS48.7 (A), U3.9 (SEG1)
/Row3/SEG2: DS33.6 (B), DS34.6 (B), DS35.6 (B), DS36.6 (B), DS37.6 (B), DS38.6 (B), DS39.6 (B), DS40.6 (B), DS41.6 (B), DS42.6 (B), DS43.6 (B), DS44.6 (B), DS45.6 (B), DS46.6 (B), DS47.6 (B), DS48.6 (B), U3.10 (SEG2)
/Row3/SEG3: DS33.4 (C), DS34.4 (C), DS35.4 (C), DS36.4 (C), DS37.4 (C), DS38.4 (C), DS39.4 (C), DS40.4 (C), DS41.4 (C), DS42.4 (C), DS43.4 (C), DS44.4 (C), DS45.4 (C), DS46.4 (C), DS47.4 (C), DS48.4 (C), U3.11 (SEG3)
/Row3/SEG4: DS33.2 (D), DS34.2 (D), DS35.2 (D), DS36.2 (D), DS37.2 (D), DS38.2 (D), DS39.2 (D), DS40.2 (D), DS41.2 (D), DS42.2 (D), DS43.2 (D), DS44.2 (D), DS45.2 (D), DS46.2 (D), DS47.2 (D), DS48.2 (D), U3.12 (SEG4)
/Row3/SEG5: DS33.1 (E), DS34.1 (E), DS35.1 (E), DS36.1 (E), DS37.1 (E), DS38.1 (E), DS39.1 (E), DS40.1 (E), DS41.1 (E), DS42.1 (E), DS43.1 (E), DS44.1 (E), DS45.1 (E), DS46.1 (E), DS47.1 (E), DS48.1 (E), U3.13 (SEG5)
/Row3/SEG6: DS33.9 (F), DS34.9 (F), DS35.9 (F), DS36.9 (F), DS37.9 (F), DS38.9 (F), DS39.9 (F), DS40.9 (F), DS41.9 (F), DS42.9 (F), DS43.9 (F), DS44.9 (F), DS45.9 (F), DS46.9 (F), DS47.9 (F), DS48.9 (F), U3.14 (SEG6)
/Row3/SEG7: DS33.10 (G), DS34.10 (G), DS35.10 (G), DS36.10 (G), DS37.10 (G), DS38.10 (G), DS39.10 (G), DS40.10 (G), DS41.10 (G), DS42.10 (G), DS43.10 (G), DS44.10 (G), DS45.10 (G), DS46.10 (G), DS47.10 (G), DS48.10 (G), U3.15 (SEG7)
/Row3/SEG8: DS33.5 (DP), DS34.5 (DP), DS35.5 (DP), DS36.5 (DP), DS37.5 (DP), DS38.5 (DP), DS39.5 (DP), DS40.5 (DP), DS41.5 (DP), DS42.5 (DP), DS43.5 (DP), DS44.5 (DP), DS45.5 (DP), DS46.5 (DP), DS47.5 (DP), DS48.5 (DP), U3.16 (SEG8)
DIN2: U2.7 (DIN); also elsewhere on the board
DIN3: U3.7 (DIN); also elsewhere on the board
DISP_CLK: U2.8 (SCLK), U3.8 (SCLK); also elsewhere on the board
GND: C2.2, C3.2, C5.2, C6.2, U2.6 (VSS), U3.6 (VSS); also elsewhere on the board

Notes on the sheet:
REUSABLE ROW (multi-channel: instantiated x3 as Row1/Row2/Row3) Row1 -> U1 / DS1-16 Row2 -> U2 / DS17-32 Row3 -> U3 / DS33-48 One TM1640 (C5337152) drives 16x FJ5161AH single-digit 0.56" common- cathode (C8093, THROUGH-HOLE): SEG1..8 (a..g,dp) - shared 8-line bus to all 16 digits' segments GRID1..1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

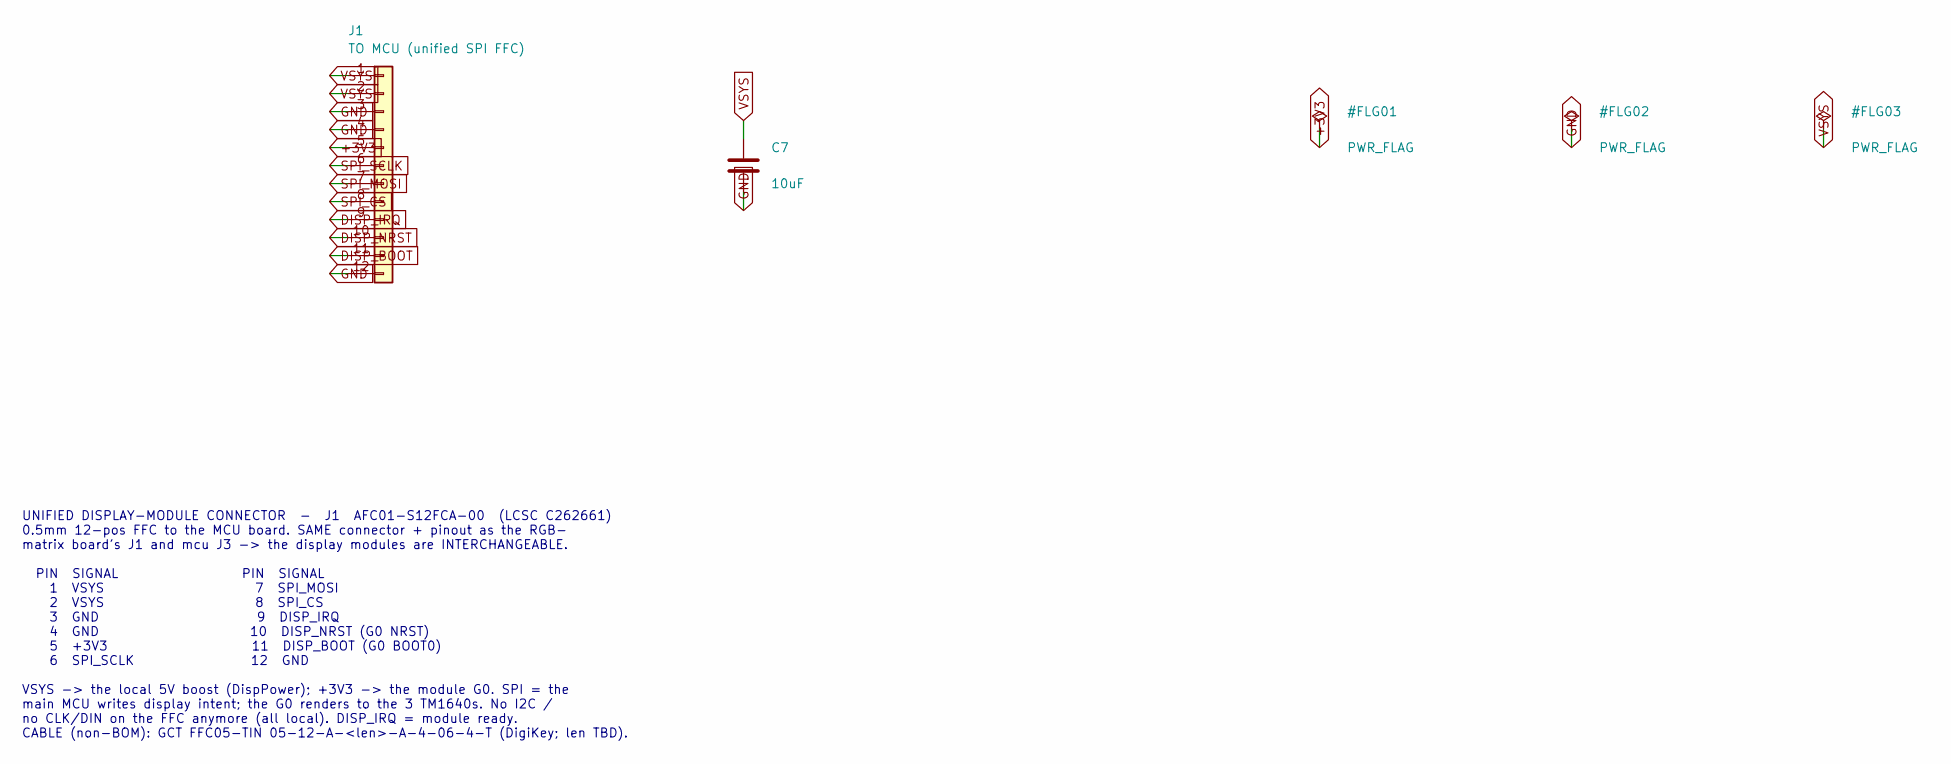
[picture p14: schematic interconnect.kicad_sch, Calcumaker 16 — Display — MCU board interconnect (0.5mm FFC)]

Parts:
C7: 10uF; C_0603_1608Metric; LCSC C15850
J1: TO MCU (unified SPI FFC); Hirose_FH12-12S-0.5SH_1x12-1MP_P0.50mm_Horizontal; MPN AFC01-S12FCA-00; LCSC C262661

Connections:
+3V3: J1.5; also elsewhere on the board
DISP_BOOT: J1.11; also elsewhere on the board
DISP_IRQ: J1.9; also elsewhere on the board
DISP_NRST: J1.10; also elsewhere on the board
GND: C7.2, J1.3, J1.4, J1.12; also elsewhere on the board
SPI_CS: J1.8; also elsewhere on the board
SPI_MOSI: J1.7; also elsewhere on the board
SPI_SCLK: J1.6; also elsewhere on the board
VSYS: C7.1, J1.1, J1.2; also elsewhere on the board

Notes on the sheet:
UNIFIED DISPLAY-MODULE CONNECTOR - J1 AFC01-S12FCA-00 (LCSC C262661) 0.5mm 12-pos FFC to the MCU board. SAME connector + pinout as the RGB- matrix board's J1 and mcu J3 -> the display modules are INTERCHANGEABLE. PIN SIGNAL PIN SIGNAL 1 VSYS 7 SPI_MOSI 2 VSYS 8 SPI_CS 3 GND 9 DISP_IRQ 4 GND 10 DISP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

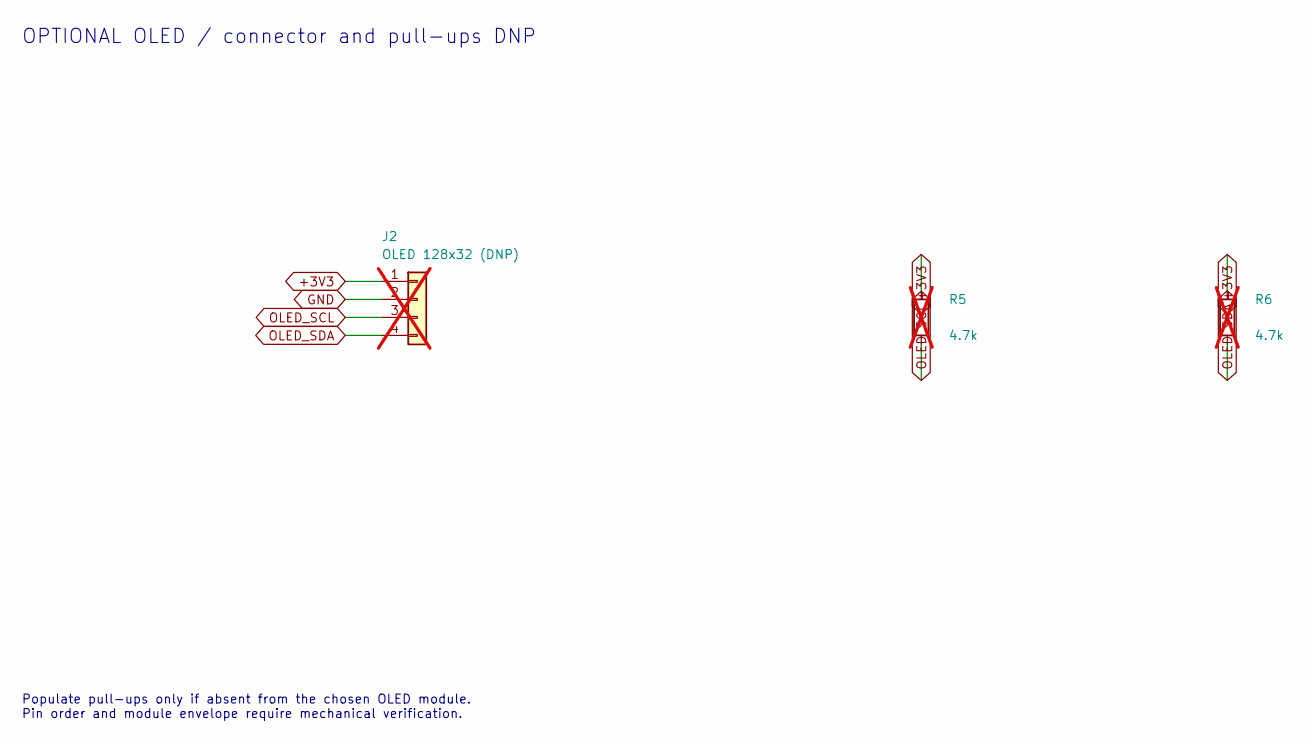
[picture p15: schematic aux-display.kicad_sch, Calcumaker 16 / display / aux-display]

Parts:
J2: OLED 128x32 (DNP); PinHeader_1x04_P2.54mm_Vertical; MPN PZ254V-11-04P; LCSC C2691448; not fitted
R5, R6: 4.7k; R_0402_1005Metric; not fitted

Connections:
+3V3: J2.1, R5.1, R6.1; also elsewhere on the board
GND: J2.2; also elsewhere on the board
OLED_SCL: J2.3, R5.2; also elsewhere on the board
OLED_SDA: J2.4, R6.2; also elsewhere on the board

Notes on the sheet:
Populate pull-ups only if absent from the chosen OLED module. Pin order and module envelope require mechanical verification.
OPTIONAL OLED / connector and pull-ups DNP

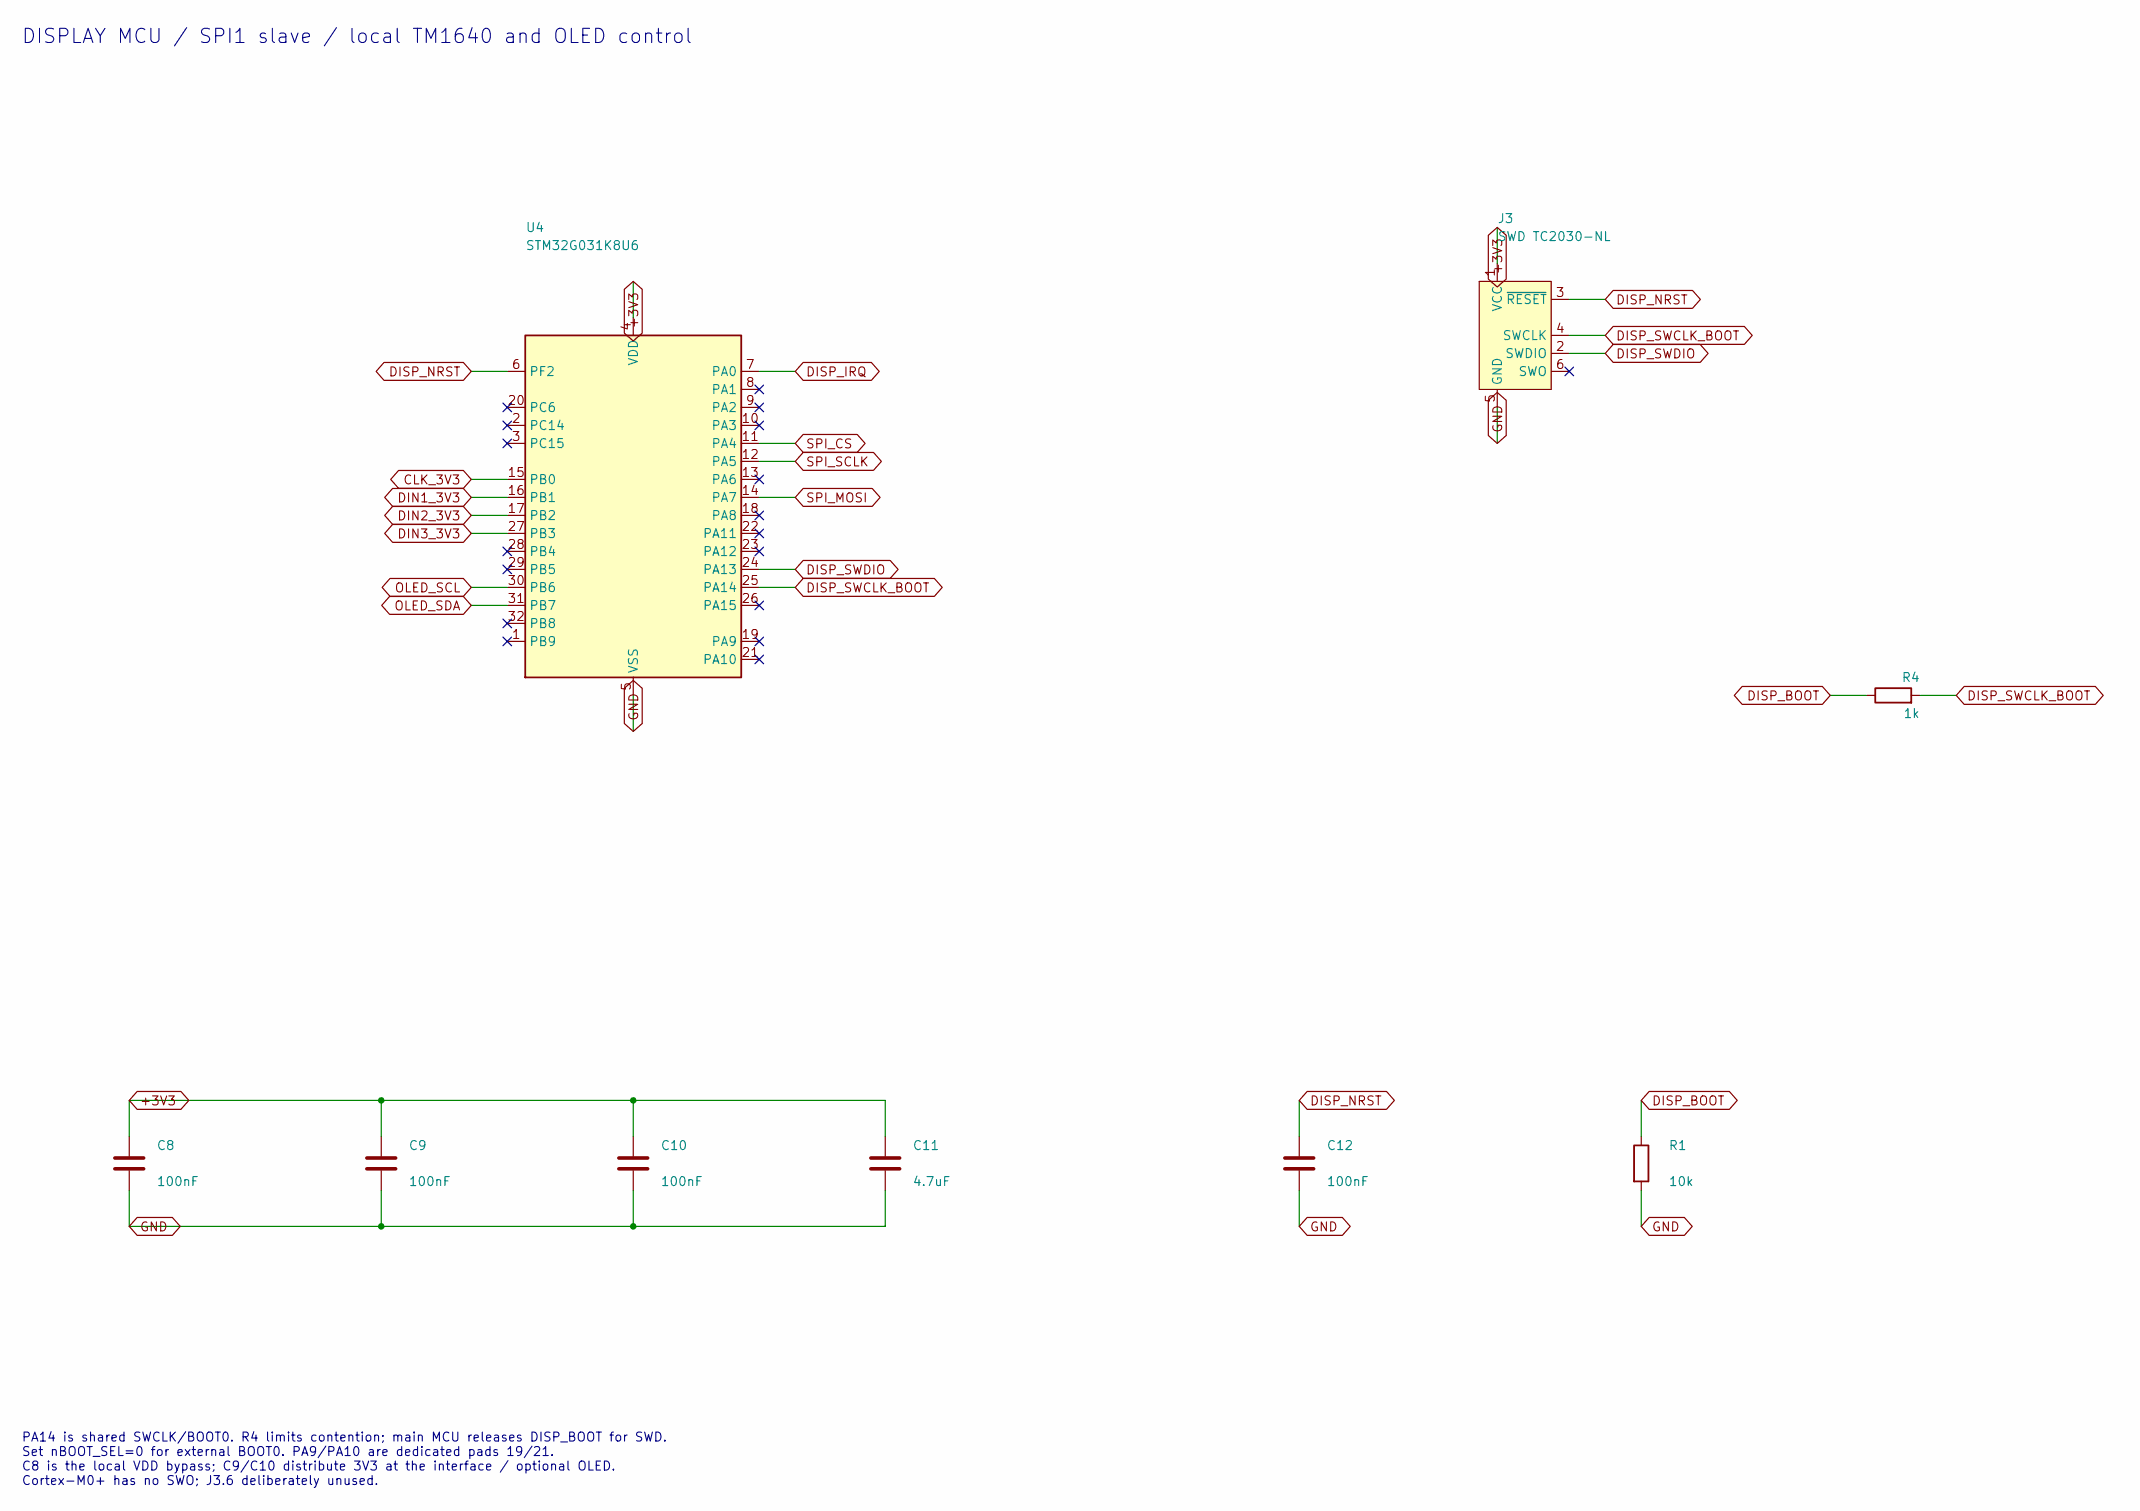
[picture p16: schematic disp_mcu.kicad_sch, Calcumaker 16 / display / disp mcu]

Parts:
C8, C9, C10, C12: 100nF; C_0402_1005Metric; LCSC C1525
C11: 4.7uF; C_0603_1608Metric; LCSC C23630
J3: SWD TC2030-NL; Tag-Connect_TC2030-IDC-NL_2x03_P1.27mm_Vertical
R1: 10k; R_0402_1005Metric; LCSC C25744
R4: 1k; R_0402_1005Metric
U4: STM32G031K8U6; UFQFPN-32-1EP_5x5mm_P0.5mm_EP3.5x3.5mm; MPN STM32G031K8U6; LCSC C432207

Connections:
+3V3: C8.1, C9.1, C10.1, C11.1, J3.1 (VCC), U4.4 (VDD); also elsewhere on the board
CLK_3V3: U4.15 (PB0); also elsewhere on the board
DIN1_3V3: U4.16 (PB1); also elsewhere on the board
DIN2_3V3: U4.17 (PB2); also elsewhere on the board
DIN3_3V3: U4.27 (PB3); also elsewhere on the board
DISP_BOOT: R1.1, R4.1; also elsewhere on the board
DISP_IRQ: U4.7 (PA0); also elsewhere on the board
DISP_NRST: C12.1, J3.3 (~RESET), U4.6 (PF2); also elsewhere on the board
DISP_SWCLK_BOOT: J3.4 (SWCLK), R4.2, U4.25 (PA14)
DISP_SWDIO: J3.2 (SWDIO), U4.24 (PA13)
GND: C8.2, C9.2, C10.2, C11.2, C12.2, J3.5 (GND), R1.2, U4.5 (VSS), U4.33 (VSS); also elsewhere on the board
OLED_SCL: U4.30 (PB6); also elsewhere on the board
OLED_SDA: U4.31 (PB7); also elsewhere on the board
SPI_CS: U4.11 (PA4); also elsewhere on the board
SPI_MOSI: U4.14 (PA7); also elsewhere on the board
SPI_SCLK: U4.12 (PA5); also elsewhere on the board

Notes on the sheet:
DISPLAY MCU / SPI1 slave / local TM1640 and OLED control
PA14 is shared SWCLK/BOOT0. R4 limits contention; main MCU releases DISP_BOOT for SWD. Set nBOOT_SEL=0 for external BOOT0. PA9/PA10 are dedicated pads 19/21. C8 is the local VDD bypass; C9/C10 distribute 3V3 at the interface / optional OLED. Cortex-M0+ has no SWO; J3.6 deliberately unused.

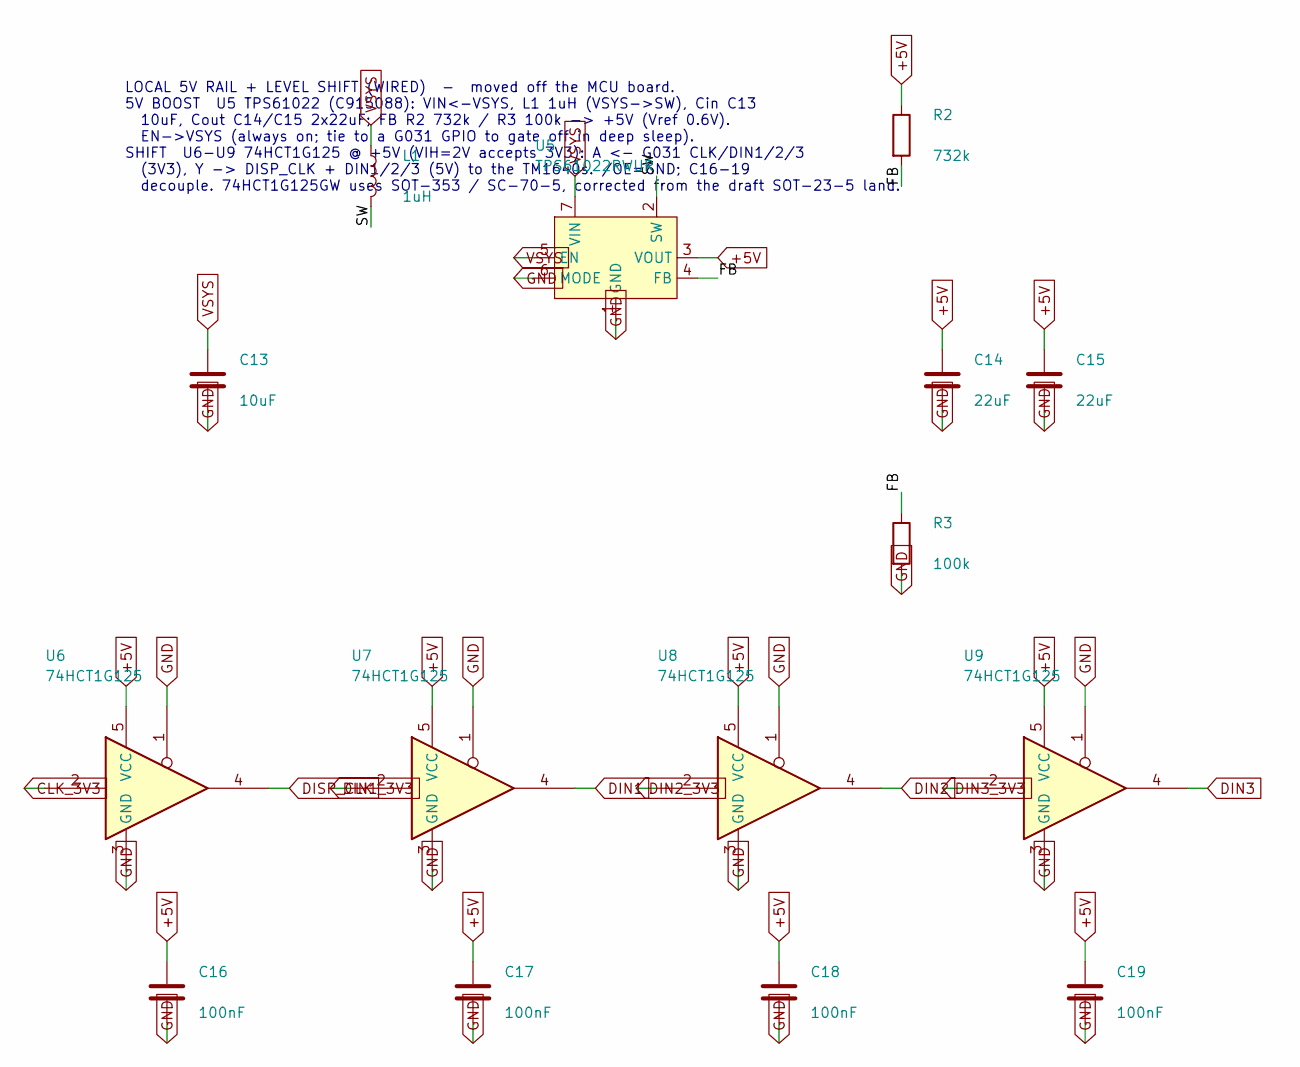
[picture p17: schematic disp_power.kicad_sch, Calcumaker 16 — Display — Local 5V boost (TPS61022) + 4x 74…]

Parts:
C13: 10uF; C_0603_1608Metric; LCSC C15850
C14, C15: 22uF; C_0603_1608Metric; LCSC C45783
C16, C17, C18, C19: 100nF; C_0402_1005Metric; LCSC C1525
L1: 1uH; L_0805_2012Metric; MPN FTC201610S1R0MBCA; LCSC C5832342
R2: 732k; R_0402_1005Metric
R3: 100k; R_0402_1005Metric; LCSC C25741
U5: TPS61022RWUR; Texas_RWU0007A_VQFN-7_2x2mm_P0.5mm; MPN TPS61022RWUR; LCSC C915088
U6, U7, U8, U9: 74HCT1G125; SOT-353_SC-70-5; MPN 74HCT1G125GW; LCSC C547448

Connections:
+5V: C14.1, C15.1, C16.1, C17.1, C18.1, C19.1, R2.1, U5.3 (VOUT), U6.5 (VCC), U7.5 (VCC), U8.5 (VCC), U9.5 (VCC); also elsewhere on the board
/DispPower/FB: R2.2, R3.1, U5.4 (FB)
/DispPower/SW: L1.2, U5.2 (SW)
CLK_3V3: U6.2; also elsewhere on the board
DIN1: U7.4; also elsewhere on the board
DIN1_3V3: U7.2; also elsewhere on the board
DIN2: U8.4; also elsewhere on the board
DIN2_3V3: U8.2; also elsewhere on the board
DIN3: U9.4; also elsewhere on the board
DIN3_3V3: U9.2; also elsewhere on the board
DISP_CLK: U6.4; also elsewhere on the board
GND: C13.2, C14.2, C15.2, C16.2, C17.2, C18.2, C19.2, R3.2, U5.1 (GND), U5.6 (MODE), U6.1, U6.3 (GND), U7.1, U7.3 (GND), U8.1, U8.3 (GND), U9.1, U9.3 (GND); also elsewhere on the board
VSYS: C13.1, L1.1, U5.5 (EN), U5.7 (VIN); also elsewhere on the board

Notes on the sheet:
LOCAL 5V RAIL + LEVEL SHIFT (WIRED) - moved off the MCU board. 5V BOOST U5 TPS61022 (C915088): VIN<-VSYS, L1 1uH (VSYS->SW), Cin C13 10uF, Cout C14/C15 2x22uF; FB R2 732k / R3 100k -> +5V (Vref 0.6V). EN->VSYS (always on; tie to a G031 GPIO to gate off in deep sleep). SHIFT U6-U9 74HCT1G125 @ +5V (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

Board: 2 copper layers, 86 parts (37 on the bottom side), 96 nets, no tracks yet.

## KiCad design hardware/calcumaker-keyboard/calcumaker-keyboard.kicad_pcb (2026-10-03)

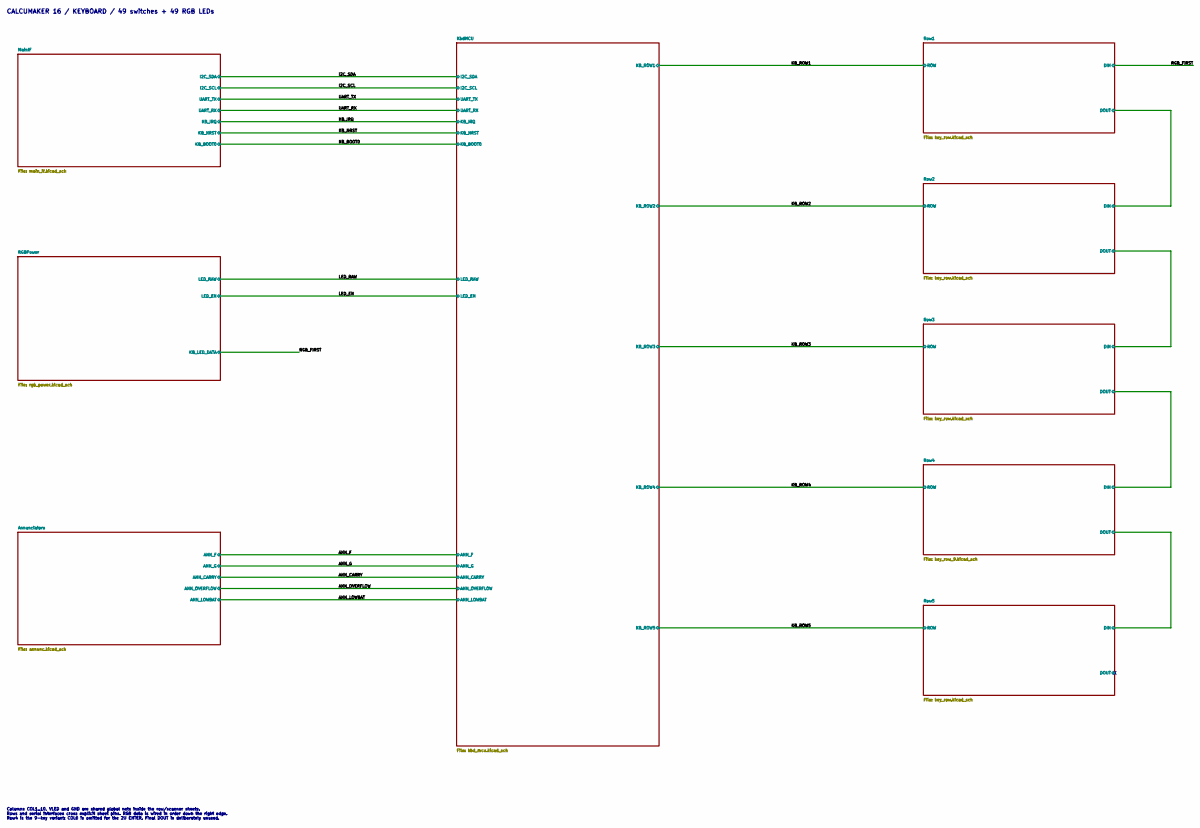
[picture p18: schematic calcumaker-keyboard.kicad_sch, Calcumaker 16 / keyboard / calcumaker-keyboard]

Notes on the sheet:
Columns COL1..10, VLED and GND are shared global nets inside the row/scanner sheets. Rows and serial interfaces cross explicit sheet pins. RGB data is wired in order down the right edge. Row4 is the 9-key variant: COL6 is omitted for the 2U ENTER. Final DOUT is deliberately unused.
CALCUMAKER 16 / KEYBOARD / 49 switches + 49 RGB LEDs

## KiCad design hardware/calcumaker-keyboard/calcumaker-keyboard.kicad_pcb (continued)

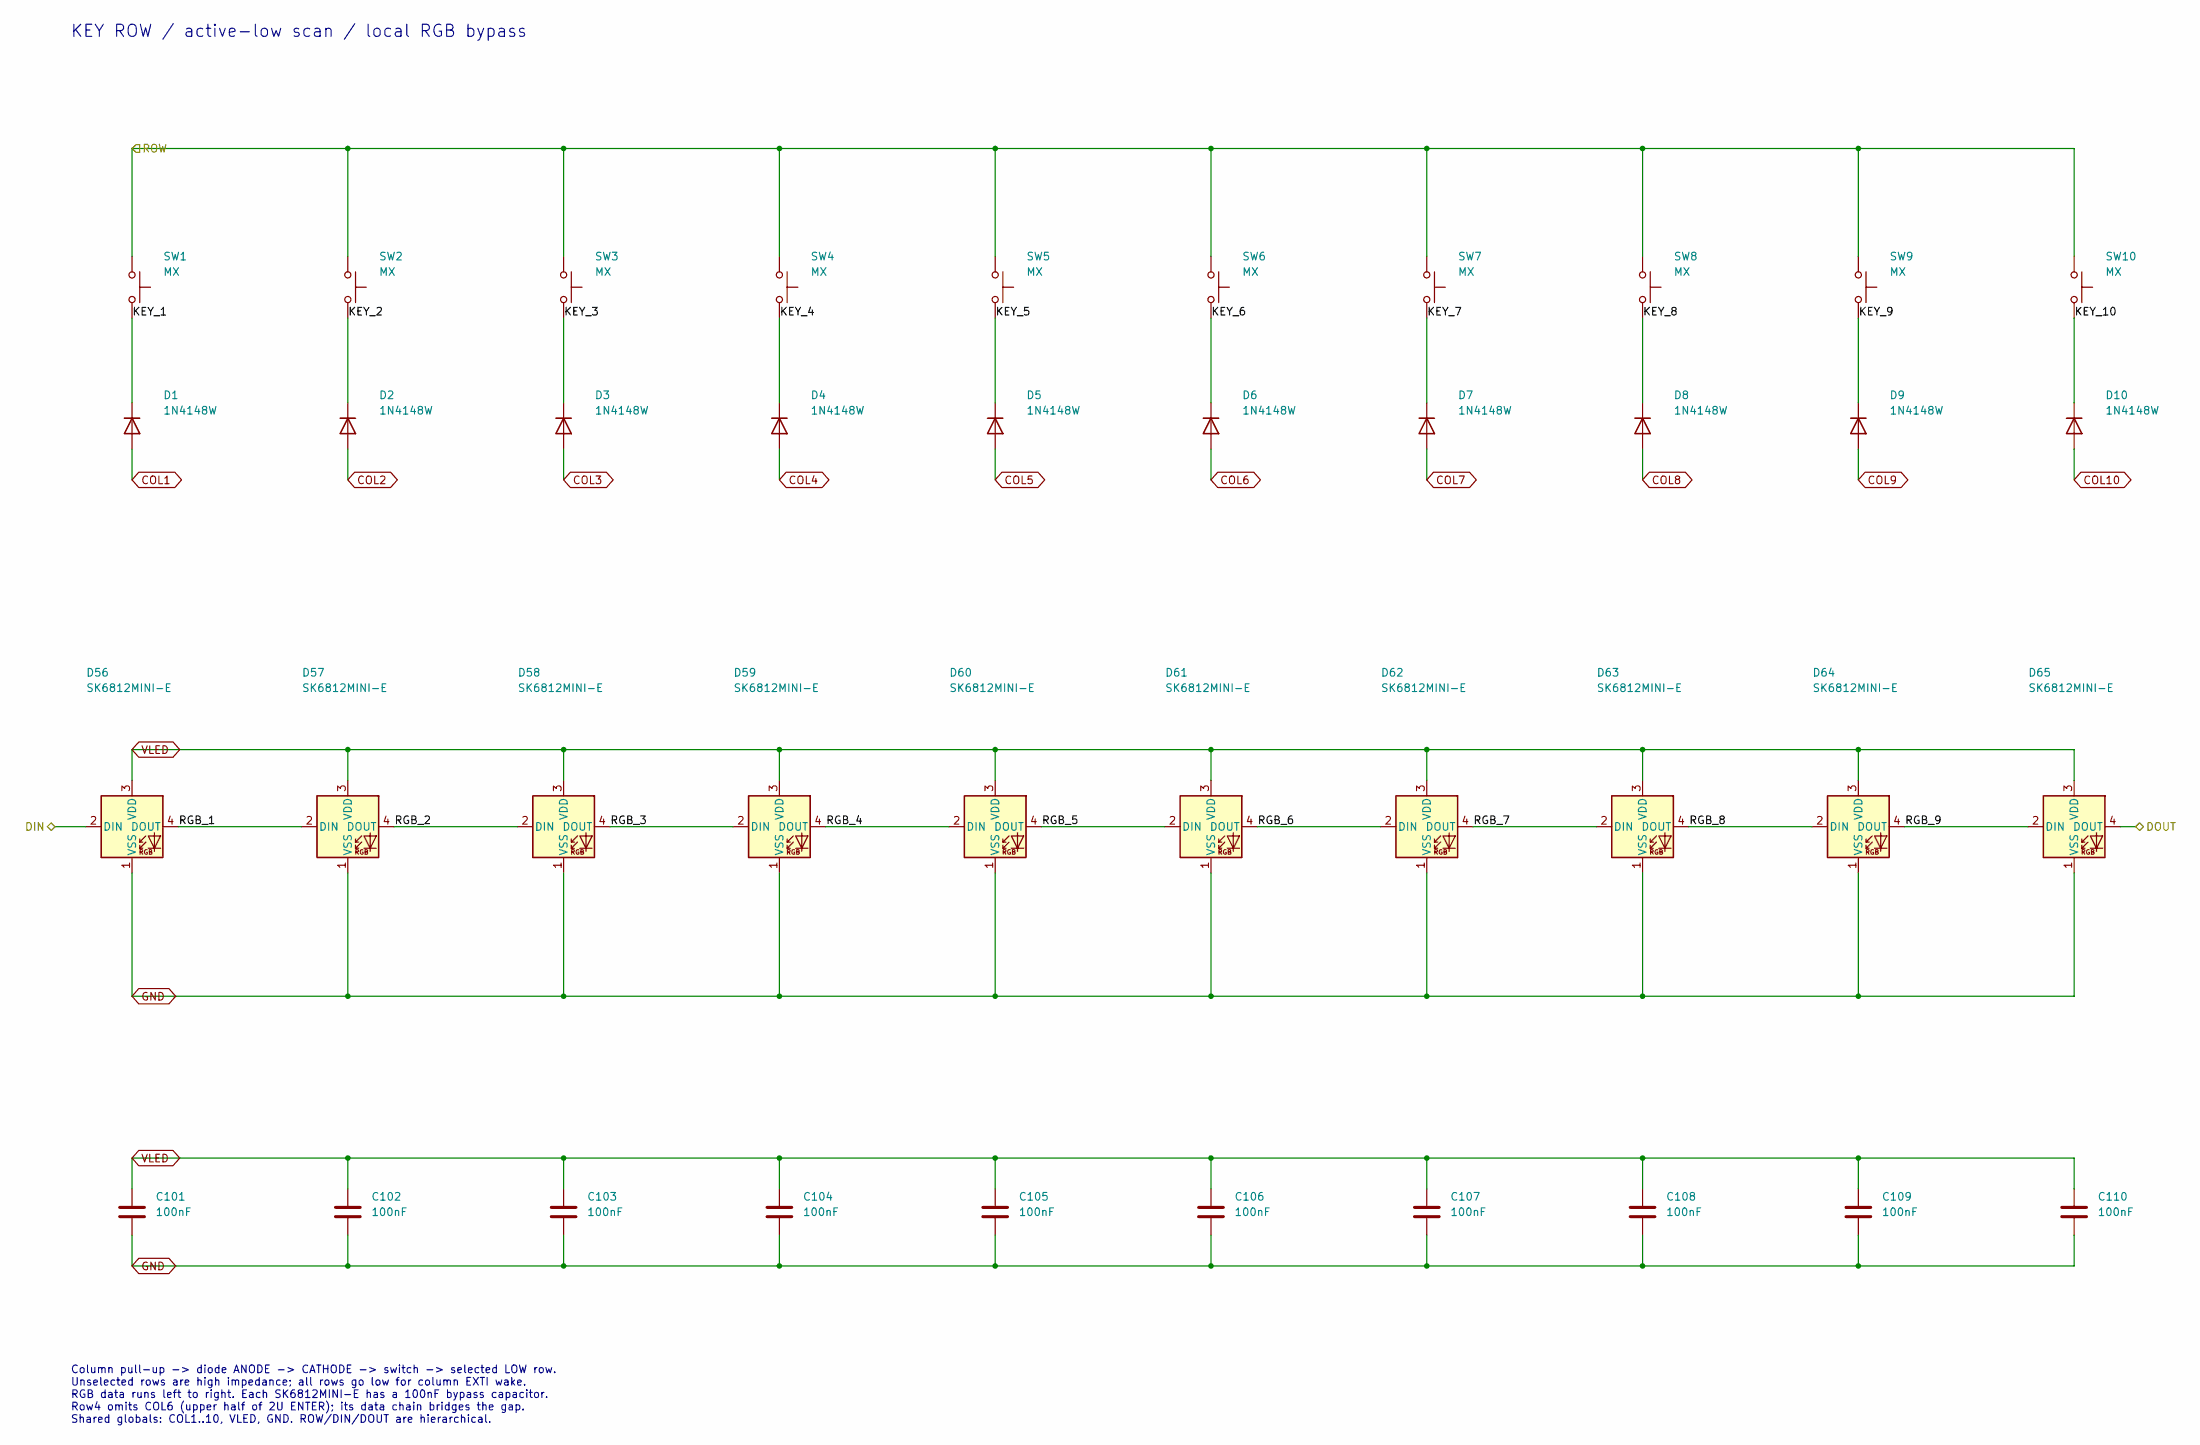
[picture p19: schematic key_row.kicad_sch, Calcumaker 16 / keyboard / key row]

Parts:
C101, C102, C103, C104, C105, C106, C107, C108, C109, C110: 100nF; C_0402_1005Metric
D1, D2, D3, D4, D5, D6, D7, D8, D9, D10: 1N4148W; D_SOD-123; MPN 1N4148W; LCSC C81598
D56, D57, D58, D59, D60, D61, D62, D63, D64, D65: SK6812MINI-E; LED_SK6812MINI-E_3.2x2.8mm_P1.5mm_ReverseMount; MPN SK6812MINI-E; LCSC C5149201
SW1, SW2, SW3, SW4, SW5, SW6, SW7, SW8, SW9, SW10: MX; SW_MX_HS_CPG151101S11_1u

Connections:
/KB_ROW1: SW1.1, SW2.1, SW3.1, SW4.1, SW5.1, SW6.1, SW7.1, SW8.1, SW9.1, SW10.1; also elsewhere on the board
/RGB_FIRST: D56.2 (DIN); also elsewhere on the board
/Row1/DOUT: D65.4 (DOUT); also elsewhere on the board
/Row1/KEY_1: D1.1 (K), SW1.2
/Row1/KEY_2: D2.1 (K), SW2.2
/Row1/KEY_3: D3.1 (K), SW3.2
/Row1/KEY_4: D4.1 (K), SW4.2
/Row1/KEY_5: D5.1 (K), SW5.2
/Row1/KEY_6: D6.1 (K), SW6.2
/Row1/KEY_7: D7.1 (K), SW7.2
/Row1/KEY_8: D8.1 (K), SW8.2
/Row1/KEY_9: D9.1 (K), SW9.2
/Row1/KEY_10: D10.1 (K), SW10.2
/Row1/RGB_1: D56.4 (DOUT), D57.2 (DIN)
/Row1/RGB_2: D57.4 (DOUT), D58.2 (DIN)
/Row1/RGB_3: D58.4 (DOUT), D59.2 (DIN)
/Row1/RGB_4: D59.4 (DOUT), D60.2 (DIN)
/Row1/RGB_5: D60.4 (DOUT), D61.2 (DIN)
/Row1/RGB_6: D61.4 (DOUT), D62.2 (DIN)
/Row1/RGB_7: D62.4 (DOUT), D63.2 (DIN)
/Row1/RGB_8: D63.4 (DOUT), D64.2 (DIN)
/Row1/RGB_9: D64.4 (DOUT), D65.2 (DIN)
COL1: D1.2 (A); also elsewhere on the board
COL2: D2.2 (A); also elsewhere on the board
COL3: D3.2 (A); also elsewhere on the board
COL4: D4.2 (A); also elsewhere on the board
COL5: D5.2 (A); also elsewhere on the board
COL6: D6.2 (A); also elsewhere on the board
COL7: D7.2 (A); also elsewhere on the board
COL8: D8.2 (A); also elsewhere on the board
COL9: D9.2 (A); also elsewhere on the board
COL10: D10.2 (A); also elsewhere on the board
GND: C101.2, C102.2, C103.2, C104.2, C105.2, C106.2, C107.2, C108.2, C109.2, C110.2, D56.1 (VSS), D57.1 (VSS), D58.1 (VSS), D59.1 (VSS), D60.1 (VSS), D61.1 (VSS), D62.1 (VSS), D63.1 (VSS), D64.1 (VSS), D65.1 (VSS); also elsewhere on the board
VLED: C101.1, C102.1, C103.1, C104.1, C105.1, C106.1, C107.1, C108.1, C109.1, C110.1, D56.3 (VDD), D57.3 (VDD), D58.3 (VDD), D59.3 (VDD), D60.3 (VDD), D61.3 (VDD), D62.3 (VDD), D63.3 (VDD), D64.3 (VDD), D65.3 (VDD); also elsewhere on the board

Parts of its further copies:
C111, C112, C113, C114, C115, C116, C117, C118, C119, C120, C121, C122, C123, C124, C125, C126, C127, C128, C129, C130, C141, C142, C143, C144, C145, C146, C147, C148, C149, C150: 100nF; C_0402_1005Metric
D11, D12, D13, D14, D15, D16, D17, D18, D19, D20, D21, D22, D23, D24, D25, D26, D27, D28, D29, D30, D41, D42, D43, D44, D45, D46, D47, D48, D49, D50: 1N4148W; D_SOD-123; MPN 1N4148W; LCSC C81598
D66, D67, D68, D69, D70, D71, D72, D73, D74, D75, D76, D77, D78, D79, D80, D81, D82, D83, D84, D85, D96, D97, D98, D99, D100, D101, D102, D103, D104, D105: SK6812MINI-E; LED_SK6812MINI-E_3.2x2.8mm_P1.5mm_ReverseMount; MPN SK6812MINI-E; LCSC C5149201
SW11, SW12, SW13, SW14, SW15, SW16, SW17, SW18, SW19, SW20, SW21, SW22, SW23, SW24, SW25, SW26, SW27, SW28, SW29, SW30, SW41, SW42, SW43, SW44, SW45, SW46, SW47, SW48, SW49, SW50: MX; SW_MX_HS_CPG151101S11_1u

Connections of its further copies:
/KB_ROW2: SW11.1, SW12.1, SW13.1, SW14.1, SW15.1, SW16.1, SW17.1, SW18.1, SW19.1, SW20.1; also elsewhere on the board
/KB_ROW3: SW21.1, SW22.1, SW23.1, SW24.1, SW25.1, SW26.1, SW27.1, SW28.1, SW29.1, SW30.1; also elsewhere on the board
/KB_ROW5: SW41.1, SW42.1, SW43.1, SW44.1, SW45.1, SW46.1, SW47.1, SW48.1, SW49.1, SW50.1; also elsewhere on the board
/Row1/DOUT: D66.2 (DIN); also elsewhere on the board
/Row2/DOUT: D75.4 (DOUT), D76.2 (DIN)
/Row2/KEY_1: D11.1 (K), SW11.2
/Row2/KEY_2: D12.1 (K), SW12.2
/Row2/KEY_3: D13.1 (K), SW13.2
/Row2/KEY_4: D14.1 (K), SW14.2
/Row2/KEY_5: D15.1 (K), SW15.2
/Row2/KEY_6: D16.1 (K), SW16.2
/Row2/KEY_7: D17.1 (K), SW17.2
/Row2/KEY_8: D18.1 (K), SW18.2
/Row2/KEY_9: D19.1 (K), SW19.2
/Row2/KEY_10: D20.1 (K), SW20.2
/Row2/RGB_1: D66.4 (DOUT), D67.2 (DIN)
/Row2/RGB_2: D67.4 (DOUT), D68.2 (DIN)
/Row2/RGB_3: D68.4 (DOUT), D69.2 (DIN)
/Row2/RGB_4: D69.4 (DOUT), D70.2 (DIN)
/Row2/RGB_5: D70.4 (DOUT), D71.2 (DIN)
/Row2/RGB_6: D71.4 (DOUT), D72.2 (DIN)
/Row2/RGB_7: D72.4 (DOUT), D73.2 (DIN)
/Row2/RGB_8: D73.4 (DOUT), D74.2 (DIN)
/Row2/RGB_9: D74.4 (DOUT), D75.2 (DIN)
/Row3/DOUT: D85.4 (DOUT); also elsewhere on the board
/Row3/KEY_1: D21.1 (K), SW21.2
/Row3/KEY_2: D22.1 (K), SW22.2
/Row3/KEY_3: D23.1 (K), SW23.2
/Row3/KEY_4: D24.1 (K), SW24.2
/Row3/KEY_5: D25.1 (K), SW25.2
/Row3/KEY_6: D26.1 (K), SW26.2
/Row3/KEY_7: D27.1 (K), SW27.2
/Row3/KEY_8: D28.1 (K), SW28.2
/Row3/KEY_9: D29.1 (K), SW29.2
/Row3/KEY_10: D30.1 (K), SW30.2
/Row3/RGB_1: D76.4 (DOUT), D77.2 (DIN)
/Row3/RGB_2: D77.4 (DOUT), D78.2 (DIN)
/Row3/RGB_3: D78.4 (DOUT), D79.2 (DIN)
/Row3/RGB_4: D79.4 (DOUT), D80.2 (DIN)
/Row3/RGB_5: D80.4 (DOUT), D81.2 (DIN)
/Row3/RGB_6: D81.4 (DOUT), D82.2 (DIN)
/Row3/RGB_7: D82.4 (DOUT), D83.2 (DIN)
/Row3/RGB_8: D83.4 (DOUT), D84.2 (DIN)
/Row3/RGB_9: D84.4 (DOUT), D85.2 (DIN)
/Row4/DOUT: D96.2 (DIN); also elsewhere on the board
/Row5/DOUT: D105.4 (DOUT)
/Row5/KEY_1: D41.1 (K), SW41.2
/Row5/KEY_2: D42.1 (K), SW42.2
/Row5/KEY_3: D43.1 (K), SW43.2
/Row5/KEY_4: D44.1 (K), SW44.2
/Row5/KEY_5: D45.1 (K), SW45.2
/Row5/KEY_6: D46.1 (K), SW46.2
/Row5/KEY_7: D47.1 (K), SW47.2
/Row5/KEY_8: D48.1 (K), SW48.2
/Row5/KEY_9: D49.1 (K), SW49.2
/Row5/KEY_10: D50.1 (K), SW50.2
/Row5/RGB_1: D96.4 (DOUT), D97.2 (DIN)
/Row5/RGB_2: D97.4 (DOUT), D98.2 (DIN)
/Row5/RGB_3: D98.4 (DOUT), D99.2 (DIN)
/Row5/RGB_4: D99.4 (DOUT), D100.2 (DIN)
/Row5/RGB_5: D100.4 (DOUT), D101.2 (DIN)
/Row5/RGB_6: D101.4 (DOUT), D102.2 (DIN)
/Row5/RGB_7: D102.4 (DOUT), D103.2 (DIN)
/Row5/RGB_8: D103.4 (DOUT), D104.2 (DIN)
/Row5/RGB_9: D104.4 (DOUT), D105.2 (DIN)
COL1: D11.2 (A), D21.2 (A), D41.2 (A); also elsewhere on the board
COL2: D12.2 (A), D22.2 (A), D42.2 (A); also elsewhere on the board
COL3: D13.2 (A), D23.2 (A), D43.2 (A); also elsewhere on the board
COL4: D14.2 (A), D24.2 (A), D44.2 (A); also elsewhere on the board
COL5: D15.2 (A), D25.2 (A), D45.2 (A); also elsewhere on the board
COL6: D16.2 (A), D26.2 (A), D46.2 (A); also elsewhere on the board
COL7: D17.2 (A), D27.2 (A), D47.2 (A); also elsewhere on the board
COL8: D18.2 (A), D28.2 (A), D48.2 (A); also elsewhere on the board
COL9: D19.2 (A), D29.2 (A), D49.2 (A); also elsewhere on the board
COL10: D20.2 (A), D30.2 (A), D50.2 (A); also elsewhere on the board
GND: C111.2, C112.2, C113.2, C114.2, C115.2, C116.2, C117.2, C118.2, C119.2, C120.2, C121.2, C122.2, C123.2, C124.2, C125.2, C126.2, C127.2, C128.2, C129.2, C130.2, C141.2, C142.2, C143.2, C144.2, C145.2, C146.2, C147.2, C148.2, C149.2, C150.2, D66.1 (VSS), D67.1 (VSS), D68.1 (VSS), D69.1 (VSS), D70.1 (VSS), D71.1 (VSS), D72.1 (VSS), D73.1 (VSS), D74.1 (VSS), D75.1 (VSS), D76.1 (VSS), D77.1 (VSS), D78.1 (VSS), D79.1 (VSS), D80.1 (VSS), D81.1 (VSS), D82.1 (VSS), D83.1 (VSS), D84.1 (VSS), D85.1 (VSS), D96.1 (VSS), D97.1 (VSS), D98.1 (VSS), D99.1 (VSS), D100.1 (VSS), D101.1 (VSS), D102.1 (VSS), D103.1 (VSS), D104.1 (VSS), D105.1 (VSS); also elsewhere on the board
VLED: C111.1, C112.1, C113.1, C114.1, C115.1, C116.1, C117.1, C118.1, C119.1, C120.1, C121.1, C122.1, C123.1, C124.1, C125.1, C126.1, C127.1, C128.1, C129.1, C130.1, C141.1, C142.1, C143.1, C144.1, C145.1, C146.1, C147.1, C148.1, C149.1, C150.1, D66.3 (VDD), D67.3 (VDD), D68.3 (VDD), D69.3 (VDD), D70.3 (VDD), D71.3 (VDD), D72.3 (VDD), D73.3 (VDD), D74.3 (VDD), D75.3 (VDD), D76.3 (VDD), D77.3 (VDD), D78.3 (VDD), D79.3 (VDD), D80.3 (VDD), D81.3 (VDD), D82.3 (VDD), D83.3 (VDD), D84.3 (VDD), D85.3 (VDD), D96.3 (VDD), D97.3 (VDD), D98.3 (VDD), D99.3 (VDD), D100.3 (VDD), D101.3 (VDD), D102.3 (VDD), D103.3 (VDD), D104.3 (VDD), D105.3 (VDD); also elsewhere on the board

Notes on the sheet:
KEY ROW / active-low scan / local RGB bypass
Column pull-up -> diode ANODE -> CATHODE -> switch -> selected LOW row. Unselected rows are high impedance; all rows go low for column EXTI wake. RGB data runs left to right. Each SK6812MINI-E has a 100nF bypass capacitor. Row4 omits COL6 (upper half of 2U ENTER); its data chain bridges the gap. Sh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

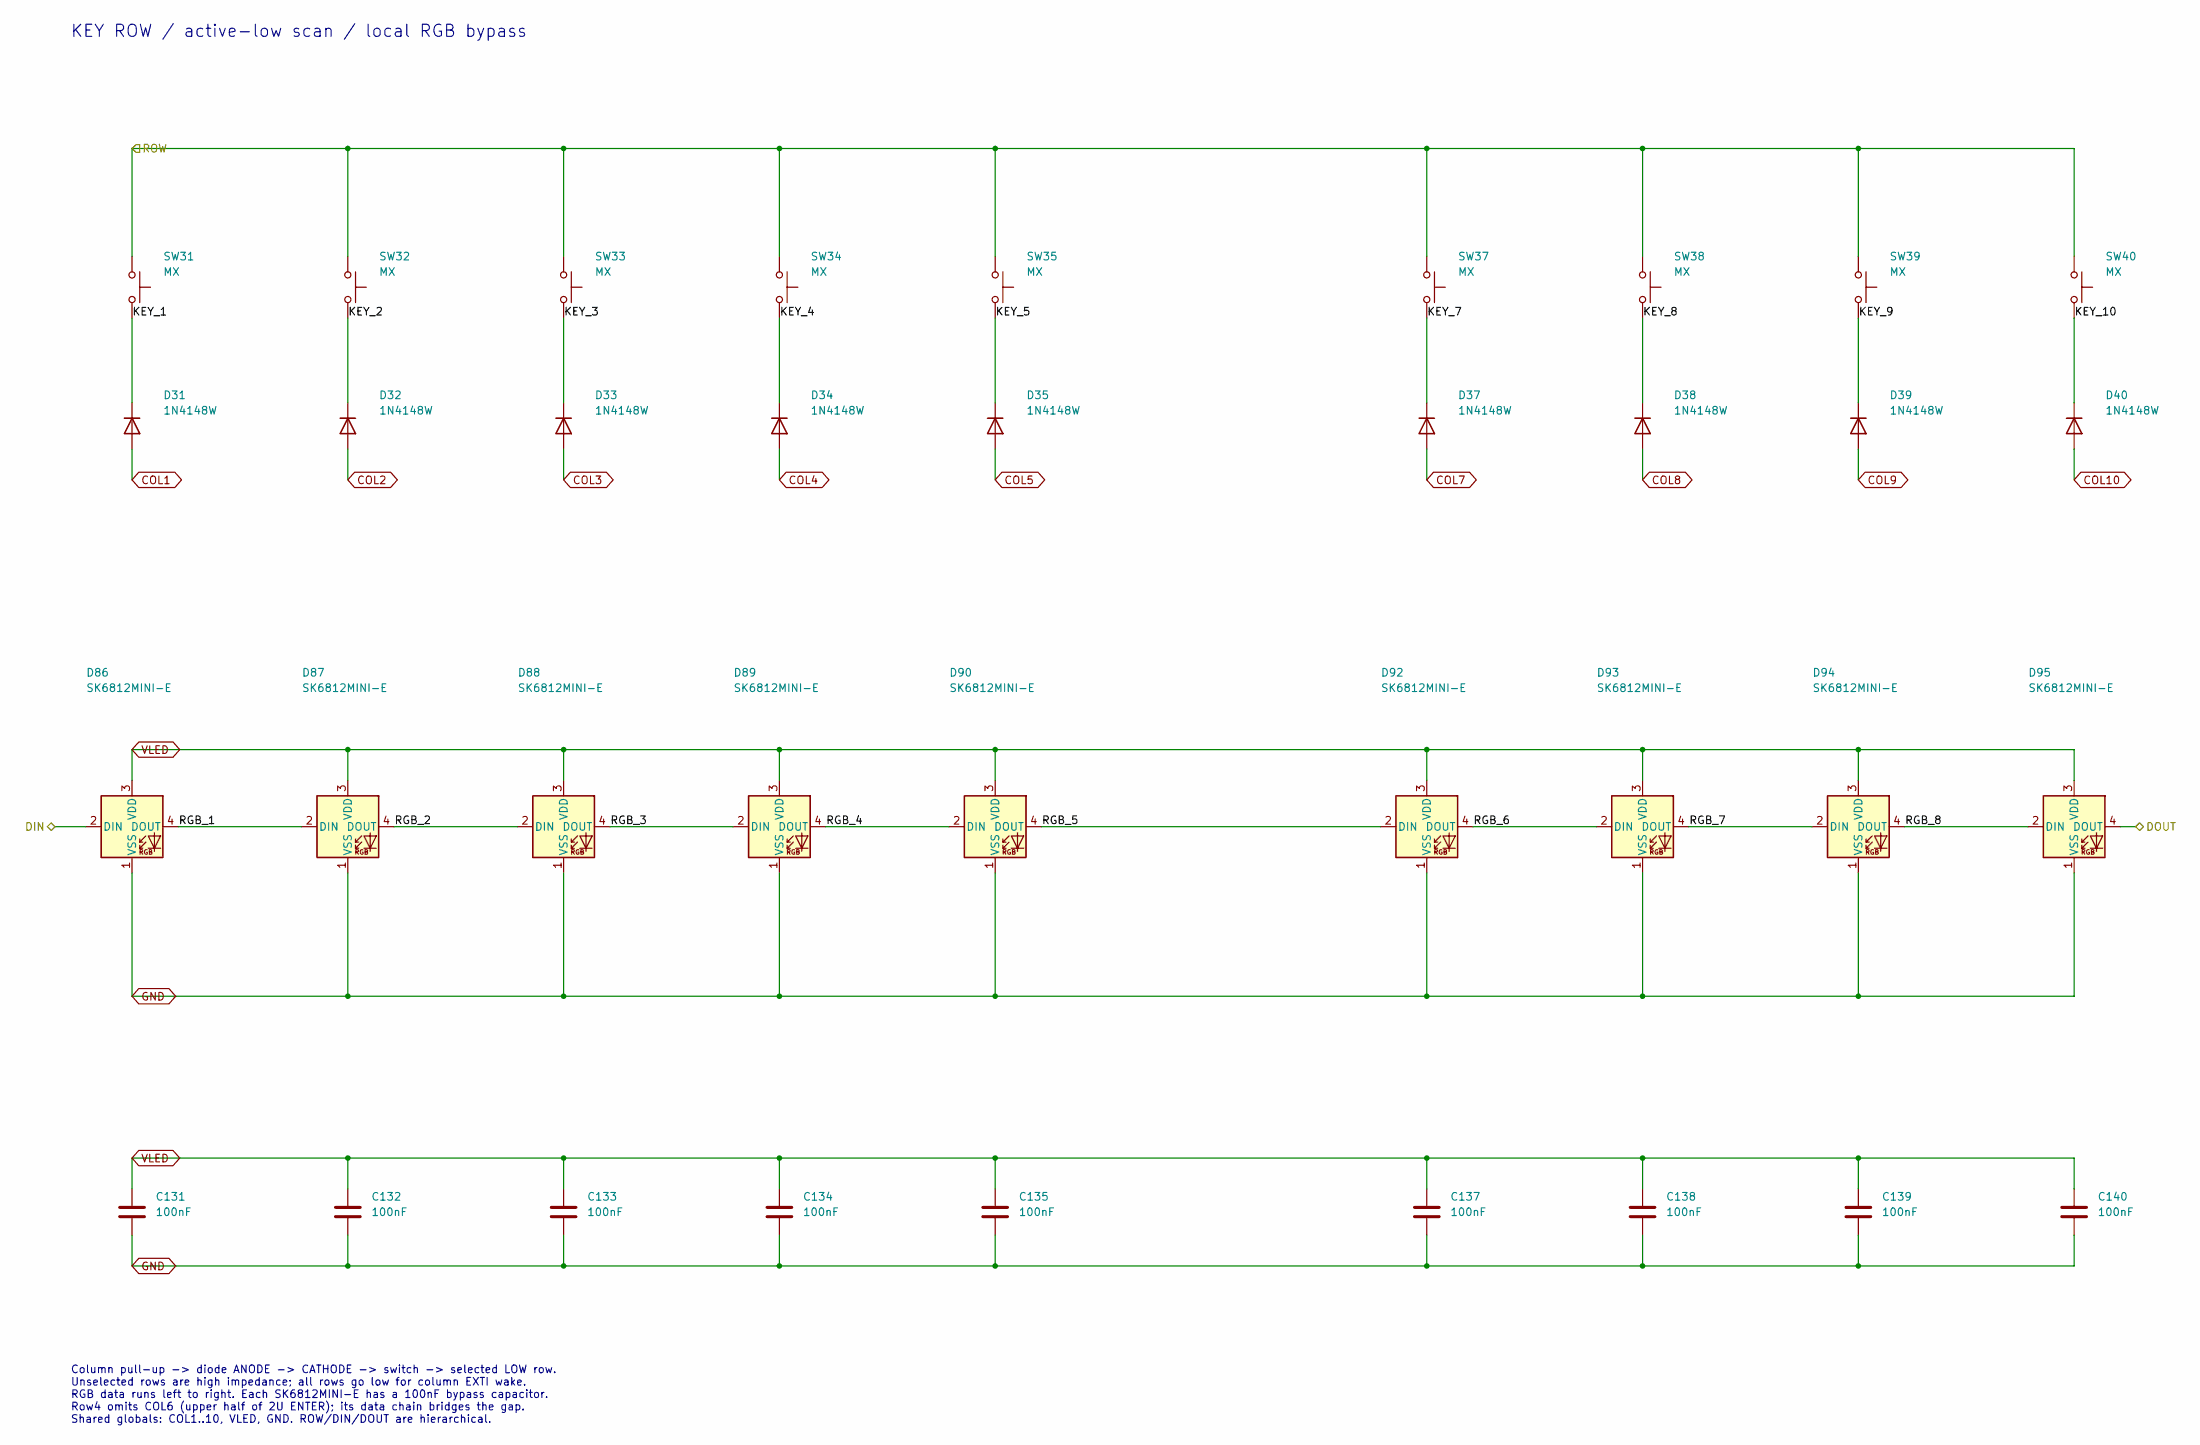
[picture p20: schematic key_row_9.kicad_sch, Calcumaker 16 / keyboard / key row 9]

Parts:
C131, C132, C133, C134, C135, C137, C138, C139, C140: 100nF; C_0402_1005Metric
D31, D32, D33, D34, D35, D37, D38, D39, D40: 1N4148W; D_SOD-123; MPN 1N4148W; LCSC C81598
D86, D87, D88, D89, D90, D92, D93, D94, D95: SK6812MINI-E; LED_SK6812MINI-E_3.2x2.8mm_P1.5mm_ReverseMount; MPN SK6812MINI-E; LCSC C5149201
SW31, SW32, SW33, SW34, SW35, SW37, SW38, SW39, SW40: MX; SW_MX_HS_CPG151101S11_1u

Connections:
/KB_ROW4: SW31.1, SW32.1, SW33.1, SW34.1, SW35.1, SW37.1, SW38.1, SW39.1, SW40.1; also elsewhere on the board
/Row3/DOUT: D86.2 (DIN); also elsewhere on the board
/Row4/DOUT: D95.4 (DOUT); also elsewhere on the board
/Row4/KEY_1: D31.1 (K), SW31.2
/Row4/KEY_2: D32.1 (K), SW32.2
/Row4/KEY_3: D33.1 (K), SW33.2
/Row4/KEY_4: D34.1 (K), SW34.2
/Row4/KEY_5: D35.1 (K), SW35.2
/Row4/KEY_7: D37.1 (K), SW37.2
/Row4/KEY_8: D38.1 (K), SW38.2
/Row4/KEY_9: D39.1 (K), SW39.2
/Row4/KEY_10: D40.1 (K), SW40.2
/Row4/RGB_1: D86.4 (DOUT), D87.2 (DIN)
/Row4/RGB_2: D87.4 (DOUT), D88.2 (DIN)
/Row4/RGB_3: D88.4 (DOUT), D89.2 (DIN)
/Row4/RGB_4: D89.4 (DOUT), D90.2 (DIN)
/Row4/RGB_5: D90.4 (DOUT), D92.2 (DIN)
/Row4/RGB_6: D92.4 (DOUT), D93.2 (DIN)
/Row4/RGB_7: D93.4 (DOUT), D94.2 (DIN)
/Row4/RGB_8: D94.4 (DOUT), D95.2 (DIN)
COL1: D31.2 (A); also elsewhere on the board
COL2: D32.2 (A); also elsewhere on the board
COL3: D33.2 (A); also elsewhere on the board
COL4: D34.2 (A); also elsewhere on the board
COL5: D35.2 (A); also elsewhere on the board
COL7: D37.2 (A); also elsewhere on the board
COL8: D38.2 (A); also elsewhere on the board
COL9: D39.2 (A); also elsewhere on the board
COL10: D40.2 (A); also elsewhere on the board
GND: C131.2, C132.2, C133.2, C134.2, C135.2, C137.2, C138.2, C139.2, C140.2, D86.1 (VSS), D87.1 (VSS), D88.1 (VSS), D89.1 (VSS), D90.1 (VSS), D92.1 (VSS), D93.1 (VSS), D94.1 (VSS), D95.1 (VSS); also elsewhere on the board
VLED: C131.1, C132.1, C133.1, C134.1, C135.1, C137.1, C138.1, C139.1, C140.1, D86.3 (VDD), D87.3 (VDD), D88.3 (VDD), D89.3 (VDD), D90.3 (VDD), D92.3 (VDD), D93.3 (VDD), D94.3 (VDD), D95.3 (VDD); also elsewhere on the board

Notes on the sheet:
Column pull-up -> diode ANODE -> CATHODE -> switch -> selected LOW row. Unselected rows are high impedance; all rows go low for column EXTI wake. RGB data runs left to right. Each SK6812MINI-E has a 100nF bypass capacitor. Row4 omits COL6 (upper half of 2U ENTER); its data chain bridges the gap. Sh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
KEY ROW / active-low scan / local RGB bypass

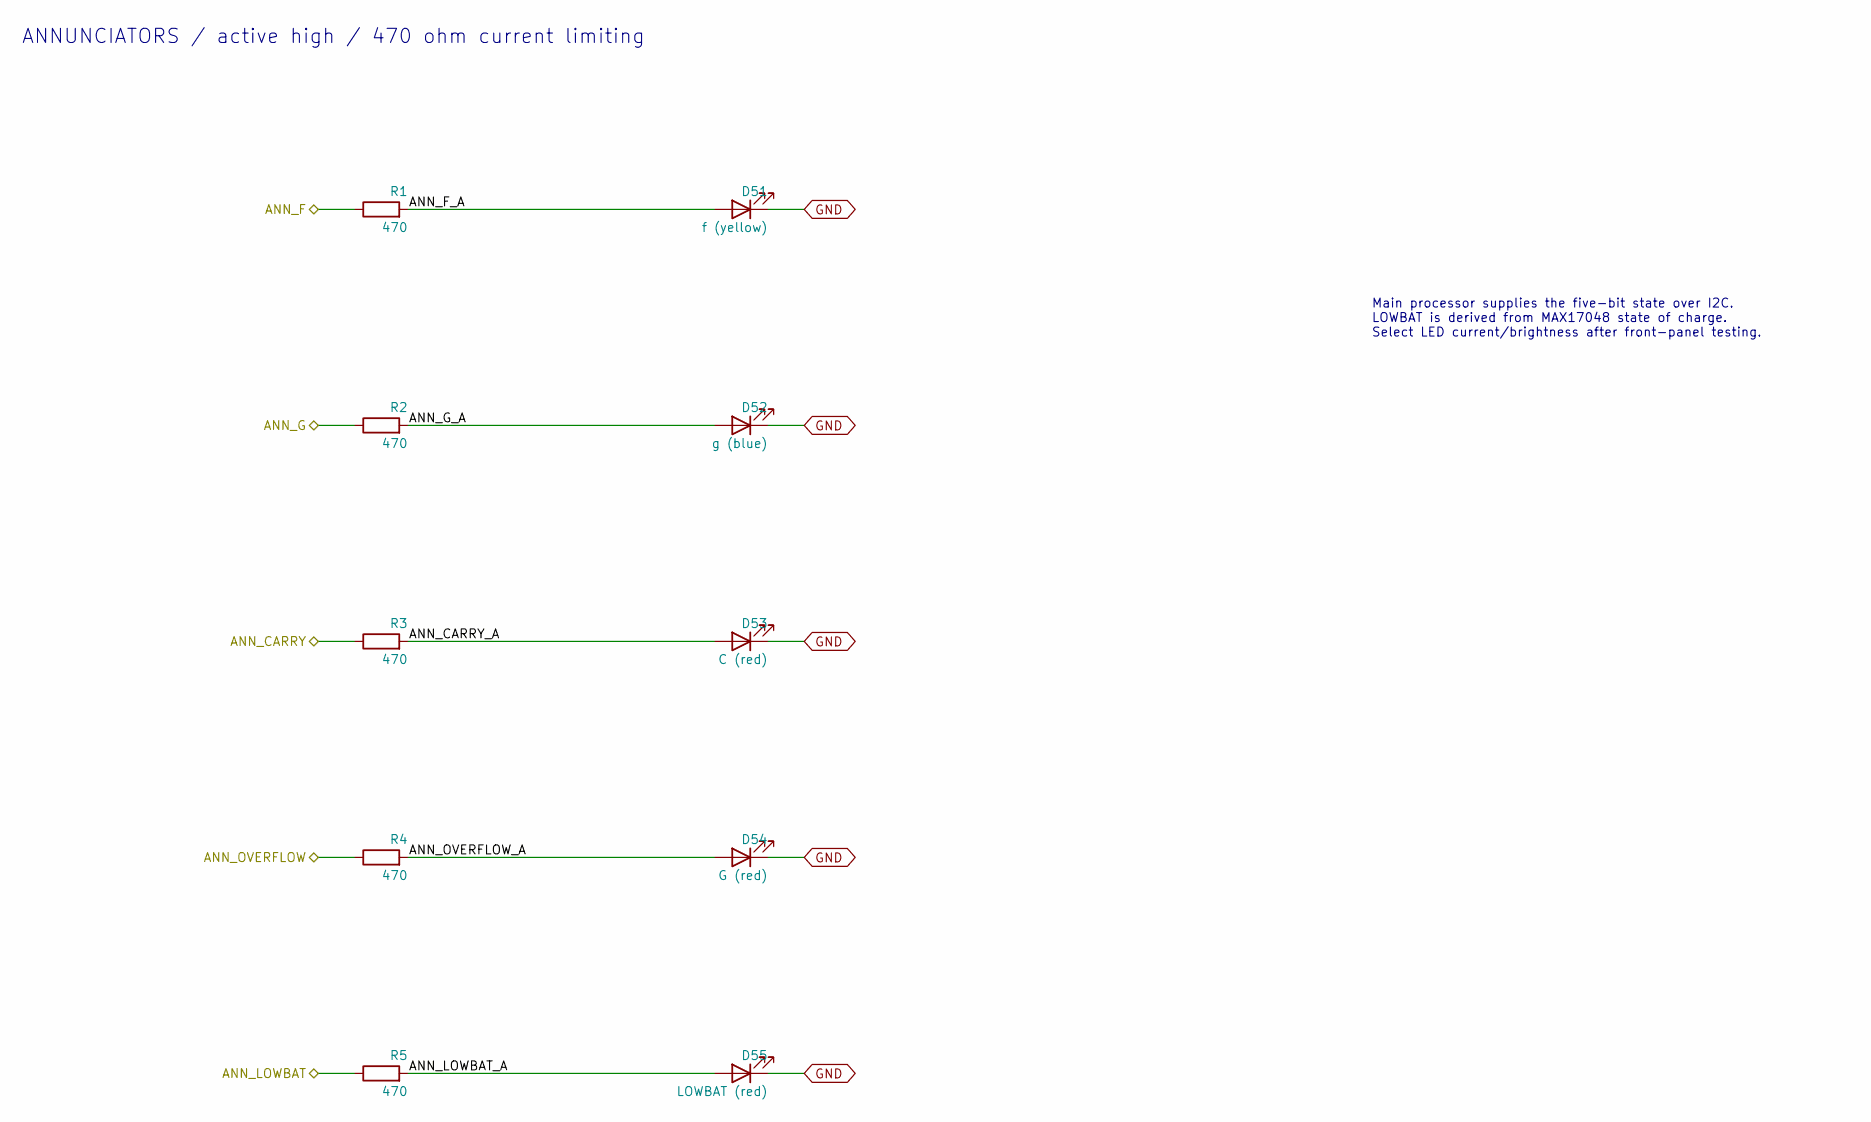
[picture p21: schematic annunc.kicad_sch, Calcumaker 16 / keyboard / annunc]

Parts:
D51: f (yellow); LED_0603_1608Metric; MPN 19-213/Y2C-CQ2R2L/3T(CY); LCSC C72038
D52: g (blue); LED_0603_1608Metric; MPN XL-1608UBC-04; LCSC C965807
D53: C (red); LED_0603_1608Metric; MPN KT-0603R; LCSC C2286
D54: G (red); LED_0603_1608Metric; MPN KT-0603R; LCSC C2286
D55: LOWBAT (red); LED_0603_1608Metric; MPN KT-0603R; LCSC C2286
R1, R2, R3, R4, R5: 470; R_0402_1005Metric; LCSC C25117

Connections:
/ANN_CARRY: R3.1; also elsewhere on the board
/ANN_F: R1.1; also elsewhere on the board
/ANN_G: R2.1; also elsewhere on the board
/ANN_LOWBAT: R5.1; also elsewhere on the board
/ANN_OVERFLOW: R4.1; also elsewhere on the board
/Annunciators/ANN_CARRY_A: D53.2 (A), R3.2
/Annunciators/ANN_F_A: D51.2 (A), R1.2
/Annunciators/ANN_G_A: D52.2 (A), R2.2
/Annunciators/ANN_LOWBAT_A: D55.2 (A), R5.2
/Annunciators/ANN_OVERFLOW_A: D54.2 (A), R4.2
GND: D51.1 (K), D52.1 (K), D53.1 (K), D54.1 (K), D55.1 (K); also elsewhere on the board

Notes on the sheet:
Main processor supplies the five-bit state over I2C. LOWBAT is derived from MAX17048 state of charge. Select LED current/brightness after front-panel testing.
ANNUNCIATORS / active high / 470 ohm current limiting

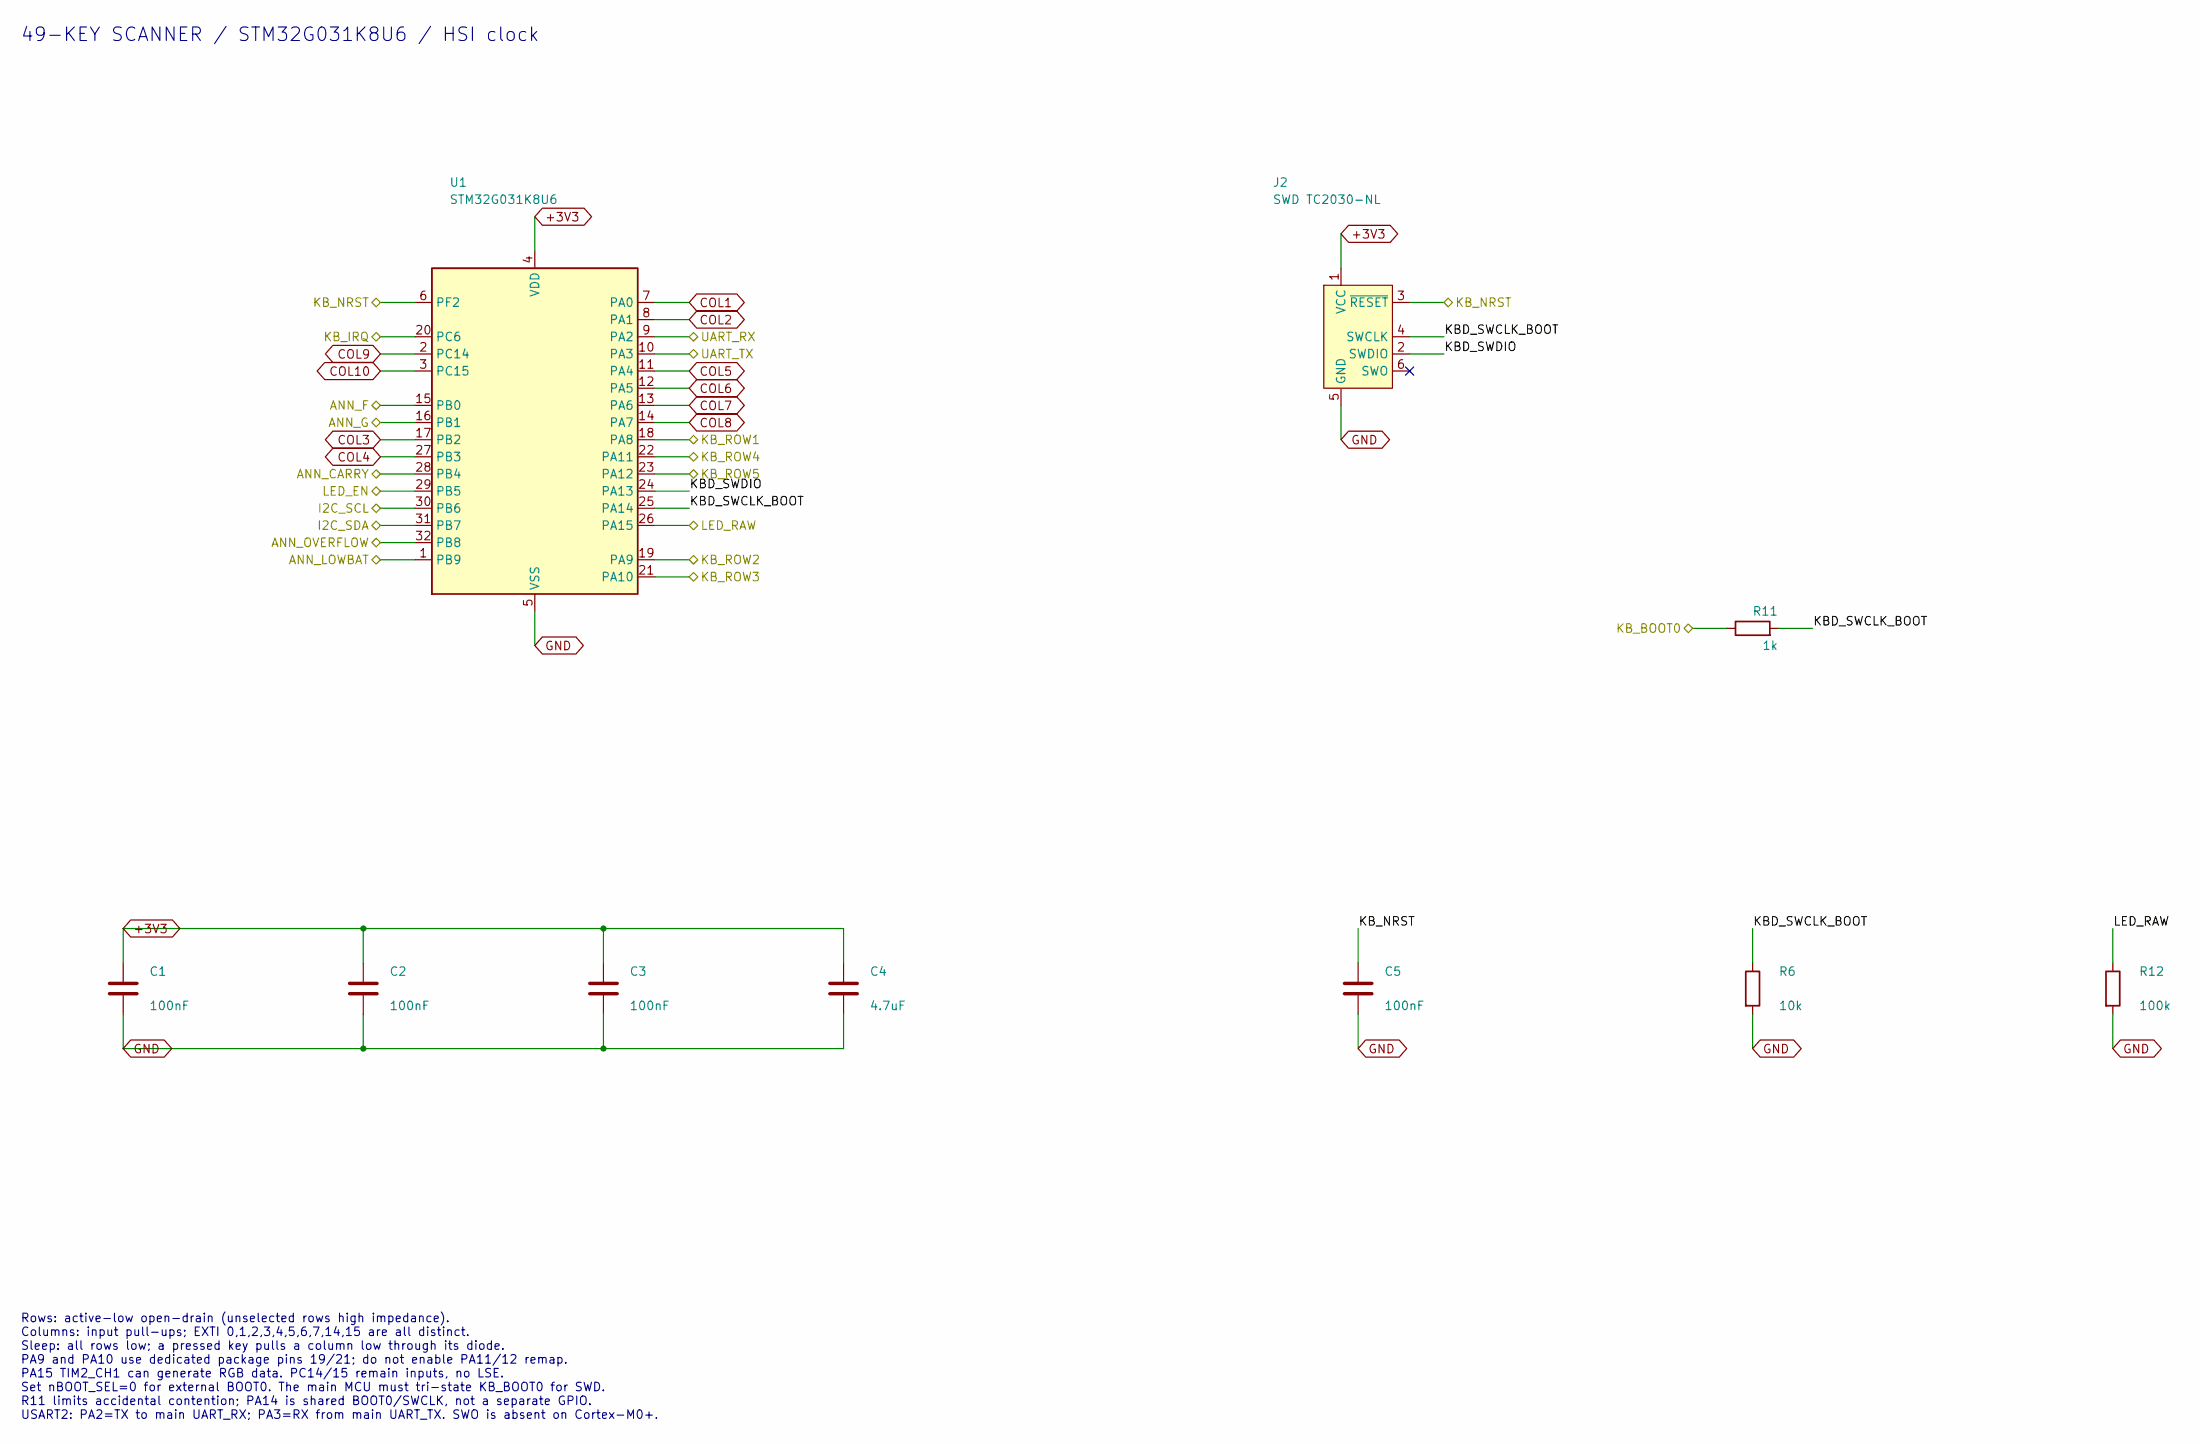
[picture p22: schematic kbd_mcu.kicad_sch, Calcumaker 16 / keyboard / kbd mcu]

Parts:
C1, C2, C3, C5: 100nF; C_0402_1005Metric; LCSC C1525
C4: 4.7uF; C_0603_1608Metric
J2: SWD TC2030-NL; Tag-Connect_TC2030-IDC-NL_2x03_P1.27mm_Vertical
R6: 10k; R_0402_1005Metric; LCSC C25744
R11: 1k; R_0402_1005Metric
R12: 100k; R_0402_1005Metric
U1: STM32G031K8U6; UFQFPN-32-1EP_5x5mm_P0.5mm_EP3.5x3.5mm; MPN STM32G031K8U6; LCSC C432207

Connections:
+3V3: C1.1, C2.1, C3.1, C4.1, J2.1 (VCC), U1.4 (VDD); also elsewhere on the board
/ANN_CARRY: U1.28 (PB4); also elsewhere on the board
/ANN_F: U1.15 (PB0); also elsewhere on the board
/ANN_G: U1.16 (PB1); also elsewhere on the board
/ANN_LOWBAT: U1.1 (PB9); also elsewhere on the board
/ANN_OVERFLOW: U1.32 (PB8); also elsewhere on the board
/I2C_SCL: U1.30 (PB6); also elsewhere on the board
/I2C_SDA: U1.31 (PB7); also elsewhere on the board
/KB_BOOT0: R11.1; also elsewhere on the board
/KB_IRQ: U1.20 (PC6); also elsewhere on the board
/KB_NRST: C5.1, J2.3 (~RESET), U1.6 (PF2); also elsewhere on the board
/KB_ROW1: U1.18 (PA8); also elsewhere on the board
/KB_ROW2: U1.19 (PA9); also elsewhere on the board
/KB_ROW3: U1.21 (PA10); also elsewhere on the board
/KB_ROW4: U1.22 (PA11); also elsewhere on the board
/KB_ROW5: U1.23 (PA12); also elsewhere on the board
/KbdMCU/KBD_SWCLK_BOOT: J2.4 (SWCLK), R6.1, R11.2, U1.25 (PA14)
/KbdMCU/KBD_SWDIO: J2.2 (SWDIO), U1.24 (PA13)
/LED_EN: U1.29 (PB5); also elsewhere on the board
/LED_RAW: R12.1, U1.26 (PA15); also elsewhere on the board
/UART_RX: U1.9 (PA2); also elsewhere on the board
/UART_TX: U1.10 (PA3); also elsewhere on the board
COL1: U1.7 (PA0); also elsewhere on the board
COL2: U1.8 (PA1); also elsewhere on the board
COL3: U1.17 (PB2); also elsewhere on the board
COL4: U1.27 (PB3); also elsewhere on the board
COL5: U1.11 (PA4); also elsewhere on the board
COL6: U1.12 (PA5); also elsewhere on the board
COL7: U1.13 (PA6); also elsewhere on the board
COL8: U1.14 (PA7); also elsewhere on the board
COL9: U1.2 (PC14); also elsewhere on the board
COL10: U1.3 (PC15); also elsewhere on the board
GND: C1.2, C2.2, C3.2, C4.2, C5.2, J2.5 (GND), R6.2, R12.2, U1.5 (VSS), U1.33 (VSS); also elsewhere on the board

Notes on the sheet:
49-KEY SCANNER / STM32G031K8U6 / HSI clock
Rows: active-low open-drain (unselected rows high impedance). Columns: input pull-ups; EXTI 0,1,2,3,4,5,6,7,14,15 are all distinct. Sleep: all rows low; a pressed key pulls a column low through its diode. PA9 and PA10 use dedicated package pins 19/21; do not enable PA11/12 remap. PA15 TIM2_CH1 can 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

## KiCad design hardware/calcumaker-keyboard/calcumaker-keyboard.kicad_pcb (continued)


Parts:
C6: 100nF; C_0402_1005Metric; LCSC C1525
C7: 22uF; C_0603_1608Metric
Q1: AO3401A; SOT-23; MPN AO3401A; LCSC C15127
Q2: 2N7002; SOT-23; MPN 2N7002; LCSC C8545
R7, R10: 100k; R_0402_1005Metric; LCSC C25741
R8: 10k; R_0402_1005Metric; LCSC C25744
R9: 330; R_0402_1005Metric
U2: 74LVC1G125; SOT-23-5; MPN SN74LVC1G125DBVR; LCSC C23654

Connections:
/LED_EN: R8.1; also elsewhere on the board
/LED_RAW: U2.2; also elsewhere on the board
/RGBPower/LED_BUFFER: R9.1, U2.4
/RGBPower/LED_EN_GATE: Q2.1 (G), R8.2, R10.1
/RGBPower/LED_GATE: Q1.1 (G), Q2.3 (D), R7.2
/RGB_FIRST: R9.2; also elsewhere on the board
GND: C6.2, C7.2, Q2.2 (S), R10.2, U2.1, U2.3 (GND); also elsewhere on the board
VLED: C6.1, C7.1, Q1.3 (D), U2.5 (VCC); also elsewhere on the board
VSYS: Q1.2 (S), R7.1; also elsewhere on the board

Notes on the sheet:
RGB POWER / VSYS high-side switch + data buffer
R7 defaults P-FET off. Q2 turns it on when LED_EN is high. Before removing VLED: hold LED_RAW low, then clear LED_EN. VSYS is unregulated battery/system power; see DESIGN.md for the unresolved SK6812 voltage/headroom and LVC input-threshold validation before fabrication. Cap total brightness to con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


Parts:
J1: TO MCU (stack); Hirose_DF40C-12DP-0.4V_2x06-1MP_P0.4mm; MPN DF40C-12DP-0.4V(51); LCSC C6224952
J3: TO MCU (FFC); Hirose_FH12-16S-0.5SH_1x16-1MP_P0.50mm_Horizontal; MPN AFC01-S16FCA-00; LCSC C262665

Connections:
+3V3: J1.1, J3.1; also elsewhere on the board
/I2C_SCL: J1.4, J3.4; also elsewhere on the board
/I2C_SDA: J1.3, J3.3; also elsewhere on the board
/KB_BOOT0: J1.9, J3.9; also elsewhere on the board
/KB_IRQ: J1.7, J3.7; also elsewhere on the board
/KB_NRST: J1.8, J3.8; also elsewhere on the board
/UART_RX: J1.6, J3.6; also elsewhere on the board
/UART_TX: J1.5, J3.5; also elsewhere on the board
GND: J1.2, J1.10, J1.12, J3.2, J3.10, J3.13, J3.14; also elsewhere on the board
VSYS: J1.11, J3.11, J3.12; also elsewhere on the board

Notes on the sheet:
KEYBOARD LINK / populate one connector
DF40 stack and 16-way FFC have the same signal nets. UART_TX = main TX -> keyboard RX; UART_RX = keyboard TX -> main RX. Use a pin-1-to-pin-1 cable; verify contact orientation against the physical connectors. FFC pins 15/16 are deliberately unused. VSYS is the charger SYS output. KB_BOOT0 shares G0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

Board: 2 copper layers, 227 parts (222 on the bottom side), 141 nets, no tracks yet.

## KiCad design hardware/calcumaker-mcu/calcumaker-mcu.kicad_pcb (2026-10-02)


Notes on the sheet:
CALCUMAKER 16 / LOGIC MAINBOARD
Shared power nets: +3V3, VSYS, BAT+, GND. I2C1 is shared by keyboard, charger and gauge. Signal connectivity crosses explicit sheet pins. Display connector + SWD + LSE are on MCU. Read hardware/WIRING_REVIEW.md for the pin map, net checks and remaining physical validation.


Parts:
J5: TO KEYBOARD (stack); Hirose_DF40B-12DS-0.4V_2x06-1MP_P0.4mm; MPN DF40B-12DS-0.4V(58); LCSC C3641147
J6: TO KEYBOARD (FFC); Hirose_FH12-16S-0.5SH_1x16-1MP_P0.50mm_Horizontal; MPN AFC01-S16FCA-00; LCSC C262665

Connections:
+3V3: J5.1, J6.1; also elsewhere on the board
/I2C_SCL: J5.4, J6.4; also elsewhere on the board
/I2C_SDA: J5.3, J6.3; also elsewhere on the board
/KB_BOOT0: J5.9, J6.9; also elsewhere on the board
/KB_IRQ: J5.7, J6.7; also elsewhere on the board
/KB_NRST: J5.8, J6.8; also elsewhere on the board
/UART_RX: J5.6, J6.6; also elsewhere on the board
/UART_TX: J5.5, J6.5; also elsewhere on the board
GND: J5.2, J5.10, J5.12, J6.2, J6.10, J6.13, J6.14; also elsewhere on the board
VSYS: J5.11, J6.11, J6.12; also elsewhere on the board

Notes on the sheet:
KEYBOARD LINK / populate one connector
DF40 stack and 16-way FFC have the same signal nets. UART_TX = main TX -> keyboard RX; UART_RX = keyboard TX -> main RX. Use a pin-1-to-pin-1 cable; verify contact orientation against the physical connectors. FFC pins 15/16 are deliberately unused. VSYS is the charger SYS output. KB_BOOT0 shares G0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


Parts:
C12, C13, C14, C15, C16, C19, C20, C21: 100nF; C_0402_1005Metric; LCSC C1525
C17: 10uF; C_0603_1608Metric
C18: 1uF; C_0402_1005Metric; LCSC C29266
C22, C23: 2.2uF 10V low ESR; C_0603_1608Metric
C24, C25: 12pF; C_0402_1005Metric; LCSC C1547
J3: TO DISPLAY (unified SPI FFC); Hirose_FH12-12S-0.5SH_1x12-1MP_P0.50mm_Horizontal; MPN AFC01-S12FCA-00; LCSC C262661
J4: SWD TC2030-NL; Tag-Connect_TC2030-IDC-NL_2x03_P1.27mm_Vertical
J7: VSYS -> matrix LED pwr; JST_PH_S2B-PH-K_1x02_P2.00mm_Horizontal; MPN S2B-PH-K-S; LCSC C173752
R8: 10k; R_0402_1005Metric; LCSC C25744
R13, R14: 4.7k; R_0402_1005Metric
U1: STM32U575RGT6; LQFP-64_10x10mm_P0.5mm; MPN STM32U575RGT6; LCSC C5270980
Y1: 32.768kHz; Crystal_SMD_3215-2Pin_3.2x1.5mm; MPN Q13FC13500004; LCSC C32346

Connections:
+3V3: C12.1, C13.1, C14.1, C15.1, C16.1, C17.1, C18.1, C19.1, C20.1, J3.5, J4.1 (VCC), R13.1, R14.1, U1.1 (VBAT), U1.13 (VDDA), U1.19 (VDD), U1.32 (VDD), U1.48 (VDDUSB), U1.64 (VDD); also elsewhere on the board
/BAT_SENSE: U1.9 (PC1); also elsewhere on the board
/CHG_CE: U1.25 (PC5); also elsewhere on the board
/CHG_INT: U1.10 (PC2); also elsewhere on the board
/CHG_PG: U1.24 (PC4); also elsewhere on the board
/GAUGE_ALRT: U1.2 (PC13); also elsewhere on the board
/I2C_SCL: R13.2, U1.58 (PB6); also elsewhere on the board
/I2C_SDA: R14.2, U1.59 (PB7); also elsewhere on the board
/KB_BOOT0: U1.52 (PC11); also elsewhere on the board
/KB_IRQ: U1.14 (PA0); also elsewhere on the board
/KB_NRST: U1.51 (PC10); also elsewhere on the board
/MCU/BOOT0: R8.1, U1.60 (PH3)
/MCU/DISP_BOOT: J3.11, U1.40 (PC9)
/MCU/DISP_IRQ: J3.9, U1.33 (PB12)
/MCU/DISP_NRST: J3.10, U1.39 (PC8)
/MCU/LSE_IN: C24.1, U1.3 (PC14), Y1.1
/MCU/LSE_OUT: C25.1, U1.4 (PC15), Y1.2
/MCU/NRST: C21.1, J4.3 (~RESET), U1.7 (NRST)
/MCU/SPI_CS: J3.8, U1.41 (PA8)
/MCU/SPI_MOSI: J3.7, U1.57 (PB5)
/MCU/SPI_SCLK: J3.6, U1.21 (PA5)
/MCU/SWCLK: J4.4 (SWCLK), U1.49 (PA14)
/MCU/SWDIO: J4.2 (SWDIO), U1.46 (PA13)
/MCU/SWO: J4.6 (SWO), U1.55 (PB3)
/MCU/VCAP: C22.1, C23.1, U1.30 (VCAP)
/QSPI_CLK: U1.29 (PB10); also elsewhere on the board
/QSPI_IO0: U1.27 (PB1); also elsewhere on the board
/QSPI_IO1: U1.26 (PB0); also elsewhere on the board
/QSPI_IO2: U1.23 (PA7); also elsewhere on the board
/QSPI_IO3: U1.22 (PA6); also elsewhere on the board
/QSPI_NCS: U1.20 (PA4); also elsewhere on the board
/TCPP01_DB: U1.38 (PC7); also elsewhere on the board
/TCPP01_EN: U1.37 (PC6); also elsewhere on the board
/TCPP01_FLT: U1.11 (PC3); also elsewhere on the board
/UART_RX: U1.17 (PA3); also elsewhere on the board
/UART_TX: U1.16 (PA2); also elsewhere on the board
/UCPD_CC1: U1.50 (PA15); also elsewhere on the board
/UCPD_CC2: U1.36 (PB15); also elsewhere on the board
/USB_DM: U1.44 (PA11); also elsewhere on the board
/USB_DP: U1.45 (PA12); also elsewhere on the board
/VBUS_SENSE: U1.8 (PC0); also elsewhere on the board
GND: C12.2, C13.2, C14.2, C15.2, C16.2, C17.2, C18.2, C19.2, C20.2, C21.2, C22.2, C23.2, C24.2, C25.2, J3.3, J3.4, J3.12, J4.5 (GND), J7.2, R8.2, U1.12 (VSSA), U1.18 (VSS), U1.31 (VSS), U1.47 (VSS), U1.63 (VSS); also elsewhere on the board
VSYS: J3.1, J3.2, J7.1; also elsewhere on the board

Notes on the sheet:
PB15 = pin 36 (CC2); pin 63 is VSS. KB_IRQ PA0/WKUP1; gauge PC13/WKUP2. CHG_INT PC2, TCPP_FLT PC3, DISP_IRQ PB12: distinct EXTI lines. VBAT uses regulated 3V3, never the raw 4.2V cell. Only R13/R14 pull up the shared I2C bus.
STM32U575RGT6 / LQFP64 / LDO core supply
LSE 32.768 kHz; fit load capacitors for crystal CL + PCB stray.
VCAP: 2 x 2.2uF, >=10V, combined ESR <20mohm at 3MHz. No 3V3 connection.


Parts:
C26: 100nF; C_0402_1005Metric; LCSC C1525
R9: 10k; R_0402_1005Metric; LCSC C25744
U7: W25Q32JVSSIQ; SOIC-8_5.3x5.3mm_P1.27mm; MPN W25Q32JVSSIQ; LCSC C179173

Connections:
+3V3: C26.1, R9.1, U7.8 (VCC); also elsewhere on the board
/QSPI_CLK: U7.6 (CLK); also elsewhere on the board
/QSPI_IO0: U7.5 (DI/IO_{0}); also elsewhere on the board
/QSPI_IO1: U7.2 (DO/IO_{1}); also elsewhere on the board
/QSPI_IO2: U7.3 (~WP/IO_{2}); also elsewhere on the board
/QSPI_IO3: U7.7 (~HOLD/~RESET/IO_{3}); also elsewhere on the board
/QSPI_NCS: R9.2, U7.1 (~CS); also elsewhere on the board
GND: C26.2, U7.4 (GND); also elsewhere on the board

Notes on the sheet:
4MB QUAD-SPI NOR / OCTOSPI1 port 1
CS# defaults high. IO2/WP# and IO3/HOLD# are data pins in quad mode. Enable the flash QE bit before using all four IO signals. Place C26 close to U7.

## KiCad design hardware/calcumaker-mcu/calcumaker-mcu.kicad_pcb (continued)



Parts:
C1: 1uF 50V; C_0603_1608Metric; MPN CL10A105KB8NNNC; LCSC C15849
C2, C6: 10uF 50V; C_0805_2012Metric; MPN GRM21BR61H106KE43L; LCSC C440198
C3, C4, C5, C7, C8, C9, C10: 10uF; C_0603_1608Metric
C11: 4.7uF 10V; C_0603_1608Metric
C27: 47nF; C_0402_1005Metric
C28, C29: 150pF; C_0402_1005Metric
C30: 100nF 50V X7R; C_0603_1608Metric; MPN CC0603KRX7R9BB104; LCSC C14663
C31, C32: 100nF; C_0402_1005Metric; LCSC C1525
C33: 100nF; C_0402_1005Metric
D2: CHG; LED_0402_1005Metric; LCSC C130719
J1: USB-C; USB_C_Receptacle_GCT_USB4105-xx-A_16P_TopMnt_Horizontal; MPN USB-TYPE-C-019; LCSC C2927039
J2: BAT 1S Li-ion; JST_PH_S2B-PH-K_1x02_P2.00mm_Horizontal; MPN S2B-PH-K-S; LCSC C173752
J8: PACK NTC 10k 103AT-2; JST_PH_S2B-PH-K_1x02_P2.00mm_Horizontal
J9: SHIP WAKE (short to wake); PinHeader_1x02_P2.54mm_Vertical
L1: 2.2uH; L_0805_2012Metric
L2: 2.2uH; L_Changjiang_FNR4020S
Q1: AO3400A; SOT-23; MPN AO3400A; LCSC C20917
R1, R11, R12: 100k; R_0402_1005Metric; LCSC C25741
R2: 5.23k; R_0402_1005Metric
R3: 30.1k; R_0402_1005Metric
R4: 200k; R_0402_1005Metric
R5: 1k; R_0402_1005Metric; LCSC C11702
R6: 10k; R_0402_1005Metric; LCSC C25744
R7: 976R; R_0402_1005Metric
R10: 40.2k; R_0402_1005Metric
R15, R16: 10k; R_0402_1005Metric
R17: 100k; R_0402_1005Metric
R18: 36.5k 1%; R_0402_1005Metric
R19: 16.2k 1%; R_0402_1005Metric
R20, R21: 1M 1%; R_0402_1005Metric
U2: TPS63900DSKR; WSON-10-1EP_2.5x2.5mm_P0.5mm_EP1.2x2mm; MPN TPS63900DSKR; LCSC C1518762
U3: USBLC6-2SC6; SOT-23-6; MPN USBLC6-2SC6; LCSC C2687116
U4: BQ25601RTWR; Texas_RTW_WQFN-24-1EP_4x4mm_P0.5mm_EP2.7x2.7mm_ThermalVias; MPN BQ25601RTWR; LCSC C468236
U5: TCPP01-M12; QFN-12-1EP_3x3mm_P0.5mm_EP1.45x1.45mm_ThermalVias; MPN TCPP01-M12; LCSC C1121848
U6: MAX17048G+T10; TDFN-8-1EP_2x2mm_P0.5mm_EP0.8x1.2mm; MPN MAX17048G+T10; LCSC C2682616

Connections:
+3V3: C4.1, C5.1, C7.1, R5.1, R11.1, R12.1, R15.1, R16.1, R17.1, U2.6 (VOUT), U3.5 (VBUS); also elsewhere on the board
/BAT_SENSE: C33.1, R20.2, R21.1; also elsewhere on the board
/CHG_CE: R17.2, U4.9 (~CE); also elsewhere on the board
/CHG_INT: R15.2, U4.7 (~INT); also elsewhere on the board
/CHG_PG: R16.2, U4.3 (~PG); also elsewhere on the board
/GAUGE_ALRT: R12.2, U6.5 (ALRT); also elsewhere on the board
/I2C_SCL: U4.5 (SCL), U6.7 (SCL); also elsewhere on the board
/I2C_SDA: U4.6 (SDA), U6.8 (SDA); also elsewhere on the board
/PSU/CC1_CONN: C28.1, J1.A5 (CC1), U5.7 (CC1c)
/PSU/CC2_CONN: C29.1, J1.B5 (CC2), U5.9 (CC2c)
/PSU/CFG1: R18.1, U2.3 (CFG1)
/PSU/CFG3: R19.1, U2.5 (CFG3)
/PSU/CHG_BTST: C27.1, U4.21 (BTST)
/PSU/CHG_LED_A: D2.2 (A), R5.2
/PSU/CHG_QON: J9.1, U4.12 (~QON)
/PSU/CHG_STAT: D2.1 (K), U4.4 (STAT)
/PSU/CHG_SW: C27.2, L2.1, U4.19 (SW), U4.20 (SW)
/PSU/CHG_TS: J8.1, R2.2, R3.1, U4.11 (TS)
/PSU/LX1: L1.1, U2.9 (LX1)
/PSU/LX2: L1.2, U2.7 (LX2)
/PSU/PMID: C2.1, U4.23 (PMID)
/PSU/PSEL: R1.2, U4.2 (PSEL)
/PSU/REGN: C11.1, R1.1, R2.1, U4.22 (REGN)
/PSU/USB_DM_CONN: J1.A7 (D-), J1.B7 (D-), U3.3 (I/O2)
/PSU/USB_DP_CONN: J1.A6 (D+), J1.B6 (D+), U3.1 (I/O1)
/PSU/VBUS_CTRL: R6.2, R7.1, U5.6 (VBUS_CTRL)
/PSU/VBUS_GATE: Q1.1 (G), U5.5 (GATE)
/PSU/VBUS_IN: C30.1, J1.A4 (VBUS), J1.A9 (VBUS), J1.B4 (VBUS), J1.B9 (VBUS), Q1.3 (D), R4.1, R6.1, U5.8 (IN_GD)
/PSU/VBUS_PROT: C1.1, C6.1, Q1.2 (S), U4.1 (VAC), U4.24 (VBUS), U5.4 (SOURCE)
/TCPP01_DB: U5.10 (DB); also elsewhere on the board
/TCPP01_EN: C31.1, U5.12 (VCC); also elsewhere on the board
/TCPP01_FLT: R11.2, U5.11 (FLT); also elsewhere on the board
/UCPD_CC1: U5.3 (CC1); also elsewhere on the board
/UCPD_CC2: U5.1 (CC2); also elsewhere on the board
/USB_DM: U3.4 (I/O2); also elsewhere on the board
/USB_DP: U3.6 (I/O1); also elsewhere on the board
/VBUS_SENSE: R4.2, R10.1; also elsewhere on the board
BAT+: C10.1, C32.1, J2.1, R20.1, U4.13 (BAT), U4.14 (BAT), U6.2 (CELL), U6.3 (VDD)
GND: C1.2, C2.2, C3.2, C4.2, C5.2, C6.2, C7.2, C8.2, C9.2, C10.2, C11.2, C28.2, C29.2, C30.2, C31.2, C32.2, C33.2, J1.A1 (GND), J1.A12 (GND), J1.B1 (GND), J1.B12 (GND), J1.SH (SHIELD), J2.2, J8.2, J9.2, R3.2, R7.2, R10.2, R18.2, R19.2, R21.2, U2.2 (SEL), U2.4 (CFG2), U2.8 (GND), U2.11 (GND), U3.2 (GND), U4.17 (GND), U4.18 (GND), U4.25 (GND), U5.2 (GND), U5.13 (EP), U6.1 (CTG), U6.4 (GND), U6.6 (QSTRT), U6.9 (EP); also elsewhere on the board
VSYS: C3.1, C8.1, C9.1, L2.2, U2.1 (EN), U2.10 (VIN), U4.15 (SYS), U4.16 (SYS); also elsewhere on the board

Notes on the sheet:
BQ25601 @ 0x6B: VAC tied to protected VBUS. PSEL pull-up goes to REGN (<7V), never 12V VBUS. R17 inhibits charging until firmware configures the cell and pulls CE low. R2/R3 require an external 10k pack NTC on J8 (not a fixed-temperature bypass). Program 14V charger OVP before requesting a 12V PD c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
MAX17048 @ 0x36 stays on the raw cell. BAT_SENSE = cell / 2; allow ADC settling for 1M divider. Gauge alert is open-drain. EP is connected to GND.
TPS63900: SEL=0, CFG3=16.2k gives 3V3. CFG1=36.5k, CFG2=0: 3V3 alternate setting / unlimited input mode. L1 >=2A saturation; verify effective Cout >=10uF at 3V3.
TCPP01: enable VCC, enable UCPD Rd, then release DB. No external CC Rd: the dead-battery clamp hands over to UCPD. R6/R7 set OVP about 13.5-15.1V; C30 is 50V X7R at U5. U3 pin 5 = 3V3 (USB data clamp), NEVER the 12V PD rail.
USB-C + NVDC POWER PATH / 3V3 / FUEL GAUGE

Board: 2 copper layers, 75 parts (0 on the bottom side), 65 nets, no tracks yet.

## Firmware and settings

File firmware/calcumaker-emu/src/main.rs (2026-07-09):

//! Calcumaker 16 emulator — the real calculator app on a host terminal.
//!
//! Runs the same `calcumaker_core::App` the firmware hosts: host keys map to
//! the 50-key matrix ([`HOST_KEYS`]), presses resolve through the f/g shift
//! layers, and the display is drawn from the **same TM1640 segment bytes** the
//! hardware would receive — rendered as ASCII 7-segment art.
//!
//! ```sh
//! cargo run                       # interactive (raw-mode) emulator
//! cargo run -- --press "2;3+"     # scripted: press keys, print the frame, exit
//! cargo run -- --prec 512         # working precision in bits
//! ```
//!
//! `;` (or a newline) is ENTER in `--press` scripts.

use std::io::{self, Write};

use calcumaker_core::keys::{COLS, ROWS};
use calcumaker_core::seg7::DIGITS_PER_ROW;
use calcumaker_core::App;

use crossterm::event::{Event, KeyCode, KeyEvent, KeyEventKind, KeyModifiers};
use crossterm::{cursor, event, execute, terminal};

/// Host key for each matrix cell (base-layer faces in the comments; f/g layers
/// are reached through `F` / `G` exactly like the device). `\x08` = Backspace,
/// `\n` = Enter.
#[rustfmt::skip]
/// Matrix cells with no switch (the 2U ENTER's upper half) get no host key.
const NO_KEY: char = '\0';

const HOST_KEYS: [[char; COLS]; ROWS] = [
    // sin  cos  tan  ln   sqrt y^x  1/x  EEX  back clx
    ['S', 'C', 'T', 'L', 'Q', 'P', 'I', 'E', '\x08', 'X'],
    // A    B    C    D    E    F    7    8    9    ÷
    ['a', 'b', 'c', 'd', 'e', 'f', '7', '8', '9', '/'],
    // and  or   xor  not  shl  shr  4    5    6    ×
    ['&', '|', '^', '~', '<', '>', '4', '5', '6', '*'],
    // hex  dec  oct  bin  x<>y (2U ENTER's upper half: no switch)  1  2  3  −
    ['H', 'D', 'O', 'B', 'x', NO_KEY, '1', '2', '3', '-'],
    // f    g    sto  rcl  R↓   ENT  0    .    chs  +
    ['F', 'G', 'm', 'r', 'v', '\n', '0', '.', 'n', '+'],
];

/// Matrix cell for a host key. `;` doubles as ENTER for shell-friendly scripts.
fn cell_for(ch: char) -> Option<(usize, usize)> {
    let ch = if ch == ';' { '\n' } else { ch };
    if ch == NO_KEY {
        return None; // never resolve to a cell that has no switch
    }
    for (r, row) in HOST_KEYS.iter().enumerate() {
        for (c, &key) in row.iter().enumerate() {
            if key == ch {
                return Some((r, c));
            }
        }
    }
    None
}

// TM1640 segment bits (see calcumaker_core::seg7): a b c d e f g dp.
const SEG_A: u8 = 0x01;
const SEG_B: u8 = 0x02;
const SEG_C: u8 = 0x04;
const SEG_D: u8 = 0x08;
const SEG_E: u8 = 0x10;
const SEG_F: u8 = 0x20;
const SEG_G: u8 = 0x40;
const SEG_DP: u8 = 0x80;

/// Rendering style for the 7-seg glass.
#[derive(Clone, Copy, PartialEq, Eq)]
enum Style {
    /// Unicode block elements — LED-like (default). 5 columns per digit.
    Block,
    /// Plain `_` / `|` — any terminal. 4 columns per digit.
    Ascii,
}

impl Style {
    fn digit_cols(self) -> usize {
        match self {
            Style::Block => 6,
            Style::Ascii => 4,
        }
    }
}

/// One display row of segment bytes as three lines of terminal art.
///
/// Block style, per digit: the top bar spans the full digit width so it meets
/// the corner posts, and the bottom bar falls back into the corner columns
/// when e/c are unlit — segments connect like real glass ('9.' below). The dp
/// is a lower-right quadrant in its own column (half a cell of air on its
/// left) followed by a gap column, so it never merges into a digit:
/// ```text
/// ▄▄▄▄     <- a
/// █▄▄█     <- f g b
/// ▄▄▄█ ▗   <- (d corner) d c, dp
/// ```
fn seg_art(row: &[u8; DIGITS_PER_ROW], style: Style) -> [String; 3] {
    let mut l: [String; 3] = Default::default();
    for &b in row {
        let on = |m: u8| b & m != 0;
        match style {
            Style::Block => {
                let bar = |m: u8| if on(m) { "▄▄" } else { "  " };
                // corner: full-height post, else the horizontal bar passes through
                let corner = |post: u8, bar: u8| {
                    if on(post) {
                        '█'
                    } else if on(bar) {
                        '▄'
                    } else {
                        ' '
                    }
                };
                l[0].push_str(if on(SEG_A) {
                    "▄▄▄▄  "
                } else {
                    "      "
                });
                l[1].push(if on(SEG_F) { '█' } else { ' ' });
                l[1].push_str(bar(SEG_G));
                l[1].push(if on(SEG_B) { '█' } else { ' ' });
                l[1].push_str("  ");
                l[2].push(corner(SEG_E, SEG_D));
                l[2].push_str(bar(SEG_D));
                l[2].push(corner(SEG_C, SEG_D));
                l[2].push(if on(SEG_DP) { '▗' } else { ' ' });
                l[2].push(' ');
            }
            Style::Ascii => {
                let seg = |m: u8, ch: char| if on(m) { ch } else { ' ' };
                l[0].push(' ');
                l[0].push(seg(SEG_A, '_'));
                l[0].push(' ');
                l[0].push(' ');
                l[1].push(seg(SEG_F, '|'));
                l[1].push(seg(SEG_G, '_'));
                l[1].push(seg(SEG_B, '|'));
                l[1].push(' ');
                l[2].push(seg(SEG_E, '|'));
                l[2].push(seg(SEG_D, '_'));
                l[2].push(seg(SEG_C, '|'));
                l[2].push(seg(SEG_DP, '.'));
            }
        }
    }
    l
}

/// Printable name for a host key.
fn host_key_name(ch: char) -> String {
    match ch {
        '\x08' => "Bks".into(),
        '\n' => "Ent".into(),
        c => c.to_string(),
    }
}

/// Help = the ACTIVE personality's key grid, rendered live from the same
/// tables the device uses (`keydoc::label`), with **the host key to press
/// inside each box**. Follows PErS switches automatically and can't drift.
fn help_text(app: &App) -> String {
    use calcumaker_core::keydoc::label;
    let km = app.keymap();

    // column width: widest of labels and bracketed host keys
    let mut w = 5; // "[Bks]"
    for layer in [&km.base, &km.f, &km.g] {
        for row in layer.iter() {
            for &k in row.iter() {
                w = w.max(label(k).len());
            }
        }
    }

    let mut out = format!(
        "PERSONALITY: {}   (each box: [key you press] / f gold / KEY FACE / g blue)\n\n",
        km.name
    );
    // A cell whose neighbour above has no switch merges into it — that's the 2U
    // ENTER, drawn as one tall box.
    let border = |below: Option<usize>| {
        let mut s = String::new();
        for c in 0..COLS {
            s.push('+');
            let merged = matches!(below, Some(r) if r > 0
                && !calcumaker_core::keys::cell_has_switch(r - 1, c));
            s += &(if merged { " " } else { "-" }).repeat(w + 2);
        }
        s.push('+');
        s.push('\n');
        s
    };
    for (r, host_row) in HOST_KEYS.iter().enumerate() {
        out += &border(Some(r));
        // host key line (a cell with no switch has no key to press)
        for (c, &host_key) in host_row.iter().enumerate() {
            let cell = if calcumaker_core::keys::cell_has_switch(r, c) {
                format!("[{}]", host_key_name(host_key))
            } else {
                String::new()
            };
            out += &format!("| {cell:<w$} ");
        }
        out += "|\n";
        for layer in [&km.f, &km.base, &km.g] {
            for &key in &layer[r] {
                out += &format!("| {:<w$} ", label(key));
            }
            out += "|\n";
        }
    }
    out += &border(None);
    out += "\nF/G = gold/blue shifts. STO/RCL: m or r, then a digit 0-f = the register.\n\
G+X = SETUP menu, F+X = STATUS view. Esc clears a pending shift.\n\
--personality 16C|15C|SCI|FIN (or SETUP > PErS). ? = help. Ctrl-C quits.\n";
    out
}

/// Render one full frame: 7-seg rows, annunciators, the untruncated X, the
/// mock aux OLED (unless the base --no-oled build), footer.
fn frame(app: &App, help: bool, style: Style, oled: bool) -> String {
    let mut out = String::new();
    let width = DIGITS_PER_ROW * style.digit_cols();
    let (tl, tr, bl, br, h, v) = match style {
        Style::Block => ('┌', '┐', '└', '┘', '─', '│'),
        Style::Ascii => ('+', '+', '+', '+', '-', '|'),
    };
    out.push_str("Calcumaker 16 - emulator\n");
    out.push_str(&format!("{tl}{}{tr}\n", h.to_string().repeat(width + 2)));
    let rows = app.seg_rows();
    for (i, row) in rows.iter().enumerate() {
        for line in seg_art(row, style) {
            out.push_str(&format!("{v} {line} {v}\n"));
        }
        if i + 1 < rows.len() {
            out.push_str(&format!("{v}{}{v}\n", " ".repeat(width + 2)));
        }
    }
    out.push_str(&format!("{bl}{}{br}\n", h.to_string().repeat(width + 2)));

    let c = app.calc();
    let pers = if app.keymap().name == "16C" {
        String::new()
    } else {
        format!("{}  ", app.keymap().name)
    };
    let radix = format!("{:?}", c.radix()).to_uppercase();
    let angle = match c.angle_mode() {
        calcumaker_core::AngleMode::Rad => "RAD",
        calcumaker_core::AngleMode::Deg => "DEG",
        calcumaker_core::AngleMode::Grad => "GRAD",
    };
    // number-type mode: FLEX is the quiet default; INT/REAL are announced
    let numty = match c.num_mode() {
        calcumaker_core::NumMode::Flex => "",
        calcumaker_core::NumMode::Int => "INT  ",
        calcumaker_core::NumMode::Real => "REAL  ",
    };
    let word = match c.word_bits() {
        Some(b) => {
            let mode = match c.sign_mode() {
                calcumaker_core::SignMode::Unsigned => "unsgn",
                calcumaker_core::SignMode::Ones => "1's",
                calcumaker_core::SignMode::Twos => "2's",
            };
            format!("word {b} {mode}")
        }
        None => "word unbounded".into(),
    };
    let mut flags = format!(
        "{}{}{}",
        if c.carry() { "  C" } else { "" },
        if c.overflow() { "  G" } else { "" },
        if c.leading_zeros() { "  LZ" } else { "" }
    );
    for i in 0..3 {
        if c.user_flag(i) {
            flags.push_str(&format!("  F{i}"));
        }
    }
    let fmt = match c.float_fmt() {
        calcumaker_core::FloatFmt::Auto => String::new(),
        calcumaker_core::FloatFmt::Fix(d) => format!("  FIX{d}"),
        calcumaker_core::FloatFmt::Sci(d) => format!("  SCI{d}"),
        calcumaker_core::FloatFmt::Eng(d) => format!("  ENG{d}"),
    };
    let shift = match app.shift() {
        Some(s) => format!("  [{s}]"),
        None => String::new(),
    };
    let reg = match app.pending_register() {
        Some(r) => format!("  {r} _"),
        None => String::new(),
    };
    let win = {
        let (w, total) = app.window();
        if total > 1 {
            format!("  win {}/{total}", w + 1)
        } else {
            String::new()
        }
    };
    let msg = match app.message() {
        Some(m) => format!("  << {m}"),
        None => String::new(),
    };
    out.push_str(&format!(
        " {pers}{radix}  {angle}  {numty}prec {}  {word}{flags}{fmt}{win}{shift}{reg}{msg}\n",
        c.prec()
    ));

    // The glass rounds to its 16 digits (HP-style); this line is the SHOW
    // view — X at full precision, where the arbitrary precision is visible.
    out.push_str(&format!(" X: {}\n", app.x_full()));

    // Mock of the DNP-optional aux OLED (128x32 = 4 lines x 21 chars): the
    // SAME App::aux_lines the firmware panel will draw. SETUP > OLEd toggles
    // the flags header.
    if oled {
        out.push_str(&format!(" ┌{}┐ aux OLED\n", "─".repeat(23)));
        for l in app.aux_lines() {
            out.push_str(&format!(" │ {l:<21} │\n"));
        }
        out.push_str(&format!(" └{}┘\n", "─".repeat(23)));
    }

    if help {
        out.push('\n');
        out.push_str(&help_text(app));
        out.push('\n');
    } else {
        out.push_str(" [?] keys   [Ctrl-C] quit\n");
    }
    out
}

fn draw(
    stdout: &mut impl Write,
    app: &App,
    help: bool,
    style: Style,
    oled: bool,
) -> io::Result<()> {
    execute!(
        stdout,
        terminal::Clear(terminal::ClearType::All),
        cursor::MoveTo(0, 0)
    )?;
    for line in frame(app, help, style, oled).lines() {
        write!(stdout, "{line}\r\n")?;
    }
    stdout.flush()
}

fn interactive(mut app: App, style: Style, oled: bool) -> io::Result<()> {
    let mut stdout = io::stdout();
    terminal::enable_raw_mode()?;
    execute!(stdout, terminal::EnterAlternateScreen, cursor::Hide)?;
    let mut help = false;

    let result = (|| -> io::Result<()> {
        draw(&mut stdout, &app, help, style, oled)?;
        loop {
            let Event::Key(KeyEvent {
                code,
                modifiers,
                kind,
                ..
            }) = event::read()?
            else {
                continue;
            };
            if kind == KeyEventKind::Release {
                continue;
            }
            if modifiers.contains(KeyModifiers::CONTROL)
                && matches!(
                    code,
                    KeyCode::Char('c') | KeyCode::Char('d') | KeyCode::Char('q')
                )
            {
                return Ok(());
            }
            match code {
                KeyCode::Char('?') => help = !help,
                // Esc cancels a pending shift by toggling that shift key again.
                KeyCode::Esc => match app.shift() {
                    Some('f') => app.press_key(calcumaker_core::Key::ShiftF),
                    Some('g') => app.press_key(calcumaker_core::Key::ShiftG),
                    _ => {}
                },
                KeyCode::Enter => feed(&mut app, '\n'),
                KeyCode::Backspace => feed(&mut app, '\x08'),
                KeyCode::Char(c) => feed(&mut app, c),
                _ => {}
            }
            draw(&mut stdout, &app, help, style, oled)?;
        }
    })();

    execute!(stdout, cursor::Show, terminal::LeaveAlternateScreen)?;
    terminal::disable_raw_mode()?;
    result
}

fn feed(app: &mut App, ch: char) {
    if let Some((r, c)) = cell_for(ch) {
        app.press(r, c);
    }
}

fn main() -> io::Result<()> {
    let mut prec = 256u32;
    let mut script: Option<String> = None;
    let mut style = Style::Block;
    let mut no_suffix = false;
    let mut oled = true;
    let mut personality: Option<&'static calcumaker_core::keys::Keymap> = None;

    let mut args = std::env::args().skip(1);
    while let Some(a) = args.next() {
        match a.as_str() {
            "--prec" => {
                prec = args
                    .next()
                    .and_then(|v| v.parse().ok())
                    .unwrap_or_else(|| usage("--prec needs a bit count"))
            }
            "--press" => {
                script = Some(
                    args.next()
                        .unwrap_or_else(|| usage("--press needs a key string")),
                )
            }
            "--ascii" => style = Style::Ascii,
            "--no-suffix" => no_suffix = true,
            "--no-oled" => oled = false,
            "--personality" => {
                let name = args
                    .next()
                    .unwrap_or_else(|| usage("--personality needs a name"));
                personality = Some(
                    calcumaker_core::keys::PERSONALITIES
                        .iter()
                        .find(|km| km.name.eq_ignore_ascii_case(&name))
                        .copied()
                        .unwrap_or_else(|| {
                            usage(&format!("unknown personality {name} (16C, 15C, SCI, FIN)"))
                        }),
                );
            }
            "--help" | "-h" => {
                println!(
                    "calcumaker-emu [--prec <bits>] [--press <keys>] [--ascii] [--no-suffix] [--no-oled] [--personality 16C|15C|SCI|FIN]\n"
                );
                let app = App::new(256);
                println!("{}", help_text(&app));
                return Ok(());
            }
            other => usage(&format!("unknown argument {other}")),
        }
    }

    let mut app = App::new(prec);
    // Seed RAN# from host entropy so it isn't the same sequence every launch
    // (the no_std core can't reach entropy itself). SEED still gives repeatable
    // runs on demand.
    let seed = std::time::SystemTime::now()
        .duration_since(std::time::UNIX_EPOCH)
        .map(|d| d.as_nanos() as u64)
        .unwrap_or(1);
    app.calc_mut().reseed(seed);
    if let Some(km) = personality {
        app.set_keymap(km);
    }
    if no_suffix {
        app.calc_mut().set_radix_suffix(false);
    }
    if let Some(s) = script {
        for ch in s.replace("\\n", "\n").chars() {
            feed(&mut app, ch);
        }
        print!("{}", frame(&app, false, style, oled));
        return Ok(());
    }
    interactive(app, style, oled)
}

fn usage(msg: &str) -> ! {
    eprintln!(
        "calcumaker-emu: {msg}\nusage: calcumaker-emu [--prec <bits>] [--press <keys>] [--ascii] [--no-suffix] [--no-oled] [--personality 16C|15C|SCI|FIN]"
    );
    std::process::exit(2);
}

#[cfg(test)]
mod tests {
    use super::*;
    use calcumaker_core::seg7;

    /// The decimal point must be visible: its glyph inks the right half of its
    /// own column (air on its left, toward the digit) and a gap column follows
    /// (air on its right, toward the next digit). Regression: 3.89 read as 389.
    #[test]
    fn block_dp_is_visible_and_separated() {
        let row = seg7::encode_row("3.89");
        let art = seg_art(&row, Style::Block);
        let bottom: Vec<char> = art[2].chars().collect();
        let i = bottom
            .iter()
            .position(|&c| c == '▗')
            .expect("dp glyph rendered");
        assert_eq!(bottom[i + 1], ' ', "gap column after the dp");
    }

    /// Every art line is exactly rows × digit_cols wide, both styles.
    #[test]
    fn art_width_matches_style() {
        for style in [Style::Block, Style::Ascii] {
            let row = seg7::encode_row("8.8");
            for line in seg_art(&row, style) {
                assert_eq!(
                    line.chars().count(),
                    seg7::DIGITS_PER_ROW * style.digit_cols()
                );
            }
        }
    }
}

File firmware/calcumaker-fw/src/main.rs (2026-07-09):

#![no_std]
#![no_main]

//! Calcumaker 16 firmware — MCU bring-up on **embassy-stm32** (STM32U575).
//!
//! Everything calculator lives in **`calcumaker-core`** (host-tested, emulated
//! by `calcumaker-emu`): the RPN engine over GMP + MPFR, the keymap + f/g shift
//! layers (`keys`), entry editing + dispatch (`App`), and the 7-seg encoding
//! (`seg7`). GMP/MPFR are cross-built for thumbv8m (firmware/scripts/) and
//! linked against the same FFI (`gmp-mpfr-nostd`); their C allocator
//! (malloc/free/realloc/calloc) is shimmed onto the Rust global heap below.
//!
//! Bring-up so far: 160 MHz clocks (`clock`), the arbitrary-precision engine
//! self-test (`selftest`), and USB (composite CDC-ACM REPL + HID keyboard,
//! `usb`). The keyboard matrix / TM1640 display are still stubs (`keypad`,
//! `display`) pending the board. See ../../DESIGN.md → firmware bring-up.

extern crate alloc;

use core::alloc::Layout;

use calcumaker_core::{App, Key};
use embassy_executor::Spawner;
use embassy_stm32::executor::Executor; // stm32 low-power executor (sleeps via low_power::sleep)
use embassy_time::Instant;
use static_cell::StaticCell;

// Panic handler + logger. Exactly one panic handler may be linked:
//   - production (default features): panic-halt (spin).
//   - `nucleo` validation target (--no-default-features --features nucleo):
//     panic-probe reports the panic over RTT, and defmt-rtt is the log sink.
#[cfg(feature = "panic-halt")]
use panic_halt as _;
#[cfg(feature = "nucleo")]
use {defmt_rtt as _, panic_probe as _};

// Logging shim: `log_info!` / `log_error!` map to defmt on the Nucleo target and
// compile to nothing otherwise, so the self-test payload (src/selftest.rs) is
// shared verbatim between the validation and production images. Defined before
// the modules that use them so they are in textual scope.
#[cfg(feature = "nucleo")]
macro_rules! log_info { ($($t:tt)*) => { ::defmt::info!($($t)*) }; }
#[cfg(not(feature = "nucleo"))]
macro_rules! log_info {
    ($($t:tt)*) => {{}};
}
#[cfg(feature = "nucleo")]
macro_rules! log_error { ($($t:tt)*) => { ::defmt::error!($($t)*) }; }
#[cfg(not(feature = "nucleo"))]
macro_rules! log_error {
    ($($t:tt)*) => {{}};
}

mod bootloader;
mod clock;
mod display;
mod keypad;
mod selftest;
mod usb;

// TLSF (vs LLFF) handles the variable-size bignum allocation churn with less
// fragmentation; GMP allocates here via the C shim below.
use embedded_alloc::TlsfHeap as Heap;

#[global_allocator]
static HEAP: Heap = Heap::empty();

/// Heap backing the arbitrary-precision allocator. Provisional — size against
/// the chosen working precision (DESIGN.md → Numeric core).
const HEAP_SIZE: usize = 64 * 1024;

fn init_heap() {
    use core::mem::MaybeUninit;
    static mut HEAP_MEM: [MaybeUninit<u8>; HEAP_SIZE] = [MaybeUninit::uninit(); HEAP_SIZE];
    // SAFETY: called exactly once, before any allocation.
    unsafe { HEAP.init(core::ptr::addr_of_mut!(HEAP_MEM) as usize, HEAP_SIZE) }
}

// ---------------------------------------------------------------------------
// C heap shim: GMP/MPFR call libc malloc/free/realloc/calloc. Back them with
// the Rust global allocator (embedded-alloc), so the bignum heap is the single
// heap. We stash the block's total size in a 16-byte header (>= max_align) so
// free()/realloc() can reconstruct the Layout.
// ---------------------------------------------------------------------------
const HDR: usize = 16;

unsafe fn c_alloc(size: usize) -> *mut u8 {
    let n = if size == 0 { 1 } else { size };
    let total = n + HDR;
    let layout = Layout::from_size_align_unchecked(total, HDR);
    let p = alloc::alloc::alloc(layout);
    if p.is_null() {
        return p;
    }
    (p as *mut usize).write(total);
    p.add(HDR)
}

#[no_mangle]
pub unsafe extern "C" fn malloc(size: usize) -> *mut u8 {
    c_alloc(size)
}

#[no_mangle]
pub unsafe extern "C" fn free(ptr: *mut u8) {
    if ptr.is_null() {
        return;
    }
    let base = ptr.sub(HDR);
    let total = (base as *mut usize).read();
    alloc::alloc::dealloc(base, Layout::from_size_align_unchecked(total, HDR));
}

#[no_mangle]
pub unsafe extern "C" fn realloc(ptr: *mut u8, size: usize) -> *mut u8 {
    if ptr.is_null() {
        return c_alloc(size);
    }
    if size == 0 {
        free(ptr);
        return core::ptr::null_mut();
    }
    let base = ptr.sub(HDR);
    let old_total = (base as *mut usize).read();
    let new_total = size + HDR;
    let np = alloc::alloc::realloc(
        base,
        Layout::from_size_align_unchecked(old_total, HDR),
        new_total,
    );
    if np.is_null() {
        return np;
    }
    (np as *mut usize).write(new_total);
    np.add(HDR)
}

#[no_mangle]
pub unsafe extern "C" fn calloc(nmemb: usize, size: usize) -> *mut u8 {
    let total = nmemb.checked_mul(size).unwrap_or(0);
    let p = c_alloc(total);
    if !p.is_null() {
        core::ptr::write_bytes(p, 0, total);
    }
    p
}

/// GMP calls `abort()` on internal errors (the engine guards against these).
#[no_mangle]
pub extern "C" fn abort() -> ! {
    loop {
        cortex_m::asm::udf();
    }
}

/// All allocation is routed through the Rust global heap (the malloc shim
/// above), so newlib's sbrk-based heap is never used. Overriding `_sbrk` here
/// keeps newlib's `sbrk.o` (which needs the linker's `end` heap marker) out of
/// the image. Never actually called; returns the sbrk failure value.
#[no_mangle]
pub extern "C" fn _sbrk(_incr: isize) -> *mut u8 {
    usize::MAX as *mut u8 // (void*)-1
}
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

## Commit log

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2026-06-22 Display board: TM1640 + FJ5161AH BOM (chosen by LCSC availability)
    Fold in the display part-selection research and rework the interconnect for the
    TM1640's 2-wire bus.
    - Driver: 3× TM1640 (LCSC C5337152) — 1 chip drives a full 16-digit common-
    cathode row (2-wire); 3 rows total. ~20× cheaper than a MAX7219 cascade.
    - Digits: 12× FJ5161AH 0.56" 4-digit common-cathode (LCSC C8093), 4 per row.
    Caveat: through-hole — no SMD multi-digit 7-seg stocked on LCSC; display board
    needs THT assembly.
    - Interconnect: 1×8 2.54mm header (PZ254V-11-08P, LCSC C492407), pinout
    3V3/GND/CLK/DIN1/DIN2/DIN3 (+GND/spare). Replaces the earlier SPI assumption.
    - New hardware/PARTS.md (per-board BOM s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
    [calcumaker-display.schgen.py, calcumaker-main.schgen.py]
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2026-06-22 5V-rail BOM (TPS61022 + SN74HCT125) + 0402/0603 passive & small-magnetics policy
    Sourced via the LCSC/jlcsearch skill, applying the 0402-passives / smallest-
    reasonable-magnetics directive:
    - 5V boost: TPS61022RWUR (C915088, EN-gated, VQFN-7) + FB divider (732k/100k→5V)
    + 1µH FTC201610S1R0MBCA (C5832342, 2.0×1.6mm) + 0603 caps (10µF in, 2×22µF out).
    - Level shifter: SN74HCT125DR (C352957); KiCad symbol = stock 74xx:74AHCT125
    (pin-identical), value 74HCT125; footprint Texas_RWU0007A_VQFN-7 confirmed for
    the boost (its symbol is a TODO, batched with the MCU symbol).
    - Passive policy: 0402 for R + decoupling; 0603 for bulk MLCCs (true-0402 10µF is
    6.3V-only, too low for 5V). 3V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
    [calcumaker-display.kicad_sch, display.kicad_sch, interconnect.kicad_sch]
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2026-06-22 Remove partial main-board sheets leaked by an incomplete gen
    A manifest test run wrote mcu/psu/keypad.kicad_sch but aborted at the not-yet-
    authored TPS61022 symbol, so there's no root sheet — an inconsistent set. Remove
    them; the main board's sheets will be committed once it generates end-to-end
    (after the MCU sheet + TPS61022 symbol are in).
    [keypad.kicad_sch, mcu.kicad_sch, psu.kicad_sch]
2026-06-22 Main board: per-component subsheets, fully generated + checked
    Decompose the main board into six per-component hierarchical subsheets and
    generate it end-to-end (both symbols turned out to be stock KiCad — TPS61022 in
    Converter_DCDC, STM32U575ZGTx in MCU_ST_STM32U5 — so no custom authoring).
    Subsheets: MCU (U1 STM32U575ZGTx + VDD/VDDA/VDDUSB decoupling + VCORE + NRST/
    BOOT0), Clock (LSE 32.768kHz Y1 + load caps), Programming (SWD Tag-Connect J4),
    PSU, Keypad (50 SW + 50 diodes), DisplayIF (TPS61022 + 74HCT125 + J3).
    - Globally-unique refs across all sheets (no collisions): MCU C12-23/R8/U1,
    Clock C24-25/Y1, Prog J4; PSU/Keypad/DisplayIF unchanged.
    - `make check-calcumaker-main`: 149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
    [calcumaker-main.kicad_sch, clock.kicad_sch, display_if.kicad_sch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]
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2026-07-02 Add a host CLI emulator target (calcumaker-emu) + move the device UI into the core
    The whole device-independent calculator now lives in calcumaker-core so the
    emulator and the firmware are thin I/O bindings around one code path:
    - calcumaker-core/keys: the 50-key matrix keymap + f/g shift layers moved here
    from calcumaker-fw (design source of truth), with the shift-resolution state
    machine (keys::Shift).
    - calcumaker-core/app: App = key handling over the engine — HP-style
    digit-by-digit entry (live _ cursor, backspace, EEX, CHS flips
    mantissa/exponent sign in-entry), flush-on-operation, CLx/ENTER semantics,
    error -> status message, and display rows as text or TM1640 segment byte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
    [keypad.rs]
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2026-07-02 Glass rounds to the window (HP-style) + connected 7-seg corners
    - format_fit: AUTO-mode reals are display-rounded (correctly, by MPFR) to the
    largest digit count that fits the 16-cell row — 382.1 shows as 382.1, not
    382.09999… spilling off the glass; exponent-bound values force scientific
    at maximal digits (1.2345e17). The register keeps full precision: new
    App::x_full() is the SHOW view (emulator X: line). Integers and explicit
    FIX/SCI/ENG still overflow-mark.
    - Block art: the top bar spans the full digit width and the bottom bar passes
    through unlit corner posts, so segments connect like real glass — no more
    chopped tops on 9/3/7.
    84 tests green.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
    [main.rs]
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2026-07-02 Engine: 16C integer square root — sqrt on an Int is exact floor root + carry
    sqrt(Int) = mpz_sqrt (17 sqrt -> 4) with the carry flag = 'root was inexact';
    negative integers error without consuming X; reals unchanged (2.0 sqrt or
    'float' first for the real root). C/G annunciators now show whenever set (the
    carry from an inexact root exists outside word mode too). Docs/examples moved
    to 2.0-sqrt where the real root was meant.
    [main.rs]
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2026-07-02 Engine: DBL× / DBL÷ / DBLR double-word ops (16C)
    dbl* computes the full 2n-bit product of Y×X and splits it high→Y / low→X
    (decoded per the sign mode, so enc(Y)·2^n + enc(X) reconstructs the pattern —
    never overflows). dbl/ and dblr divide the double dividend Z(high):Y(low) by
    X; a quotient that doesn't fit the word errors WITHOUT consuming operands
    (16C Error 0) while dblr always fits. Word mode only, validation-first.
    Keys: f-4/5/6.
    [main.rs]
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2026-07-02 App/engine: display windowing (16C < / >) — scroll long values, no digit lost
    g-shift SL/SR scroll X through 16-cell windows when it exceeds the row:
    window 0 is the fitted view (15 cells + overflow marker) and window k >= 1
    starts exactly where the marker cut off — a reassembly test proves every cell
    is reachable (the first geometry dropped cell 15 between windows; caught
    while verifying). Any non-window key resets the view; 'win k/N' annunciator
    whenever X overflows. seg7 gains encode_cells (shared by fitted rows and
    windows). Also: DESIGN/README sweep for the tier-B ops.
    [main.rs]
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2026-07-02 App: f-STATUS momentary view (16C STATUS) on the glass
    f-shift CLx shows three rows of 7-seg-renderable status text until the next
    key: 'bASE 16 2S rAd' (radix base, sign mode, angle unit), 'P256 b8'
    (precision bits, word bits, b0 = unbounded), 'AUtO 010000' (real format +
    the six flags as bits 543210 = G C lz F2 F1 F0). Every character is checked
    renderable by test; spellings avoid the impossible 7-seg letters (X, W, Z).
    Left-aligned, resets the display window, restores the stack view on any key.
    The emulator shows it through the normal glass pipeline (--press '...FX').
    [main.rs]
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2026-07-02 App: SETUP settings menu (g-CLx) — runtime configuration on the glass
    Interactive menu: 'SEtUP' / '<n> <name>' / '<value>' rows; R-down/R-up
    navigate, ENTER cycles the value, CLx/Backspace/SETUP exits, other keys are
    swallowed with a hint (nothing reaches the engine — ClrX exits instead of
    dropping X). Items: SUFF (the radix letter finally has a keypad path),
    LEAd 0, AnGLE, SIGn — 7-seg-renderable names enforced by test; numeric
    settings (prec/wsize/FIX digits) stay RPN-postfix by design. The menu
    mutates Calc through the same setters the tokens use.
    DESIGN-MODES.md revised per review: runtime personality switching happens on
    HARDWARE too, via a future PErS entry in this same menu (bo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
    [main.rs]
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2026-07-02 SCI personality is real: keymap, defaults bundle, PErS switch, --personality
    keys::SCI (15C-flavored): digits/ENTER/shifts/arithmetic/STATUS/SETUP at
    the identical physical positions as 16C (muscle memory carries); hex row ->
    inverse trig + log10/e^x/10^x; bitops row -> Sigma+/Sigma-/mean/sdev/x!/%;
    radix row -> FIX/SCI/ENG/auto/angle-mode; f = hyperbolics + L.R./yhat/r/
    CLstat; g = nCr/nPr/RAN#/seed + the shared window keys.
    Keymap::apply_defaults per personality (SCI: DEG + FIX 4 + Dec; 16C: RAD +
    AUTO — data never touched); PErS now genuinely cycles 16C <-> SCI; emulator
    --personality 16C|SCI + a personality annunciator; help documents the SCI
    faces. New keymap-dispatchability test swe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
    [main.rs]
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2026-07-02 Emulator: help renders the ACTIVE personality's key grid, not static text
    The '?' overlay (and --help) now shows keydoc::render(app.keymap()) — the
    same generated grid as doc/keymap-*.txt, live for the current personality
    (follows PErS switches) — plus the fixed host-key legend and a short hint
    footer. The hand-maintained help blob (a drift hazard the design doc had
    flagged) is gone.
    [main.rs]
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2026-07-02 Emulator: host key shown inside every help-grid box
    Each box now reads [key you press] / f / KEY FACE / g, built emulator-side
    from HOST_KEYS + keydoc::label — the separate host-key legend block (a
    triplicated drift hazard flagged in review) is gone.
    [main.rs]
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2026-07-02 Number-type mode: flexible / int / real — a proper 16C int mode as a setting
    Per review discussion: NumMode { Flex, Int, Real } replaces the real_entry
    bool. FLE (flexible, DEFAULT) = what we shipped: exact quotient stays exact
    Int, inexact promotes to real — never silent truncation. Int = the proper
    16C integer mode as a setting: division truncates and sets Carry on an
    inexact quotient, unbounded included. rEAL = the float machine (SCI/FIN
    default; decimal digits parse as reals). Word-size mode truncates regardless
    (its own 16C semantics).
    16C-faithful switching: the FLOAT key now ENTERS real mode (converting X —
    closes the documented deviation); a radix key exits real mode back to
    f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
    [main.rs]
2026-07-02 Error handling: HP-style glass codes + DNP-optional aux OLED (display board)
    Two layers, per design discussion:
    ENGINE/APP — CalcError restructured: TypeError(&str) becomes Op(code, msg)
    with class constructors at every site; code() gives the HP-16C-style glass
    class (0 math domain, 1 register/flag, 2 bits/shift/word, 3 mode ranges,
    4 too large, 5 no solution, 6 stack/entry, 7 dates, 8 statistics, 9 reserved
    for crash recovery), text() the full string. App shows a transient 'Error N'
    on the X row (cleared by the next key, like SHOW) and keeps the full text on
    the status line — the duplicated error-string mapping in run_owned/flush is
    now one report() helper. All of 'Error N' renders on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
    [annunc.kicad_sch, aux.kicad_sch, calcumaker-display.kicad_sch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]
2026-07-02 Aux OLED shows status flags (optional): App::aux_lines + emulator mock panel
    App::aux_lines() is the canonical aux-OLED content — 4 lines x 21 chars
    (128x32, 6x8 font), one code path for the firmware panel and the emulator:
    an optional status-flags header (personality/radix/angle/number-mode;
    prec/word/sign/C/G/format/shift/pending-reg) followed by the error text or,
    when idle, the FULL-PRECISION X (so the OLED doubles as the windowing
    helper). The header is a runtime tunable: SETUP item 8 'OLEd' (FLAG/oFF,
    default on), living on App like PErS. The emulator now draws the mock OLED
    panel under the glass (--no-oled mimics the base DNP build). 212 host tests.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
    [main.rs]
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2026-07-06 firmware: cross-compile + link the full engine (GMP/MPFR) for thumbv8m (#2)
    Resolves the "GMP/MPFR on the target — final newlib link" open item. The
    calcumaker-fw board binary now links the whole calculator engine (calcumaker-
    core over the cross-built GMP + MPFR) for the STM32U575 (Cortex-M33,
    thumbv8m.main-none-eabihf).
    - Cargo.toml: enable the calcumaker-core dependency.
    - main.rs: shim GMP/MPFR's C allocator (malloc/free/realloc/calloc) onto the
    Rust embedded-alloc heap (a single bignum heap), stub abort/_sbrk, and add a
    smoke `main` that EXERCISES every engine operation (all ~150 Calc tokens + a
    full key/shift sweep + the display/format/7-seg paths) so nothing is
    dead-strippe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
    [main.rs]
2026-07-06 hardware: MCU -> STM32U575RGT6 (LQFP-64) + 4MB QSPI flash; monospace wiring notes (#3)
    MCU package + external flash
    - Swap U1 STM32U575ZGT6 (LQFP-144) -> STM32U575RGT6 (LQFP-64, LCSC C5270980).
    The firmware links at ~323 KB so 1 MB flash is ample (~3x headroom), and with
    the key matrix scanned off-board the LQFP-64 has enough GPIO — smaller/cheaper.
    - Correct the flash size everywhere: the STM32 `G` code = 1 MB (not 2 MB; the
    `I` parts are 2 MB). memory.x FLASH 2048K -> 1024K; .cargo runner -> RGTx.
    - Add U7 W25Q32JVSSIQ, a 4 MB (32 Mbit) quad-SPI NOR (LCSC C179173, SOIC-8) on
    OCTOSPI1 as a new QSPIFlash sheet (+ R9 CS# pull-up + C26 decoupling) for
    memory-mapped (XIP) constants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
    [annunc.kicad_sch, aux.kicad_sch, calcumaker-display.kicad_sch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]
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2026-07-07 hardware: keyswitch 3D models, hot-swap footprint, reverse-mount per-key RGB (#6)
    Physical build-out of the keyboard: real switch 3D, a hot-swap footprint, and a
    single-sided-assembly LED choice.
    - 3D models (vendored, hardware/lib/3dmodels): SW_Cherry_MX_1.00u_PCB.step from
    kiswitch/kiswitch (MIT) -- KiCad's Button_Switch_Keyboard.3dshapes does not
    exist in packages3D upstream, so there's nothing to install/download from
    KiCad -- plus HS_CPG151101S11_MX.step (socket) from marbastlib (CERN-OHL-P).
    Also vendor a plain solder-in SW_Cherry_MX_1.00u_PCB.kicad_mod (fallback).
    - Keyswitch footprint -> marbastlib SW_MX_HS_CPG151101S11_1u (CERN-OHL-P): the
    Kailh CPG151101S11 hot-swap soc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
    [annunc.kicad_sch, calcumaker-keyboard.kicad_sch, kbd_mcu.kicad_sch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]
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2026-07-07 firmware: Nucleo-U575ZI-Q validation target (on-target engine self-test over RTT)
    Add a permanent, non-production validation target: the same firmware flashed to
    an off-the-shelf Nucleo-U575ZI-Q (STM32U575ZIT6Q), running a shared engine
    self-test whose golden results were captured from the host engine. Proves the
    cross-built on-target GMP/MPFR reproduces host results byte-for-byte (incl.
    factorial(100) and 256-bit MPFR pi/sqrt2) — the whole arbitrary-precision stack
    computes correctly on real U5 silicon. Verified 15/15 PASS on hardware.
    - src/selftest.rs: shared golden-case runner (compiled into both images; output
    compiled out in production via the log_info!/log_error! shim in main.rs)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
    [main.rs]
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2026-07-07 firmware: MCU bring-up on embassy — 160 MHz clocks, USB composite (CDC-ACM REPL + HID keyboard), low-power executor
    Move calcumaker-fw onto embassy-stm32 (async) and bring up the U575, validated
    end-to-end on the Nucleo-U575ZI-Q.
    - clock.rs: 160 MHz SYSCLK (PLL1-R/HSI), crystal-free 48 MHz USB clock
    (HSI48 + CRS trimmed to USB SOF), LSI for the RTC. Board-independent.
    - usb.rs: OTG_FS IAD composite device. CDC-ACM = a live RPN REPL over the real
    calcumaker_core engine; HID keyboard = `type` taps the current X to the host.
    Verified: enumerates as 1209:c160 (CDC + HID), REPL returns correct results
    (incl. 256-bit MPFR and factorial(100)), HID emits the right keycodes.
    - main.rs: asy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
    [keypad.rs, main.rs]
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2026-07-07 firmware: low-power tick-hz-32768 (embassy#3504) + STOP validation harness
    The U5 RTC-backed deep-STOP path is already in embassy-stm32 0.6 (time-driver-any
    + low-power + config.rtc, auto-wired by embassy_stm32::init); the earlier
    "needs a fork" conclusion was a misdiagnosis (the LPTIM time driver — a different,
    U5-broken path — was the red herring). The only real gotcha is embassy#3504:
    with the default 1 MHz tick the U5 low-power driver miscalculates STOP durations;
    tick-hz-32_768 (matching the LSI/RTC granularity) fixes it. Validated: no USB/REPL
    regression under the 32 kHz tick.
    - embassy-time: tick-hz-32_768.
    - `stop-demo` feature: skip USB (whose OTG Stop1 refcount would pin the p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
    [main.rs]
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2026-07-07 firmware: USB-C field updates via STM32 ROM DFU (option-byte entry) — no ST-Link
    Single flash slot (app owns 0x08000000+), no custom bootloader, no A/B. Verified
    end-to-end on the Nucleo-U575ZI-Q: a firmware change flashed over USB-C alone
    (product string bring-up -> DFU-updated -> bring-up), app rebooting each time.
    - bootloader.rs: `enter_rom_dfu()` programs the boot option bytes
    (nSWBOOT0=0/nBOOT0=0) + OBL_LAUNCH, resetting straight into the ROM USB-DFU
    device (0483:df11). The naive jump to system memory 0x0BF90000 HardFaults on
    the U5 (reads as 0 even with TrustZone off / RDP 0); the RM-defined boot-pattern
    entry is what works. The `dfu` REPL command calls it.
    - scripts/dfu-fl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
    [main.rs]
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2026-07-08 core: complex numbers pt.2 — CPXRES-promoting transcendentals (HP-42S)
    Scientific functions are now complex-aware.
    - gmp-mpfr-nostd: MPC bindings for sinh/cosh/tanh/asin/acos/atan/log10 + ui_div
    (reciprocal); Float::is_negative()/cmp_si() (+ mpfr_cmp_si).
    - calc: `cunary` helper — a complex X uses the complex fn; a real X that "goes
    complex" under CPXRES is promoted (√-4→2i, ln(-1)→iπ, asin(2)→complex,
    (-8)^(1/3)→1+i√3); else the real fn. Wired sqrt/ln/log/exp/inv/sinh/cosh/tanh
    and sin/cos/tan/asin/acos/atan (complex trig in radians for now) + pow/exp10.
    REALRES keeps the real path (√-4 = NaN).
    - Removed the now-superseded unary_real.
    Verified: host suite gree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
    [main.rs]
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2026-07-08 hardware: unified SPI display-module interface + RGB dot-matrix board
    Make the display a swappable module on ONE technology-agnostic connector
    (mirrors the keyboard-G0 pattern): the MCU board speaks a single SPI
    "display intent" bus and each display board carries its own MCU that
    renders locally. Two interchangeable modules on the same 12-pin FFC.
    - calcumaker-matrix (NEW): full-color RGB dot matrix, 96x24 = 2304x 1mm
    XL-1010RGBC-2812B-S (C51900942) driven by an RP2040 (PIO). Nested
    multi-channel: led_cluster (8x8) x12 -> led_row (768px chain) x3.
    Dedicated VSYS LED-power inlet keeps amps off the signal FFC. Authored
    the 1mm 1010 footprint; RP2040/flash/shifter symbols are stock.
    -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
    [aux.kicad_sch, calcumaker-display.kicad_sch, calcumaker-matrix.kicad_sch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]
2026-07-08 firmware: scaffold the two display-module targets + wire the module sheets
    Firmware scaffold (all build; targets thumbv6m-none-eabi):
    - calcumaker-display-proto: shared no_std wire protocol — the "display intent"
    DisplayFrame the U575 sends over SPI (text rows + flags + aux), with a
    fixed-length checksummed codec. Host-tested (cargo test: 3/3).
    - calcumaker-display-fw: 7-seg module (STM32G031, embassy-stm32) — SPI-slave
    receiver + a bit-bang TM1640 driver + 7-seg render.
    - calcumaker-matrix-fw: RGB-matrix module (RP2040, embassy-rp) — SPI-slave
    receiver + a 96x24 framebuffer/font blitter; WS2812 PIO output + SPI DMA
    stubbed as the bring-up TODOs.
    Wire the one-off module sche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
    [aux.kicad_sch, calcumaker-display.kicad_sch, calcumaker-matrix.kicad_sch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]
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2026-07-09 fix: seed RAN# at startup so it varies (was the same sequence every launch)
    The PRNG started from a fixed constant and no frontend reseeded it, so `ran`
    replayed the identical sequence on every emulator/REPL launch. The no_std core
    can't reach entropy itself, so expose Calc::reseed(u64) (splitmix64-expanded,
    shared with the SEED command) and call it from each frontend:
    - emulator + host REPL: wall-clock nanoseconds
    - firmware: the 96-bit device UID mixed with the boot tick (hardware RNG is the
    production upgrade for true per-boot entropy)
    SEED still gives reproducible runs on demand; a bare Calc stays deterministic
    (tests unaffected). Note: `mean` isn't a bug — accumulate data with Σ+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
    [main.rs]
2026-07-09 keys: ENTER becomes a 2U (double-height) key — 49 keys, row 3 loses a switch
    The 1U ENTER was too small. ENTER now spans rows 3-4 of column 5 as a 2U keycap
    with a single switch in the LOWER cell, so ENTER keeps its matrix position and
    the firmware scan is unchanged. The upper cell carries no switch (2U stabilizer
    instead) and is the new Key::Absent in every layer of every personality —
    distinct from Key::Nop (a real key with no function). 50 -> 49 keys.
    Displaced functions, identical across all four personalities:
    - x<>y moves onto the base layer at (3,4) (it's core RPN, stays unshifted)
    - the mode key it displaced there moves to f+ENTER:
    16C = WSIZE, SCI/15C = ANGLE, FIN = %T
    - FL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
    [main.rs]
2026-07-09 hw: keyboard 9-key row variant for the 2U ENTER (49 keys)
    Follows the firmware-side 2U ENTER change (4dee351). The 5x10 matrix is no longer
    five identical rows, so the multi-channel keyboard schematic can't instantiate one
    sheet five times:
    - key_row.kicad_sch -> now instantiated 4x (Row1, Row2, Row3, Row5)
    - key_row_9.kicad_sch -> NEW, instantiated 1x for Row4: 9 keys, no switch/diode/
    RGB LED at COL6 (that cell is the upper half of the 2U ENTER cap; its single
    switch lives in Row5/COL6, with a 2U stabilizer above).
    build_key_row() is now parameterized by (columns present, instances, uuid, file,
    page, title, note). Reference numbering keeps a hole rather than renumbering — no
    SW36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
    [calcumaker-keyboard.schgen.py]
2026-07-09 hw/docs: 2U ENTER stabilizer options + correct the switch's physical position
    Investigated the stabilizer footprint question. Findings recorded in DESIGN.md:
    - KiCad 10 ships the part: Button_Switch_Keyboard:SW_Cherry_MX_2.00u_Vertical_PCB
    (and _Plate). marbastlib is NOT installed here -- we only ever vendored its one
    hot-swap 1u footprint.
    - The _Plate variant has an IDENTICAL pad/hole set to the 1u plate footprint
    (verified by diff): plate-mount stabilizers clip into the plate we already need
    for the hot-swap sockets, so the PCB needs NO stabilizer holes and ENTER simply
    reuses calcumaker:SW_MX_HS_CPG151101S11_1u. Recommended.
    - If PCB-mount stabs are preferred instead, the patt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
    [calcumaker-keyboard.schgen.py]
2026-07-09 hw: regenerate keyboard for the 2U ENTER + vendor the 2U hot-swap footprint
    Board files now reflect the 2U ENTER (49 keys):
    - key_row.kicad_sch -> 4 instances (Row1/2/3/5), 30 symbols
    - key_row_9.kicad_sch -> NEW, 1 instance (Row4), 27 symbols: no switch, diode
    or RGB LED at COL6; refs keep a hole (no SW36/D36/D91)
    - root note + rgb_power note updated (49 LEDs, Row4 has 9)
    check-calcumaker-keyboard: 176 components (3 fewer), 176/176 footprints assigned,
    no duplicate refs, structure sound. Regeneration verified safe first by running the
    generator against a scratch copy: the one-off sheets (annunc/kbd_mcu/main_if)
    rebuild byte-identical modulo uuids, i.e. n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
    [annunc.kicad_sch, calcumaker-keyboard.kicad_sch, kbd_mcu.kicad_sch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]
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2026-07-09 hw: assign the OCTOSPI1 pinout and fold Clock/Prog/DisplayIF into MCU
    The MCU sheet carried a "verify OCTOSPI1 pin mapping is available on
    LQFP-64" TODO and the flash sheet said to assign it "to the PB/PC bank".
    Both are now settled, and the PB/PC hint was wrong.
    On the U5 the OCTOSPI GPIOs belong to the OCTOSPI I/O manager, so the AF
    signals are OCTOSPIM_P1_*/P2_*. LQFP-64 bonds out no Port-2 bus at all
    (ports E/F/G absent; only P2_NCS is present), so Port 1 is mandatory —
    and on Port 1 IO0..IO3 each have exactly one candidate pin. Only CLK
    (PA3|PB10) and NCS (PA2|PA4|PC11) were a real choice:
    CLK PB10 AF10 p29 IO0 PB1 AF10 p27 IO2 PA7 AF10 p23
    NCS PA4 AF3 p20 IO1 PB0 AF10 p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
    [calcumaker-mcu.kicad_sch, clock.kicad_sch, display_if.kicad_sch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]
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

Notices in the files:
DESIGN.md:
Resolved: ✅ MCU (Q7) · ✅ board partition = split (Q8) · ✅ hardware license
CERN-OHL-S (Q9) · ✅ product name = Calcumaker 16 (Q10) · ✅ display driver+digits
